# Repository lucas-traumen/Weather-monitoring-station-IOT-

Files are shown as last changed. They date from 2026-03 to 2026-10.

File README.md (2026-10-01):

# Local Weather Monitoring Station

A local weather station for sites where a regional forecast does not describe the microclimate at the sensor. An STM32 node measures the environment, encrypts the reading, and sends it over LoRa. An ESP32-S3 gateway decrypts it, forecasts the temperature two hours ahead, and stores the result in Supabase.

**Team:** Nguyễn Thái Anh (23139002), Lê Đức Trí (23139049)
**Supervisor:** Dr. Huỳnh Thế Thiện, HCMC University of Technology and Education
**Report:** [report/23139002_23139049.pdf](report/23139002_23139049.pdf)

## What it does

Regional stations miss differences caused by vegetation, concrete, elevation, and shielding. This station measures temperature, humidity, pressure, and supply status at the installation point, then keeps that record available when the gateway has Wi-Fi.

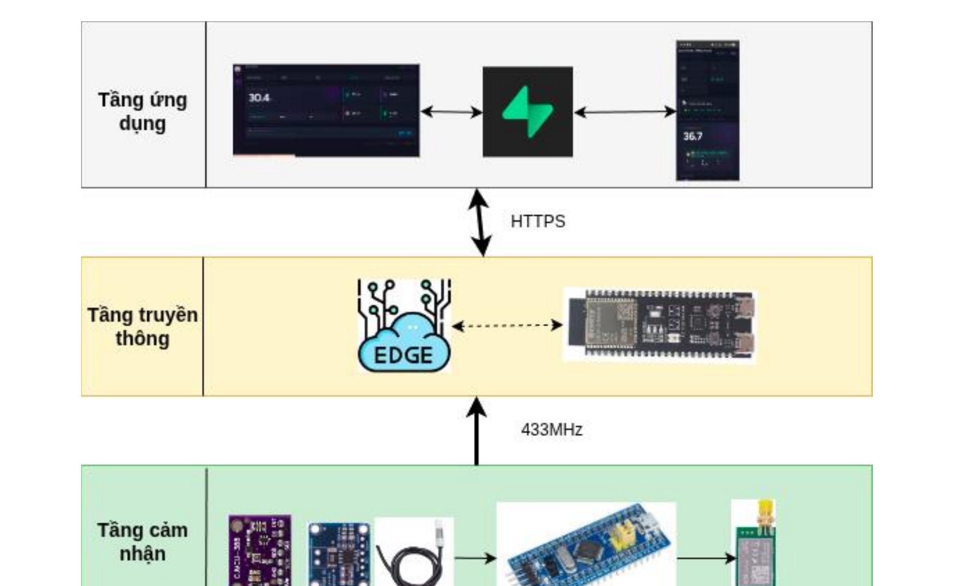
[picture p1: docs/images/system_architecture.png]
Figure 2.1. Three-tier architecture: sensing, communication, application


*Figure 2.1. System architecture. Sensing at 433 MHz, gateway at the edge, application tier over HTTPS.*

| Tier | Role |
| --- | --- |
| STM32F103C8T6 node | Read SHT30, BMP388, and INA219; pack a 10-byte payload; encrypt it; transmit one LoRa frame per cycle |
| ESP32-S3 gateway | Authenticate and decrypt the frame, run the forecast, re-encrypt, and POST to Supabase |
| Supabase | Decrypt in an Edge Function, store rows in PostgreSQL, and serve the dashboard and OTA metadata |

The outdoor link uses ASCON-128a with a 4-byte authentication tag so the frame stays small. The gateway-to-cloud link uses a second key and a 16-byte tag. A leaked LoRa key does not expose the cloud key.

## Run the dashboard

The dashboard is static HTML. It reads rows that the Edge Function has already decrypted.

```bash
cd Software/iot-dashboard
python3 -m http.server 8080
```

Open `http://localhost:8080`. In **Config**, set the Supabase URL and table (`weather_logs`). The browser does not hold the ASCON key.

## Build the firmware

**Gateway** — ESP-IDF project `esp32_gateway`, target ESP32-S3. The managed provisioning component supports ESP-IDF 5.1 through 5.5 and 6.x; use an installed 5.x toolchain unless you have confirmed 6.x.

```bash
cd firmware/esp32
idf.py set-target esp32s3
idf.py build flash monitor
```

**Sensor node** — STM32CubeIDE project generated with STM32CubeMX 6.14.1 and STM32Cube FW_F1 V1.8.7.

```bash
# Open firmware/stm32/node_stm32_ver1 in STM32CubeIDE and build the Debug configuration.
```

There is no top-level Makefile for the STM32 tree.

## How the problems were handled

**Payload size on a small MCU.** AES-GCM is a poor fit for the STM32F103 frame budget. ASCON-128a encrypts the 10-byte payload in software. The LoRa frame is 18 bytes, including a 4-byte tag. The gateway checks that tag before it accepts the sample.

**Radio-on time.** The node does not stream. In each cycle it wakes, checks the schedule, reads the sensors, packs and encrypts the payload, sends one E32 frame at 433 MHz, and returns to standby. Sensors are SHT30, BMP388, and INA219 on I2C. The firmware uses GPIO, UART, RTC, and the independent watchdog.

**Forecast without an external weather API.** The gateway runs a multiple linear regression on temperature, humidity, pressure, and cyclical time features. It writes `predicted_temp_2h` locally. Section 5 gives the error on the deployed model.

**Field updates.** The dashboard hashes the `.bin` with SHA-256, uploads it to the `firmware` bucket, and writes `ota_url`, `ota_seq`, and `ota_sha256` in `device_configs`. The gateway downloads a new sequence, checks the digest, and skips a sequence it has already applied.

**No self-hosted server.** Supabase provides PostgreSQL, Realtime, Storage, and the Edge Function. The browser only sees plaintext that the function has already written.

## Hardware

The node is an STM32F103C8T6 board in a vented enclosure, charged from two solar panels through a CN3791 and a 1S lithium protection circuit.

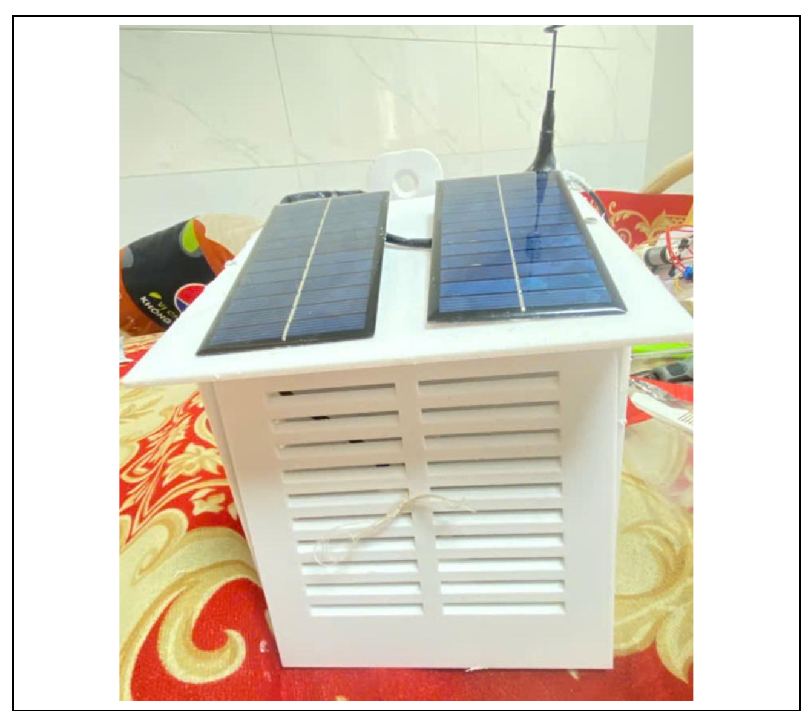
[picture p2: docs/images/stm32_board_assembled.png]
Assembled STM32 sensor node


*Assembled sensor node (Figure 4.3 in the report).*

The gateway is an ESP32-S3 N16R8 (16 MB flash, 8 MB PSRAM) with a LoRa E32 module on UART. PSRAM holds the TLS buffers and the regression coefficients.

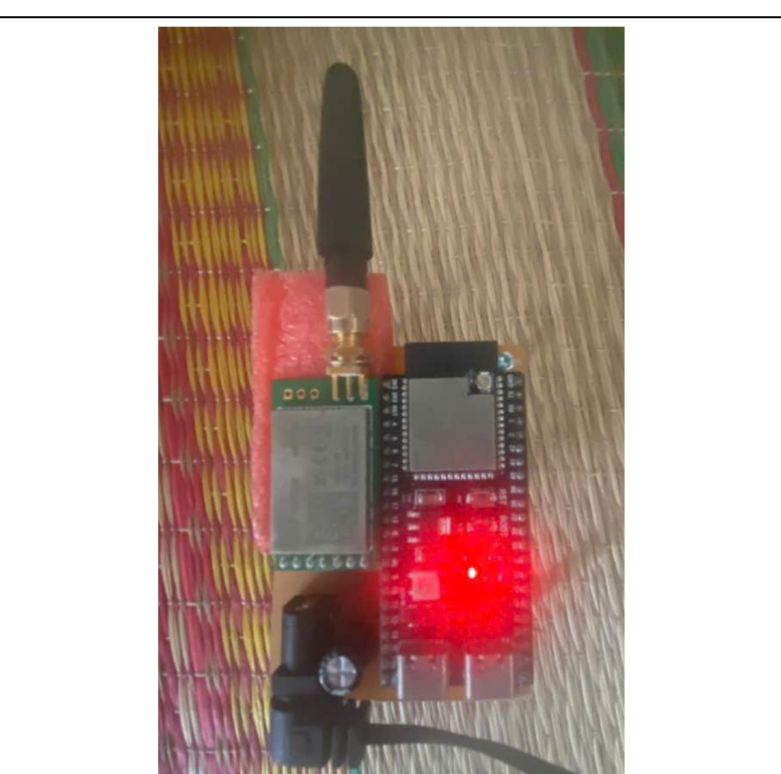
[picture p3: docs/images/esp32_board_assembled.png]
Assembled ESP32-S3 gateway


*Assembled gateway (Figure 4.6 in the report).*

## Results

Evaluation used the deployed system, not a separate simulation. Details and plots are in Chapter 5 of the report.

**HTTPS latency** (Table 5.1), three trials:

| Path | Mean |
| --- | ---: |
| ESP32-S3 to Supabase Edge Function | 4595 ms |
| Web dashboard query to Supabase | 160 ms |

The gateway figure is the time from the start of the HTTPS request until the Edge Function responds, measured on the device. It moves with Wi-Fi and Edge Function load. The dashboard figure is the browser query, not the ingest path.

**ASCON.** The gateway rejects frames whose 4-byte tag does not match. Tampered frames do not enter the database.

**Forecast** (Table 5.2), 1755 paired samples from 13 June 2026 through 28 June 2026:

| Samples | MAE | RMSE | R² | Bias (actual − predicted) |
| ---: | ---: | ---: | ---: | ---: |
| 1755 | 1.84 °C | 2.79 °C | 0.771 | +0.62 °C |

The positive bias means the model tends to forecast low. Error is smaller at night, when temperature changes slowly, and larger between about 10:00 and 15:00. The largest residual in the set is −12.77 °C (forecast 41.10 °C, actual 28.33 °C two hours later, 16 June 2026, 13:00).

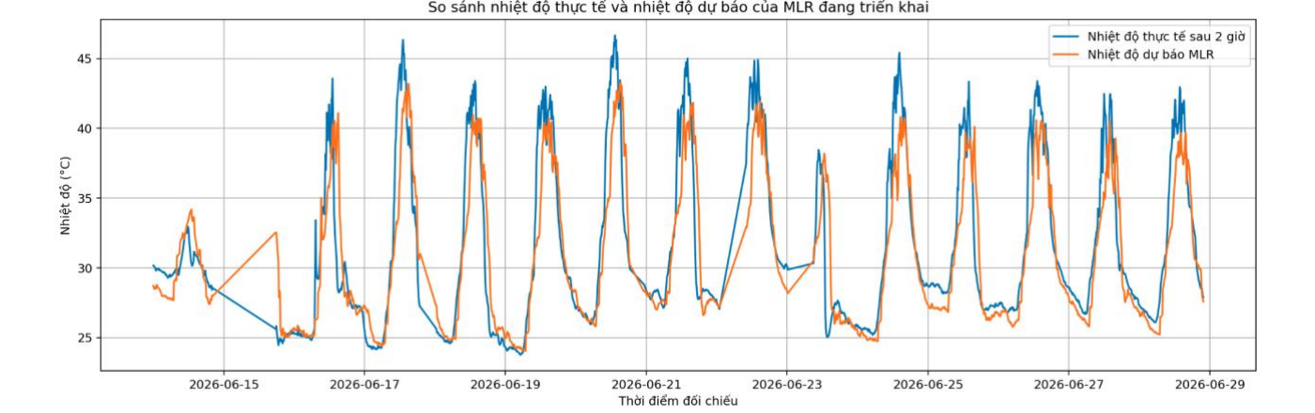
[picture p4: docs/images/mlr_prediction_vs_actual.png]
Predicted and actual temperature


*Predicted temperature and the temperature measured two hours later (Figure 5.18).*

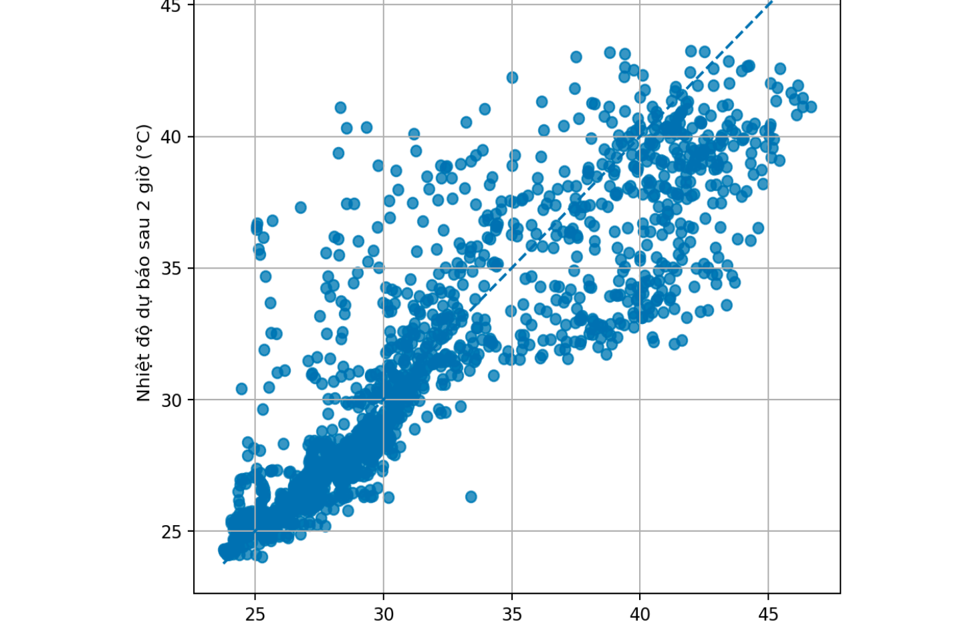
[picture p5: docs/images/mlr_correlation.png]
Correlation of predicted and actual temperature


*Predicted versus actual temperature. The dashed line is y = x (Figure 5.19).*

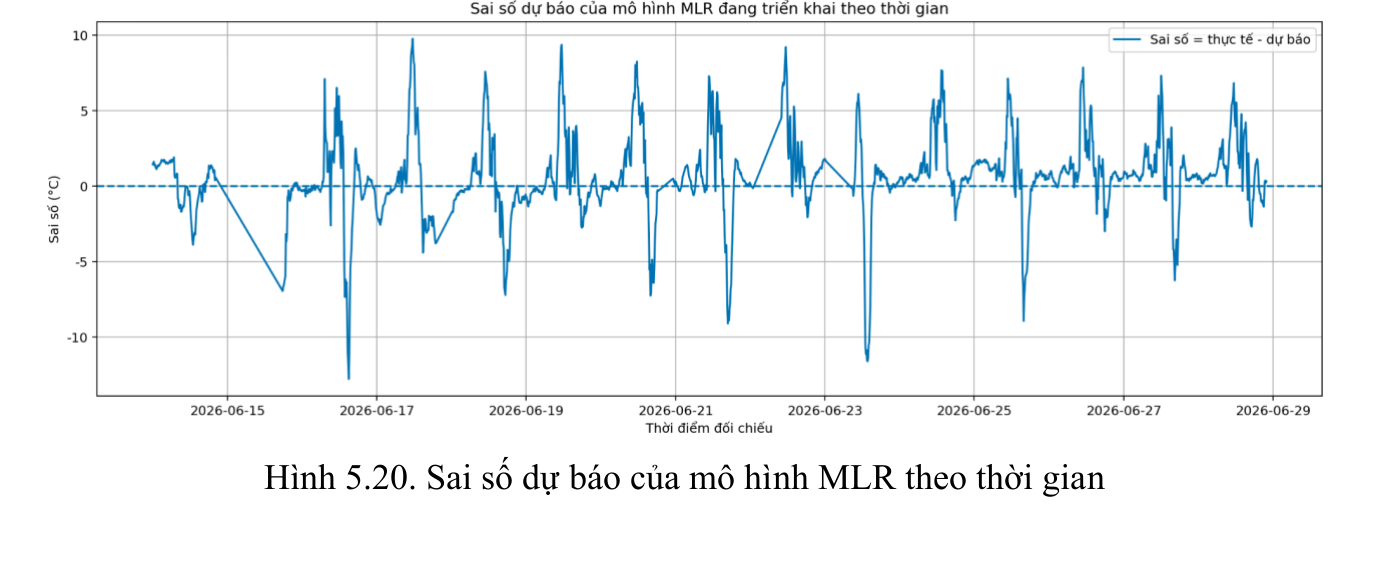
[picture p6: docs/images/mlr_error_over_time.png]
Forecast error over time


*Forecast error over the evaluation window (Figure 5.20).*

**OTA.** Upload from the dashboard, SHA-256 check on the gateway, and flash completed. A repeated sequence number was ignored.

## Repository layout

```
firmware/esp32/     ESP-IDF gateway (FreeRTOS tasks, ASCON, LoRa, MLR)
firmware/stm32/     STM32CubeIDE sensor-node project
Software/iot-dashboard/   Static dashboard (index.html, chart.html)
Hardware/           Schematics and PCB
docs/images/        Figures cropped from the report
report/             Full report (PDF)
```

## Limits

- One sensor node and one gateway were deployed. The frame format can take more nodes; that load was not measured.
- Outdoor enclosure life (UV, heat cycling, rain) was not tested. Long-term solar autonomy was not optimized.
- The regression is a short-horizon reference. It does not replace a meteorological model, and it misses fast daytime swings. A rate-of-change feature and a longer record are the next step.
- Keys are static. Enrollment, rotation, and device identity are out of scope.
- The AEAD associated data is empty. Device ID, frame type, and a counter can be bound there later.

## References

Cited where the design depends on them:

- Dobraunig, C., Eichlseder, M., Grassi, L., et al. (2021). *ASCON v1.2: Lightweight Authenticated Encryption and Hashing*. NIST Lightweight Cryptography Standardization Process. Used for the AEAD on both links (Sections 3 and 5).
- Semtech Corporation. (2023). *LoRa Modulation Basics*, AN1200.22. Used for the 433 MHz E32 link.
- STMicroelectronics. *RM0008 Reference Manual: STM32F10xxx*. Register and peripheral behavior for the F103 firmware (STM32Cube FW_F1 V1.8.7).
- Espressif Systems. *ESP32-S3 Technical Reference Manual* and ESP-IDF programming guide. Gateway tasks, HTTPS, and OTA.
- Supabase. *Realtime, Storage, and Edge Functions*. https://supabase.com/docs. Cloud ingest, dashboard reads, and firmware hosting.

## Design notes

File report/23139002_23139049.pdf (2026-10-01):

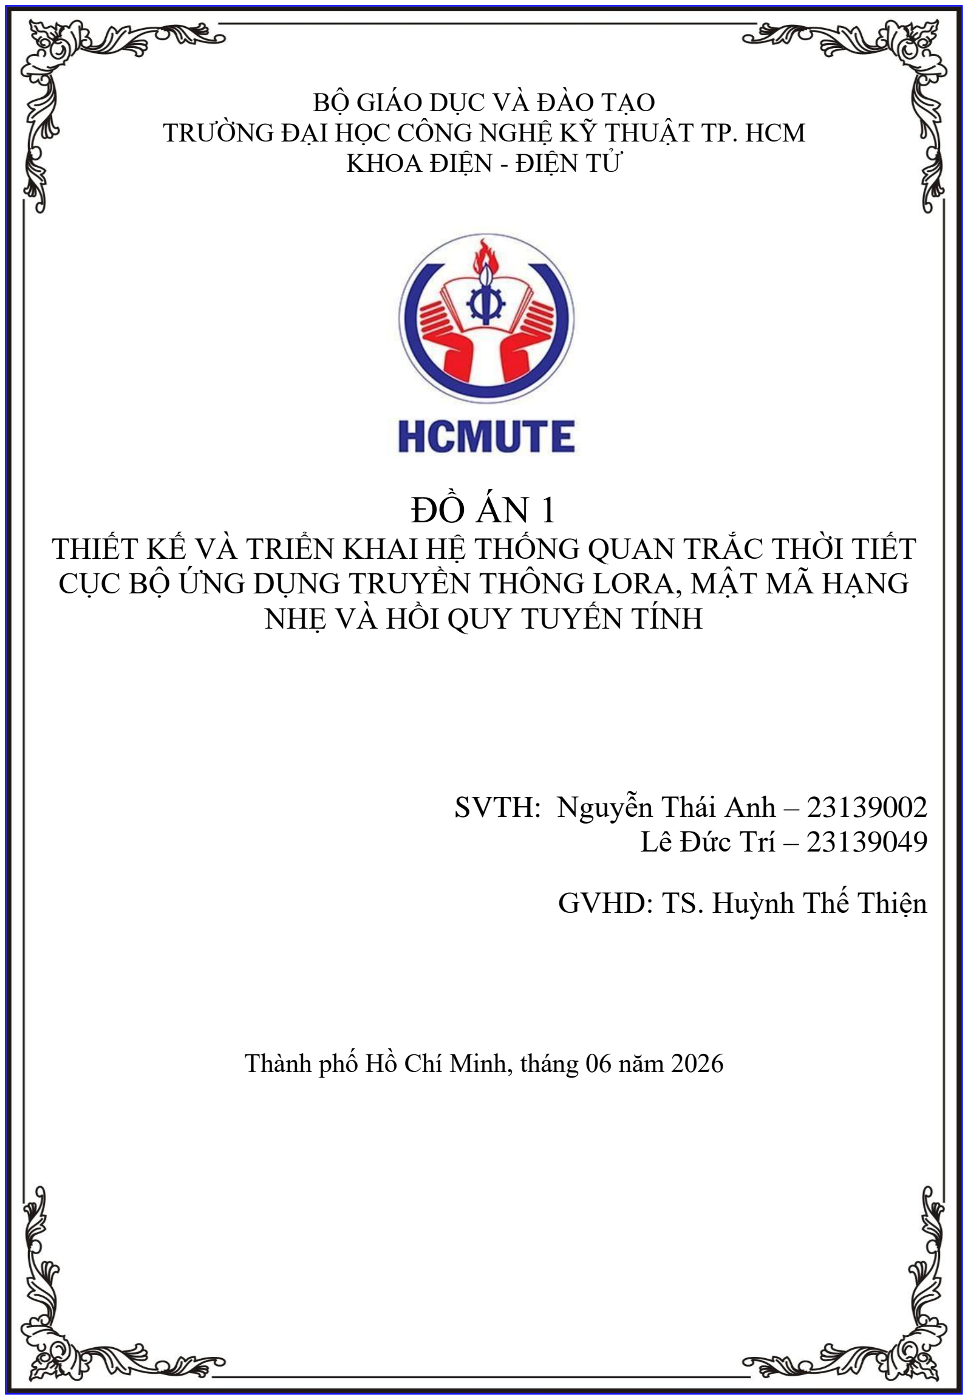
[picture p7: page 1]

BỘ GIÁO DỤC VÀ ĐÀO TẠO
TRƯỜNG ĐẠI HỌC CÔNG NGHỆ KỸ THUẬT TP. HCM KHOA ĐIỆN - ĐIỆN TỬ

## ĐỒ ÁN 1

### THIẾT KẾ VÀ TRIỂN KHAI HỆ THỐNG QUAN TRẮC THỜI TIẾT CỤC BỘ ỨNG DỤNG TRUYỀN THÔNG LORA, MẬT MÃ HẠNG NHẸ VÀ HỒI QUY TUYẾN TÍNH

### SVTH: Nguyễn Thái Anh – 23139002 Lê Đức Trí – 23139049

### GVHD: TS. Huỳnh Thế Thiện

Thành phố Hồ Chí Minh, tháng 06 năm 2026

BỘ GIÁO DỤC VÀ ĐÀO TẠO
TRƯỜNG ĐẠI HỌC CÔNG NGHỆ KỸ THUẬT TP. HCM KHOA ĐIỆN - ĐIỆN TỬ

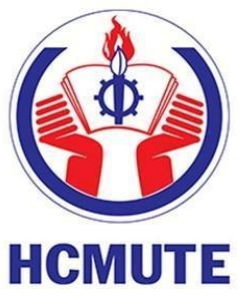
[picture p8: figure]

## ĐỒ ÁN 1

### THIẾT KẾ VÀ TRIỂN KHAI HỆ THỐNG QUAN TRẮC THỜI TIẾT CỤC BỘ ỨNG DỤNG TRUYỀN THÔNG LORA, MẬT MÃ HẠNG NHẸ VÀ HỒI QUY TUYẾN TÍNH

### SVTH: Nguyễn Thái Anh – 23139002 Lê Đức Trí – 23139049

### GVHD: TS. Huỳnh Thế Thiện

Thành phố Hồ Chí Minh, tháng 06 năm 2026

### LỜI CAM ĐOAN

Chúng tôi xin cam đoan đồ án với đề tài "Thiết kế và triển khai hệ thống quan trắc thời tiết cục bộ ứng dụng truyền thông LoRa, mật mã hạng nhẹ và hồi quy tuyến tính" là công trình nghiên cứu, tìm hiểu và thực hiện của riêng nhóm, dưới sự hướng dẫn khoa học của TS. Huỳnh Thế Thiện.
Các số liệu, kết quả trình bày trong báo cáo là hoàn toàn trung thực, được thu thập từ quá trình thực nghiệm thực tế và chưa từng được công bố trong bất kỳ công trình nào khác. Mọi thông tin tham khảo từ các tài liệu, bài báo khoa học, hoặc mã nguồn mở đều được trích dẫn nguồn gốc rõ ràng và tuân thủ đúng quy định về sở hữu trí tuệ.
Nếu có bất kỳ sự gian lận hay sao chép trái phép nào, chúng tôi xin chịu hoàn toàn trách nhiệm trước Hội đồng đánh giá và nhà trường.

Thành phố Hồ Chí Minh, ngày ... tháng 06 năm 2026 Nhóm sinh viên thực hiện
(Ký và ghi rõ họ tên)
Nguyễn Thái Anh | Lê Đức Trí

### LỜI CẢM ƠN

Lời đầu tiên, chúng tôi xin gửi lời cảm ơn chân thành đến Ban Giám hiệu, cùng toàn thể quý thầy cô Khoa Điện - Điện tử, Trường Đại học Công nghệ Kỹ thuật TP. HCM đã tạo môi trường học tập tốt nhất, truyền đạt những kiến thức quý báu và nền tảng chuyên môn vững chắc trong suốt quá trình chúng tôi rèn luyện tại trường.
Đặc biệt, chúng tôi xin bày tỏ lòng biết ơn sâu sắc đến TS. Huỳnh Thế Thiện – người đã trực tiếp hướng dẫn, tận tình chỉ bảo, định hướng nghiên cứu và giải đáp những vướng mắc của nhóm trong suốt thời gian thực hiện đồ án. Những lời khuyên và kinh nghiệm thực tiễn từ thầy là nguồn động lực to lớn giúp chúng tôi vượt qua khó khăn, hoàn thiện đề tài đúng tiến độ và đạt được kết quả như mong muốn.
Mặc dù đã cố gắng hết sức để hoàn thiện đồ án, nhưng do giới hạn về mặt thời gian và kinh nghiệm thực tiễn, thiếu sót là điều không thể tránh khỏi. Chúng tôi rất mong nhận được sự góp ý, chỉ bảo thêm từ quý thầy cô trong Hội đồng đánh giá để đề tài được hoàn thiện hơn và làm hành trang quý giá cho công việc thực tế sau này.
Chúng tôi xin chân thành cảm ơn!

### MỤC LỤC

4.3.2. Firmware Gateway | 89
4.3.3. Triển khai mô hình Multiple Linear Regression trên Gateway | 93
4.4. Triển khai Supabase, Web Dashboard và OTA | 96
4.4.1. Supabase Cloud | 96
4.4.2. Web Dashboard và OTA firmware update | 97
4.5. Tích hợp và vận hành hệ thống sau triển khai | 100
CHƯƠNG 5. THỰC NGHIỆM, KẾT QUẢ VÀ ĐÁNH GIÁ | 102
5.1. Kết quả vận hành STM32 Sensor Node | 102
5.2. Kết quả truyền dữ liệu LoRa và xác thực ASCON | 104
5.3. Kết quả xử lý dữ liệu tại ESP32-S3 Gateway | 106
5.4. Kết quả lưu trữ và hiển thị trên Supabase/Web Dashboard/App | 107
5.5. Đánh giá độ trễ truyền dữ liệu HTTPS | 112
5.6. Đánh giá mô hình dự báo Multiple Linear Regression | 114
5.7. Kết quả cập nhật firmware OTA | 118
5.8. Đánh giá chung và hạn chế | 120
CHƯƠNG 6. KẾT LUẬN VÀ HƯỚNG PHÁT TRIỂN | 122
6.1. Kết luận | 122
6.2. Hướng phát triển | 123
TÀI LIỆU THAM KHẢO | 125

### DANH MỤC TỪ VIẾT TẮT

Từ viết tắt | Tên tiếng Anh đầy đủ | Giải nghĩa tiếng Việt
ADC | Analog-to-Digital Converter | Bộ chuyển đổi tín hiệu tương tự sang số
AEAD | Authenticated Encryption with Associated Data | Mã hóa xác thực có dữ liệu liên kết
API | Application Programming Interface | Giao diện lập trình ứng dụng
BLE | Bluetooth Low Energy | Bluetooth năng lượng thấp
CRC | Cyclic Redundancy Check | Kiểm tra độ dư vòng (Kiểm tra lỗi)
GPIO | General-Purpose Input/Output | Chân tín hiệu vào/ra đa dụng
HTTP | Hypertext Transfer Protocol | Giao thức truyền tải siêu văn bản
HTTPS | Hypertext Transfer Protocol Secure | Giao thức truyền tải siêu văn bản bảo mật
I2C | Inter-Integrated Circuit | Chuẩn giao tiếp dữ liệu nối tiếp đồng bộ

IoT | Internet of Things | Internet vạn vật
LoRa | Long Range | Công nghệ truyền thông vô tuyến tầm xa
MLR | Multiple Linear Regression | Hồi quy tuyến tính đa biến
NIST | National Institute of Standards and Technology | Viện Tiêu chuẩn và Công nghệ Quốc gia Hoa Kỳ
NVS | Non-Volatile Storage | Bộ nhớ lưu trữ không bay hơi
OTA | Over-The-Air | Cập nhật phần mềm (firmware) qua mạng không dây
REST | Representational State Transfer | Kiểu kiến trúc phần mềm cho các hệ thống phân tán
RSSI | Received Signal Strength Indicator | Chỉ số cường độ tín hiệu nhận
RTC | Real-Time Clock | Đồng hồ thời gian thực
RTOS | Real-Time Operating System | Hệ điều hành thời gian thực
SHA | Secure Hash Algorithm | Thuật toán băm an toàn

TLS | Transport Layer Security | Giao thức bảo mật tầng truyền tải
UART | Universal Asynchronous Receiver-Transmitter | Khối truyền nhận dữ liệu nối tiếp bất đồng bộ

### DANH MỤC HÌNH ẢNH

Hình 4.9. Luồng tích hợp vận hành hệ thống sau triển khai | 101
Hình 5.1. Log STM32 Sensor Node trong một chu kỳ đo và truyền dữ liệu | 103
Hình 5.2. Payload 10 byte được tạo tại STM32 Sensor Node | 103
Hình 5.3. Frame LoRa sau khi mã hóa tại STM32 Sensor Node | 103
Hình 5.4. Trạng thái chuyển đổi mode PS/SYNC | 104
Hình 5.5. Log ESP32-S3 Gateway nhận đủ frame LoRa 18 byte | 105
Hình 5.6. Log xác thực và giải mã frame LoRa bằng ASCON key1 | 105
Hình 5.7. Log khôi phục dữ liệu cảm biến tại ESP32-S3 Gateway | 106
Hình 5.8. Log tạo giá trị predicted_temp_2h tại ESP32-S3 Gateway | 107
Hình 5.9. Log tạo payload_key2 trước khi gửi Supabase | 107
Hình 5.10. Bản ghi dữ liệu cảm biến trên bảng weather_logs | 108
Hình 5.11. Bản ghi trạng thái ESP32-S3 Gateway trên Supabase | 109
Hình 5.12. Web Dashboard hiển thị dữ liệu quan trắc mới nhất và biểu đồ lịch sử | 110
Hình 5.13. App giám sát hiển thị dữ liệu quan trắc từ Supabase | 111
Hình 5.14. Trạng thái Gateway và tuyến LoRa trên Web Dashboard | 111
Hình 5.15. Log đo độ trễ HTTPS từ ESP32-S3 Gateway đến Supabase | 112
Hình 5.16. Gói HTTPS đến Supabase được quan sát bằng Wireshark | 113
Hình 5.17. Thời gian phản hồi request Supabase trên Chrome DevTools | 113

Hình 5.18. So sánh nhiệt độ thực tế và nhiệt độ dự báo của mô hình MLR đang triển khai...... 116

Hình 5.19. Tương quan giữa nhiệt độ thực tế và nhiệt độ dự báo | 117
Hình 5.20. Sai số dự báo của mô hình MLR theo thời gian | 117
Hình 5.21. Web Dashboard upload firmware OTA lên Supabase Storage | 119
Hình 5.22. Log ESP32-S3 Gateway cập nhật OTA thành công | 120
Hình 5.23. Log Gateway bỏ qua OTA khi firmware đã được áp dụng trước đó | 120

### DANH MỤC BẢNG

Bảng 4.1. Công cụ và nền tảng triển khai hệ thống | 78
Bảng 5.1. Kết quả đo độ trễ truyền dữ liệu HTTPS | 114

Bảng 5.2. Kết quả đánh giá sai số của mô hình MLR đang triển khai trên ESP32-S3 Gateway 115

Bảng 5.3. Một số mẫu đại diện đối chiếu giữa nhiệt độ dự báo và nhiệt độ thực tế sau 2 giờ ... 116

### MỞ ĐẦU

### 1. Lý do chọn đề tài

Trong những năm gần đây, các hệ thống quan trắc môi trường và thời tiết ngày càng được ứng dụng rộng rãi trong nhiều lĩnh vực như nông nghiệp thông minh, nhà kính, nhà thông minh, giám sát đô thị và nghiên cứu môi trường. Các thông số như nhiệt độ, độ ẩm, áp suất khí quyển và trạng thái nguồn cấp có vai trò quan trọng trong việc theo dõi điều kiện môi trường, đánh giá xu hướng thay đổi và hỗ trợ quá trình ra quyết định trong các hệ thống tự động.

Tuy nhiên, phần lớn dữ liệu thời tiết hiện nay thường được cung cấp bởi các trạm khí tượng ở phạm vi rộng, chẳng hạn như cấp tỉnh, thành phố hoặc khu vực địa lý lớn. Dữ liệu này có giá trị tham khảo tổng quát nhưng chưa phản ánh đầy đủ sự thay đổi môi trường tại từng vị trí cụ thể. Trên thực tế, các yếu tố như mật độ cây xanh, bề mặt bê tông, độ cao, hướng gió, điều kiện che chắn và vị trí lắp đặt có thể tạo ra sự khác biệt đáng kể về nhiệt độ, độ ẩm và áp suất khí quyển giữa các khu vực gần nhau. Hiện tượng này thường được gọi là vi khí hậu.

Do đó, việc xây dựng một hệ thống quan trắc thời tiết cục bộ có khả năng thu thập dữ liệu ngay tại điểm đặt thiết bị là cần thiết. Hệ thống này có thể hỗ trợ giám sát điều kiện môi trường theo thời gian thực, phục vụ các ứng dụng như nhà kính, vườn thông minh, nông nghiệp chính xác hoặc các hệ thống giám sát môi trường quy mô nhỏ.

Bên cạnh yêu cầu thu thập dữ liệu, một hệ thống IoT hiện đại cần đảm bảo khả năng truyền dữ liệu ổn định, có cơ chế bảo vệ dữ liệu và có khả năng mở rộng lên nền tảng lưu trữ hoặc giám sát từ xa. Trong đề tài này, hệ thống được thiết kế theo kiến trúc gồm node cảm biến sử dụng vi điều khiển STM32 và gateway sử dụng ESP32. STM32 đảm nhiệm chức năng thu thập dữ liệu từ cảm biến, xử lý dữ liệu, đóng gói và truyền dữ liệu qua module LoRa E32. ESP32 đóng vai trò gateway, nhận dữ liệu từ LoRa, kiểm tra tính hợp lệ của frame, giải mã dữ liệu, thực hiện dự báo xu hướng nhiệt độ cục bộ và gửi dữ liệu lên nền tảng Cloud thông qua giao thức HTTPS.

Ngoài ra, đề tài còn hướng đến việc tích hợp cơ chế bảo mật dữ liệu bằng thuật toán ASCON-128a theo cơ chế AEAD, viết đầy đủ là Authenticated Encryption with Associated Data. Hệ thống sử dụng hai lớp bảo vệ dữ liệu: tuyến thiết bị đo ngoài trời đến bộ trung tâm Gateway sử dụng ASCON-128a với authentication tag 4 byte để tối ưu kích thước frame LoRa, trong khi tuyến bộ trung tâm Gateway đến Supabase Edge Function sử dụng khóa thứ hai với authentication tag 16 byte để tăng mức xác thực khi truyền dữ liệu lên

Cloud. Bên cạnh đó, dữ liệu thu thập được còn được khai thác bằng mô hình Multiple Linear Regression nhằm khảo sát khả năng dự báo xu hướng nhiệt độ cục bộ trong ngắn hạn.

Việc kết hợp giữa hệ thống nhúng, truyền thông không dây, bảo mật dữ liệu, nền tảng Cloud và học máy giúp đề tài có tính ứng dụng thực tế, đồng thời tạo nền tảng cho các hướng phát triển mở rộng trong tương lai.

### 2. Mục tiêu đề tài

Mục tiêu của đề tài là thiết kế và triển khai một hệ thống quan trắc thời tiết cục bộ sử dụng kiến trúc IoT gồm thiết bị đo ngoài trời và bộ trung tâm Gateway. Hệ thống có khả năng thu thập dữ liệu môi trường, truyền dữ liệu không dây qua LoRa, bảo vệ dữ liệu bằng cơ chế mã hóa xác thực, gửi dữ liệu lên Cloud và khai thác dữ liệu bằng mô hình học máy cơ bản.

Các mục tiêu cụ thể của đề tài bao gồm:

- Thiết kế STM32 Sensor Node để thu thập dữ liệu môi trường và giám sát trạng thái nguồn tại vị trí quan trắc.
- Thiết kế định dạng payload nhỏ gọn và truyền dữ liệu từ Sensor Node đến ESP32-S3 Gateway thông qua LoRa E32.
- Ứng dụng ASCON-128a để mã hóa và xác thực dữ liệu trên các tuyến truyền quan trọng của hệ thống.
- Thiết kế ESP32-S3 Gateway để tiếp nhận, kiểm tra, giải mã, xử lý dữ liệu và gửi dữ liệu lên Supabase Cloud.
- Xây dựng hệ thống lưu trữ, giám sát và hiển thị dữ liệu trên Supabase và Web Dashboard.
- Khảo sát khả năng dự báo xu hướng nhiệt độ cục bộ bằng mô hình Multiple Linear Regression.
- Tích hợp BLE provisioning và OTA firmware update nhằm hỗ trợ cấu hình và vận hành Gateway trong thực tế.

### 3. Đối tượng và phạm vi nghiên cứu

Đối tượng nghiên cứu của đề tài là hệ thống quan trắc thời tiết cục bộ với các thành phần phần cứng và phần mềm cốt lõi bao gồm: vi điều khiển STM32F103C8T6, bộ trung tâm Gateway, hệ thống cảm biến môi trường SHT30, BMP388 và INA219, module truyền thông vô tuyến LoRa E32, thuật toán mật mã hạng nhẹ ASCON-128a, nền tảng Supabase và mô hình học máy Multiple Linear Regression.

Về phạm vi thực hiện, đề tài tập trung giải quyết luồng dữ liệu từ thiết bị đầu cuối đến nền tảng Cloud. Cụ thể, đề tài tiến hành thiết kế kiến trúc tổng thể và phát triển firmware cho cả thiết bị đo ngoài trời lẫn bộ trung tâm Gateway. STM32 thực hiện chu trình thu thập dữ liệu vi khí hậu, kiểm tra lỗi cảm biến, chuyển đổi dữ liệu sang định dạng biểu diễn số nguyên theo hệ số tỉ lệ, mã hóa payload bằng ASCON-128a và truyền frame qua LoRa E32. bộ trung tâm Gateway nhận frame LoRa, kiểm tra authentication tag, giải mã dữ liệu, chuyển đổi dữ liệu về giá trị vật lý, thực hiện dự báo xu hướng nhiệt độ bằng mô hình Multiple Linear Regression và gửi dữ liệu lên Supabase thông qua HTTPS.

Ở tầng Cloud, hệ thống sử dụng Supabase Edge Function để tiếp nhận dữ liệu từ bộ trung tâm Gateway. Payload được mã hóa lại bằng khóa thứ hai trước khi gửi lên Cloud, sau đó Edge Function thực hiện kiểm tra, giải mã và ghi dữ liệu vào PostgreSQL Database. Dữ liệu lưu trữ có thể được sử dụng cho mục đích hiển thị, theo dõi lịch sử, phân tích xu hướng và đánh giá kết quả dự báo.

Trong phạm vi đề tài, hệ thống được triển khai với một node cảm biến STM32 và một gateway ESP32. Mô hình này có thể mở rộng trong tương lai để hỗ trợ nhiều node cảm biến cùng gửi dữ liệu về một gateway hoặc một nền tảng Cloud chung.

### 4. Phương pháp thực hiện

Đề tài được thực hiện theo phương pháp kết hợp giữa nghiên cứu lý thuyết, thiết kế hệ thống, triển khai thực nghiệm và kiểm thử đánh giá. Trước tiên, nhóm tiến hành khảo sát các tài liệu kỹ thuật liên quan đến vi điều khiển STM32, ESP32, cảm biến môi trường, module truyền thông LoRa, thuật toán ASCON-128a, giao thức HTTPS, nền tảng Cloud và mô hình hồi quy tuyến tính đa biến. Từ đó, kiến trúc tổng thể của hệ thống được xây dựng theo mô hình Sensor Node – Gateway – Cloud.

Sau khi xác định kiến trúc hệ thống, các module phần cứng và phần mềm được triển khai theo từng khối chức năng. STM32 được sử dụng để đọc dữ liệu cảm biến, xử lý lỗi, đóng gói payload, mã hóa dữ liệu và truyền frame qua LoRa. ESP32 được sử dụng để nhận dữ liệu từ LoRa, kiểm tra tính hợp lệ của frame, giải mã payload, chuyển đổi dữ liệu về giá trị vật lý, thực hiện mô hình dự báo và gửi dữ liệu lên Supabase Edge Function thông qua HTTPS.

Đối với phần bảo mật, dữ liệu cảm biến sau khi đóng gói được xử lý bằng thuật toán ASCON-128a theo cơ chế AEAD. Ở tuyến STM32 đến ESP32, hệ thống sử dụng authentication tag 4 byte nhằm giảm kích thước frame truyền qua LoRa. Ở tuyến ESP32 đến Cloud, payload được mã hóa lại bằng khóa thứ hai và sử dụng authentication tag 16 byte nhằm tăng mức xác thực khi dữ liệu được gửi lên Supabase Edge Function.

Đối với phần học máy, mô hình Multiple Linear Regression được sử dụng như một mô hình cơ bản để khảo sát khả năng dự báo xu hướng nhiệt độ cục bộ trong ngắn hạn. Mô hình sử dụng các thông số môi trường và thông tin thời gian làm đầu vào để tạo ra giá trị dự báo nhiệt độ trong khoảng thời gian tiếp theo.

Ngoài luồng dữ liệu chính, hệ thống còn triển khai các chức năng hỗ trợ vận hành như BLE provisioning và OTA firmware update. BLE provisioning giúp bộ trung tâm Gateway có thể được cấu hình WiFi trong quá trình triển khai thực tế. OTA cho phép cập nhật firmware từ xa thông qua thông tin ota_url, ota_seq và ota_sha256 được lưu trên Cloud.

Quá trình kiểm thử được định hướng theo mô hình chữ V, trong đó mỗi giai đoạn thiết kế có một giai đoạn kiểm thử tương ứng. Các kiểm thử bao gồm kiểm thử đơn vị, kiểm thử tích hợp, kiểm thử hệ thống, kiểm thử bảo mật, kiểm thử truyền thông, kiểm thử OTA và kiểm thử mô hình học máy.

### 5. Giới hạn nghiên cứu

Trong phạm vi hiện tại, đề tài tập trung vào việc hiện thực hóa luồng thu thập, truyền tải, bảo mật, lưu trữ và khai thác dữ liệu vi khí hậu từ thiết bị đo ngoài trời đến bộ trung tâm Gateway và Supabase Cloud. Hệ thống tận dụng nền tảng Backend-as-a-Service Supabase với PostgreSQL Database, Realtime và Edge Functions để giảm yêu cầu triển khai một máy chủ backend riêng, đồng thời vẫn đảm bảo khả năng lưu trữ và xử lý dữ liệu từ gateway.

Bên cạnh những kết quả đạt được, đề tài vẫn còn một số giới hạn nhất định. Hệ thống chưa đi sâu vào thiết kế cơ khí chống chịu thời tiết ngoài trời, chưa đánh giá độ bền trong môi trường khắc nghiệt và chưa tối ưu hóa hệ thống năng lượng mặt trời cho vận hành độc lập dài hạn. Mô hình dự báo được sử dụng trong đề tài là Multiple Linear Regression, có mục tiêu khảo sát xu hướng nhiệt độ cục bộ ngắn hạn chứ chưa thay thế các mô hình dự báo khí tượng chuyên nghiệp.

Về bảo mật, đề tài tập trung vào mã hóa và xác thực payload cảm biến bằng ASCON-128a. Các vấn đề nâng cao như quản lý khóa động, trao đổi khóa an toàn, chứng thực thiết bị ở quy mô lớn hoặc cơ chế phân quyền phức tạp chưa phải trọng tâm chính của đề tài. Trong cơ chế AEAD, phần Associated Data hiện chưa được sử dụng và được để rỗng; các thông tin như device ID, loại gói tin hoặc phiên truyền có thể được bổ sung vào Associated Data trong các phiên bản phát triển tiếp theo.

Về khả năng mở rộng, phiên bản hiện tại triển khai theo mô hình một thiết bị đo ngoài trời và một bộ trung tâm Gateway. Việc mở rộng thành mạng nhiều node, quản lý nhiều thiết bị, đồng bộ khóa cho nhiều node và tối ưu giao diện dashboard hoàn chỉnh cho người dùng cuối được xem là những hướng phát triển tiếp theo.

### 6. Bố cục báo cáo

Báo cáo được trình bày theo các nội dung chính sau:

Chương 1: Tổng quan đề tài

Chương 2: Cơ sở lý thuyết

Chương 3: Phân tích yêu cầu và thiết kế hệ thống

Chương 4: Triển khai hệ thống

Chương 5: Thực nghiệm, kết quả và đánh giá

Chương 6: Kết luận và hướng phát triển

### CHƯƠNG 1. TỔNG QUAN ĐỀ TÀI

### 1.1. Tổng quan về quan trắc thời tiết cục bộ

Quan trắc thời tiết là quá trình thu thập, theo dõi và phân tích các thông số môi trường như nhiệt độ, độ ẩm, áp suất khí quyển, tốc độ gió, lượng mưa và cường độ ánh sáng. Các dữ liệu này có vai trò quan trọng trong nhiều lĩnh vực như nông nghiệp, giao thông, đô thị thông minh, nhà thông minh và nghiên cứu môi trường.

Các trạm khí tượng truyền thống thường được đặt tại những vị trí cố định và cung cấp dữ liệu cho một khu vực rộng. Tuy nhiên, điều kiện thời tiết tại từng vị trí nhỏ có thể thay đổi đáng kể so với dữ liệu trung bình của toàn khu vực. Ví dụ, nhiệt độ trong khu vực có nhiều bề mặt bê tông có thể cao hơn khu vực có nhiều cây xanh; độ ẩm trong nhà kính có thể khác với môi trường bên ngoài; hoặc điều kiện tại những khu vực có độ che chắn khác nhau có thể tạo ra sự sai lệch đáng kể về thông số môi trường.

Quan trắc thời tiết cục bộ tập trung vào việc đo đạc dữ liệu môi trường tại một vị trí cụ thể. Dữ liệu này phản ánh sát hơn điều kiện thực tế tại nơi lắp đặt thiết bị. Nhờ đó, hệ thống có thể hỗ trợ các ứng dụng yêu cầu dữ liệu theo vị trí, chẳng hạn như điều khiển tưới tiêu trong nông nghiệp, giám sát môi trường nhà kính, cảnh báo điều kiện bất lợi hoặc xây dựng bộ dữ liệu vi khí hậu phục vụ phân tích dài hạn.

Trong đề tài này, hệ thống quan trắc thời tiết cục bộ được xây dựng nhằm thu thập các thông số cơ bản gồm nhiệt độ, độ ẩm, áp suất khí quyển và trạng thái nguồn cấp. Các dữ liệu này được xử lý tại thiết bị đo ngoài trời, truyền về bộ trung tâm Gateway thông qua LoRa, sau đó được gửi lên Cloud để lưu trữ, phân tích và phục vụ khảo sát dự báo xu hướng nhiệt độ cục bộ.

### 1.2. Vai trò của IoT trong quan trắc môi trường

Internet of Things là mô hình kết nối các thiết bị vật lý với mạng Internet nhằm thu thập, trao đổi và xử lý dữ liệu. Trong lĩnh vực quan trắc môi trường, IoT cho phép các cảm biến được triển khai tại nhiều vị trí khác nhau, thu thập dữ liệu theo thời gian thực và gửi về hệ thống trung tâm để lưu trữ, giám sát hoặc phân tích.

So với phương pháp đo thủ công, hệ thống IoT có nhiều ưu điểm. Dữ liệu có thể được thu thập liên tục, giảm phụ thuộc vào con người và cho phép người dùng theo dõi từ xa. Ngoài ra, khi dữ liệu được lưu trữ trong thời gian dài, hệ thống có thể xây dựng các biểu đồ xu hướng, phát hiện bất thường hoặc làm đầu vào cho các mô hình học máy.

Trong hệ thống của đề tài, IoT được áp dụng theo mô hình gồm ba lớp: Sensor Node, Gateway và Cloud. Sensor Node sử dụng STM32 để thu thập dữ liệu từ các cảm biến môi trường. Dữ liệu sau đó được mã hóa, đóng gói và truyền qua LoRa E32 đến bộ trung tâm Gateway. bộ trung tâm Gateway nhận dữ liệu, giải mã, xử lý, thực hiện dự báo xu hướng nhiệt độ và gửi dữ liệu lên Supabase thông qua HTTPS. Tại tầng Cloud, Supabase Edge Function tiếp nhận dữ liệu, giải mã payload được bảo vệ bằng khóa thứ hai và ghi dữ liệu vào PostgreSQL Database.

Việc sử dụng IoT giúp hệ thống có khả năng mở rộng. Trong tương lai, nhiều node cảm biến có thể được triển khai tại nhiều vị trí khác nhau và gửi dữ liệu về cùng một gateway hoặc cùng một nền tảng Cloud. Đây là cơ sở để xây dựng mạng quan trắc vi khí hậu phân tán.

### 1.3. Bài toán thu thập dữ liệu vi khí hậu

Vi khí hậu là tập hợp các điều kiện khí hậu trong một phạm vi nhỏ, có thể khác biệt so với khu vực xung quanh. Các yếu tố tạo nên vi khí hậu bao gồm địa hình, vật liệu bề mặt, cây xanh, nguồn nhiệt, độ thông gió, độ cao và điều kiện che chắn. Vì vậy, dữ liệu khí tượng tổng quát từ các trạm lớn có thể chưa phản ánh đúng điều kiện thực tế tại từng điểm cụ thể.

Bài toán đặt ra là cần xây dựng một hệ thống có khả năng thu thập dữ liệu môi trường ngay tại vị trí cần giám sát. Hệ thống cần đo được các thông số cơ bản như nhiệt độ, độ ẩm và áp suất khí quyển. Ngoài ra, đối với hệ thống hoạt động độc lập hoặc triển khai ngoài trời, việc theo dõi trạng thái nguồn cũng cần thiết để đánh giá tình trạng hoạt động của thiết bị.

Dữ liệu vi khí hậu có giá trị không chỉ ở thời điểm đo hiện tại mà còn ở chuỗi dữ liệu theo thời gian. Khi được lưu trữ liên tục, dữ liệu có thể phản ánh xu hướng biến thiên của môi trường. Ví dụ, sự thay đổi nhiệt độ theo thời điểm trong ngày, độ ẩm môi trường và áp suất khí quyển có thể cung cấp thông tin để khảo sát xu hướng ngắn hạn. Dù hệ thống trong phạm vi đề tài chưa thay thế các mô hình dự báo khí tượng chuyên nghiệp, dữ liệu thu thập được vẫn có thể dùng để khảo sát xu hướng và xây dựng mô hình dự báo đơn giản.

Trong đề tài này, dữ liệu vi khí hậu được thu thập thông qua các cảm biến SHT30, BMP388 và INA219. Dữ liệu ban đầu được đọc dưới dạng số thực, sau đó được chuyển sang định dạng biểu diễn số nguyên theo hệ số tỉ lệ để giảm kích thước payload truyền. Cách tiếp cận này phù hợp với hệ thống nhúng có tài nguyên hạn chế và truyền thông không dây có băng thông thấp.

### 1.4. Vấn đề truyền dữ liệu không dây trong hệ thống IoT

Trong các hệ thống IoT quan trắc môi trường, dữ liệu thường cần được truyền từ node cảm biến đến gateway hoặc server trung tâm. Tùy vào phạm vi triển khai, môi trường lắp đặt và yêu cầu năng lượng, hệ thống có thể sử dụng nhiều công nghệ truyền thông khác nhau như WiFi, Bluetooth, Zigbee, LoRa hoặc mạng di động.

Đối với các node cảm biến đặt ngoài trời hoặc ở vị trí xa gateway, LoRa là một lựa chọn phù hợp do có khả năng truyền xa, tiêu thụ năng lượng thấp và phù hợp với các gói dữ liệu nhỏ. Trong đề tài này, module LoRa E32 được sử dụng để truyền dữ liệu giữa thiết bị đo ngoài trời và bộ trung tâm Gateway. Module này giao tiếp với vi điều khiển thông qua UART, giúp việc tích hợp vào hệ thống nhúng trở nên đơn giản hơn.

Tuy nhiên, truyền dữ liệu không dây cũng đặt ra nhiều vấn đề kỹ thuật. Dữ liệu có thể bị mất gói, nhiễu, sai lệch hoặc nhận không đúng kích thước frame. Do đó, dữ liệu truyền cần có cấu trúc rõ ràng để gateway có thể phân tích và xử lý. Ngoài ra, việc sử dụng frame counter giúp hệ thống theo dõi thứ tự gói tin, hỗ trợ phát hiện mất gói và đóng vai trò đầu vào cho quá trình sinh nonce trong cơ chế mã hóa.

Trong hệ thống của đề tài, payload cảm biến sau khi được đóng gói sẽ được mã hóa bằng ASCON-128a. Frame truyền qua LoRa gồm frame counter, ciphertext và authentication tag 4 byte. Thiết kế này giúp giảm kích thước gói tin, phù hợp với đặc điểm truyền thông LoRa, đồng thời vẫn hỗ trợ kiểm tra tính hợp lệ của dữ liệu khi bộ trung tâm Gateway nhận frame.

Trong quá trình thử nghiệm, frame counter được vận hành theo từng phiên hệ thống. Khi cần đưa hệ thống về trạng thái ban đầu, toàn bộ phiên thử nghiệm sẽ được reset đồng bộ, bao gồmthiết bị đo ngoài trời, bộ trung tâm Gateway và dữ liệu thử nghiệm trên Cloud. Cách làm này giúp đảm bảo frame counter bắt đầu lại từ giá trị ban đầu một cách nhất quán trong môi trường demo và kiểm thử.

### 1.5. Vấn đề bảo mật dữ liệu cảm biến

Dữ liệu trong hệ thống IoT thường được truyền qua môi trường không dây nên có nguy cơ bị nghe lén, sửa đổi hoặc giả mạo. Đối với các hệ thống quan trắc môi trường, nhiều người có thể cho rằng dữ liệu cảm biến không quá nhạy cảm. Tuy nhiên, khi hệ thống được mở rộng cho các ứng dụng nông nghiệp, cảnh báo môi trường hoặc điều khiển tự động, dữ liệu sai lệch có thể dẫn đến các quyết định điều khiển không chính xác.

Bảo mật dữ liệu cảm biến trong hệ thống IoT không chỉ bao gồm mã hóa nội dung dữ liệu mà còn cần đảm bảo tính toàn vẹn và xác thực. Nếu một frame bị thay đổi trong quá trình truyền, gateway cần phát hiện và loại bỏ frame đó thay vì sử dụng dữ liệu sai. Vì vậy, cơ chế mã hóa xác thực là phù hợp cho hệ thống truyền dữ liệu cảm biến qua môi trường không dây.

Trong đề tài này, thuật toán ASCON-128a được sử dụng theo cơ chế AEAD, viết đầy đủ là Authenticated Encryption with Associated Data. Cơ chế này cho phép hệ thống vừa mã hóa payload cảm biến, vừa tạo authentication tag để kiểm tra tính toàn vẹn và tính hợp lệ của dữ liệu. Khi bộ trung tâm Gateway nhận frame, hệ thống kiểm tra authentication tag trước khi chấp nhận và giải mã dữ liệu. Nếu tag không hợp lệ, frame sẽ bị loại bỏ.

Hệ thống sử dụng hai tuyến bảo vệ dữ liệu. Ở tuyến thiết bị đo ngoài trời đến bộ trung tâm Gateway, payload cảm biến được mã hóa bằng khóa thứ nhất và sử dụng authentication tag 4 byte nhằm tối ưu kích thước frame LoRa. Ở tuyến bộ trung tâm Gateway đến Supabase Edge Function, payload được mã hóa lại bằng khóa thứ hai và sử dụng authentication tag 16 byte nhằm tăng mức xác thực khi truyền dữ liệu lên Cloud.

Trong phạm vi đề tài, phần Associated Data của cơ chế AEAD chưa được sử dụng và được để rỗng. Điều này có nghĩa là hệ thống tập trung mã hóa và xác thực trực tiếp phần payload cảm biến. Các hướng mở rộng như bổ sung device ID, loại gói tin, phiên truyền hoặc thông tin định tuyến vào Associated Data có thể được nghiên cứu trong các phiên bản phát triển tiếp theo.

Các vấn đề nâng cao như quản lý khóa động, trao đổi khóa an toàn, chứng thực thiết bị ở quy mô lớn hoặc đánh giá an toàn ở mức sản phẩm thương mại chưa phải trọng tâm chính của đề tài.

### 1.6. Vai trò của học máy trong dự báo xu hướng nhiệt độ cục bộ

Học máy là một hướng tiếp cận cho phép hệ thống khai thác dữ liệu lịch sử để tìm ra mối quan hệ giữa các biến đầu vào và giá trị cần dự báo. Trong bài toán quan trắc thời tiết cục bộ, dữ liệu như nhiệt độ, độ ẩm và áp suất khí quyển có thể được lưu trữ theo thời gian để phục vụ phân tích xu hướng.

Các mô hình dự báo thời tiết chuyên nghiệp thường rất phức tạp và sử dụng nhiều nguồn dữ liệu khác nhau. Tuy nhiên, trong phạm vi một hệ thống IoT cục bộ, mục tiêu không phải là thay thế mô hình khí tượng lớn mà là khai thác dữ liệu đo tại điểm đặt để khảo sát xu hướng ngắn hạn hoặc hỗ trợ cảnh báo đơn giản. Đây là hướng tiếp cận phù hợp với các ứng dụng như nhà kính, vườn thông minh hoặc hệ thống giám sát môi trường tại chỗ.

Trong đề tài này, mô hình Multiple Linear Regression được sử dụng như một mô hình học máy cơ bản nhằm khảo sát khả năng dự báo xu hướng nhiệt độ cục bộ trong ngắn hạn. Mô hình có ưu điểm là đơn giản, dễ triển khai, dễ giải thích và phù hợp để đánh giá bước đầu mối quan hệ giữa các biến môi trường.

Dữ liệu đầu vào của mô hình gồm nhiệt độ, độ ẩm, áp suất khí quyển và các đặc trưng thời gian như giờ trong ngày hoặc ngày trong năm. Giá trị đầu ra là nhiệt độ dự báo trong khoảng thời gian tiếp theo, cụ thể là dự báo nhiệt độ sau 2 giờ. Kết quả của mô hình Multiple Linear Regression giúp đánh giá tiềm năng khai thác bộ dữ liệu vi khí hậu thu thập được từ hệ thống IoT.

### 1.7. Giải pháp đề xuất của đề tài

Từ các vấn đề đã phân tích, đề tài đề xuất xây dựng một hệ thống quan trắc thời tiết cục bộ theo kiến trúc gồm ba lớp chính: lớp node cảm biến, lớp gateway và lớp xử lý/lưu trữ dữ liệu trên Cloud.

Ở lớp node cảm biến, STM32F103C8T6 được sử dụng để giao tiếp với các cảm biến môi trường. Cảm biến SHT30 đo nhiệt độ và độ ẩm, cảm biến BMP388 đo áp suất khí quyển, cảm biến INA219 theo dõi trạng thái nguồn. Dữ liệu sau khi đọc từ cảm biến được xử lý, kiểm tra lỗi và đóng gói thành payload nhỏ gọn theo định dạng biểu diễn số nguyên theo hệ số tỉ lệ.

Ở lớp truyền thông, module LoRa E32 được sử dụng để truyền dữ liệu không dây từ thiết bị đo ngoài trời đến bộ trung tâm Gateway. Frame truyền được thiết kế gồm frame counter, ciphertext và authentication tag 4 byte. Việc sử dụng frame counter giúp theo dõi thứ tự gói tin và hỗ trợ quá trình sinh nonce, trong khi ciphertext và tag giúp bảo vệ dữ liệu bằng ASCON-128a.

Ở lớp gateway, ESP32 nhận dữ liệu từ module LoRa E32, kiểm tra tính hợp lệ của frame, giải mã payload và chuyển đổi các giá trị f về giá trị vật lý ban đầu. Sau đó, ESP32 thực hiện mô hình Multiple Linear Regression để dự báo xu hướng nhiệt độ cục bộ trong ngắn hạn. Trước khi gửi dữ liệu lên Cloud, ESP32 mã hóa lại payload bằng khóa thứ hai và sử dụng authentication tag 16 byte. Dữ liệu sau đó được gửi đến Supabase Edge Function thông qua HTTPS.

Ở lớp Cloud, Supabase Edge Function tiếp nhận dữ liệu từ bộ trung tâm Gateway, kiểm tra token thiết bị, giải mã payload và ghi dữ liệu vào PostgreSQL Database. Supabase Realtime có thể được sử dụng để hỗ trợ cập nhật dữ liệu cho giao diện giám sát. Ngoài dữ liệu cảm biến, hệ thống còn lưu trạng thái gateway như thời điểm nhận gói LoRa gần nhất, phiên bản firmware, trạng thái kết nối và thông tin phục vụ OTA.

Ngoài luồng dữ liệu chính, bộ trung tâm Gateway còn được thiết kế thêm các cơ chế hỗ trợ vận hành. BLE provisioning được sử dụng để cấu hình WiFi theo hướng production: khi chưa có WiFi trong NVS hoặc credential cũ không còn hợp lệ, thiết bị sẽ mở BLE provisioning và chờ người dùng nhập WiFi mới; hệ thống không sử dụng fallback hardcoded WiFi trong vận hành chính thức. Cơ chế OTA firmware update cho phép cập nhật firmware từ xa thông qua thông tin ota_url, ota_seq và ota_sha256. Trong đó, ota_seq giúp kiểm tra thứ tự bản cập nhật, còn SHA-256 giúp tránh cập nhật lặp lại cùng một firmware.

Giải pháp đề xuất có ưu điểm là phân tách rõ ràng giữa nhiệm vụ thu thập dữ liệu và nhiệm vụ giao tiếp mạng. STM32 tập trung vào xử lý cảm biến, đóng gói và truyền dữ liệu nhúng, trong khi ESP32 đảm nhiệm vai trò gateway, bảo mật tuyến Cloud, dự báo xu hướng nhiệt độ, cấu hình WiFi, OTA và kết nối với hệ thống bên ngoài. Kiến trúc này giúp hệ thống dễ mở rộng, dễ kiểm thử và phù hợp với định hướng phát triển các hệ thống IoT quan trắc môi trường.

### CHƯƠNG 2. CƠ SỞ LÝ THUYẾT

### 2.1. Tổng quan về kiến trúc IoT

Internet of Things, viết tắt là IoT, là mô hình trong đó các thiết bị vật lý được gắn cảm biến, bộ xử lý, phần mềm và khả năng kết nối mạng để có thể thu thập, trao đổi và xử lý dữ liệu. Trong các hệ thống IoT, thiết bị không chỉ hoạt động độc lập mà còn có khả năng kết nối với các thiết bị khác hoặc với hệ thống trung tâm thông qua mạng truyền thông. Nhờ đó, dữ liệu từ môi trường thực có thể được số hóa, truyền đi, lưu trữ và khai thác cho các mục đích giám sát, phân tích hoặc điều khiển.

Một hệ thống IoT thường được xây dựng theo kiến trúc nhiều tầng. Cách tổ chức theo tầng giúp chia nhỏ hệ thống thành các khối chức năng rõ ràng, giảm độ phức tạp và thuận tiện cho việc mở rộng. Mặc dù các tài liệu có thể mô tả kiến trúc IoT theo nhiều mô hình khác nhau, một cách phân chia phổ biến là gồm tầng thiết bị cảm nhận, tầng truyền thông hoặc gateway, và tầng ứng dụng hoặc cloud. Tầng thiết bị cảm nhận có nhiệm vụ thu thập dữ liệu từ môi trường thông qua cảm biến. Tầng truyền thông đảm nhiệm việc chuyển dữ liệu từ thiết bị lên hệ thống trung tâm. Tầng ứng dụng hoặc cloud đảm nhiệm lưu trữ, xử lý, hiển thị và khai thác dữ liệu [1].

Ở tầng thiết bị, hệ thống thường bao gồm các sensor node. Sensor node là thiết bị nhúng có nhiệm vụ đọc dữ liệu từ cảm biến, xử lý sơ bộ dữ liệu và truyền dữ liệu ra ngoài. Tùy theo yêu cầu ứng dụng, sensor node có thể sử dụng vi điều khiển công suất thấp, cảm biến số, cảm biến tương tự, module truyền thông và nguồn pin. Trong các hệ thống quan trắc môi trường, sensor node thường đo các đại lượng như nhiệt độ, độ ẩm, áp suất khí quyển, ánh sáng, nồng độ khí hoặc trạng thái nguồn cấp.

Tầng truyền thông đóng vai trò đưa dữ liệu từ sensor node đến nơi xử lý trung tâm. Tùy vào phạm vi truyền, băng thông, năng lượng và môi trường triển khai, tầng truyền thông có thể sử dụng nhiều công nghệ khác nhau như WiFi, Bluetooth Low Energy, Zigbee, LoRa, Ethernet hoặc mạng di động. Trong nhiều hệ thống IoT, gateway được dùng như một thiết bị trung gian giữa sensor node và Internet. Gateway có thể nhận dữ liệu từ các node thông qua giao tiếp cục bộ hoặc truyền thông vô tuyến tầm xa, sau đó chuyển tiếp dữ liệu lên server hoặc cloud bằng WiFi, Ethernet hoặc mạng di động.

Tầng cloud hoặc server chịu trách nhiệm tiếp nhận, lưu trữ và xử lý dữ liệu. Dữ liệu IoT thường có tính thời gian, vì mỗi bản ghi gắn với thời điểm đo hoặc thời điểm nhận. Do đó, tầng cloud cần hỗ trợ lưu trữ dữ liệu lịch sử, truy vấn theo thời gian, giám sát trạng thái thiết bị và cung cấp dữ liệu cho giao diện người dùng. Ngoài ra, tầng cloud còn có thể thực hiện các chức năng nâng cao như phân tích xu hướng, phát hiện bất thường, cảnh báo hoặc cập nhật cấu hình thiết bị từ xa.

Ưu điểm của kiến trúc nhiều tầng là mỗi tầng có thể tập trung vào một nhóm nhiệm vụ riêng. Tầng cảm biến tập trung vào việc đo đạc và tiết kiệm năng lượng. Tầng gateway tập trung vào truyền thông, xử lý trung gian và chuyển đổi giao thức. Tầng cloud tập trung vào lưu trữ, phân tích và giao diện người dùng. Nhờ sự phân tách này, hệ thống có thể dễ dàng mở rộng từ một node lên nhiều node, thay đổi công nghệ truyền thông hoặc thay đổi nền tảng lưu trữ mà không nhất thiết phải thiết kế lại toàn bộ hệ thống.

Trong đề tài này, kiến trúc IoT nhiều tầng được dùng làm nền tảng để xây dựng hệ thống quan trắc thời tiết cục bộ. Phần phân tích chi tiết cách chia nhiệm vụ giữa các thành phần cụ thể sẽ được trình bày ở Chương 3.

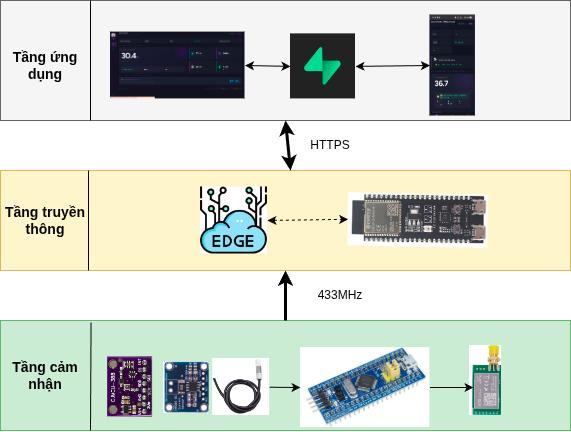
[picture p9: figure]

Hình 2.1. Kiến trúc tổng thể hệ thống quan trắc thời tiết cục bộ IoT

### 2.2. Vi điều khiển STM32F103C8T6

Vi điều khiển là một mạch tích hợp bao gồm lõi xử lý, bộ nhớ và các ngoại vi vào/ra trên cùng một chip. Khác với vi xử lý đa dụng cần nhiều thành phần bên ngoài để tạo thành một hệ thống hoàn chỉnh, vi điều khiển được thiết kế để điều khiển trực tiếp các thiết bị ngoại vi trong hệ thống nhúng. Vì vậy, vi điều khiển thường được sử dụng trong các ứng dụng cần kích thước nhỏ, chi phí thấp, tiêu thụ điện năng thấp và khả năng phản hồi thời gian thực.

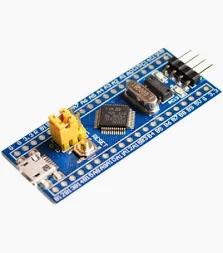
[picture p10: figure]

Hình 2.2. Vi điều khiển STM32F103C8T6

STM32F103C8T6 là vi điều khiển thuộc dòng STM32F1 của STMicroelectronics. Dòng STM32F103 thuộc nhóm mainstream performance line, sử dụng lõi Arm Cortex-M3 32 bit. Theo tài liệu của STMicroelectronics, dòng STM32F103 medium-density performance line sử dụng lõi Arm Cortex-M3 hoạt động ở tần số tối đa 72 MHz, tích hợp bộ nhớ Flash, SRAM và nhiều ngoại vi như ADC, timer, I2C, SPI, USART, USB và CAN [2]. Với mã STM32F103C8, chip thường được biết đến với 64 KB Flash và 20 KB SRAM, phù hợp cho nhiều ứng dụng điều khiển nhúng vừa và nhỏ.

Lõi Arm Cortex-M3 được thiết kế cho các hệ thống nhúng cần hiệu năng tốt nhưng vẫn giữ mức tiêu thụ năng lượng hợp lý. Đây là lõi xử lý 32 bit theo kiến trúc RISC, hỗ trợ tập lệnh Thumb-2, cơ chế ngắt lồng nhau NVIC và các tính năng phục vụ xử lý thời gian thực. So với các vi điều khiển 8 bit truyền thống, vi điều khiển 32 bit như STM32F103 cho phép xử lý dữ liệu nhanh hơn, quản lý ngoại vi phức tạp hơn và hỗ trợ tốt hơn cho các giao thức truyền thông hiện đại.

Một đặc điểm quan trọng của STM32F103C8T6 là hệ thống ngoại vi đa dạng. Các ngoại vi như I2C, SPI và USART cho phép vi điều khiển giao tiếp với nhiều cảm biến hoặc module truyền thông. ADC tích hợp cho phép đọc tín hiệu tương tự. Timer hỗ trợ tạo xung, đo thời gian, điều khiển PWM hoặc xử lý các tác vụ định kỳ. DMA giúp truyền dữ liệu giữa bộ nhớ và ngoại vi mà không cần CPU can thiệp liên tục, từ đó giảm tải cho lõi xử lý trong một số ứng dụng.

Trong hệ thống cảm biến, STM32F103C8T6 phù hợp với vai trò bộ điều khiển trung tâm của sensor node. Vi điều khiển có thể đọc dữ liệu từ cảm biến, kiểm tra lỗi truyền thông, thực hiện xử lý sơ bộ và gửi dữ liệu đến module truyền thông. Nhờ có nhiều ngoại vi giao tiếp, STM32 có thể kết nối đồng thời với các cảm biến sử dụng I2C và module truyền thông sử dụng UART. Đây là lý do STM32F103C8T6 thường được sử dụng trong các hệ thống đo lường, giám sát và điều khiển nhúng.

### 2.3. ESP32-S3 và FreeRTOS

ESP32-S3 là vi điều khiển tích hợp kết nối không dây của Espressif Systems, thuộc họ ESP32-S. Khác với các vi điều khiển chỉ tập trung vào đọc cảm biến hoặc điều khiển ngoại vi, ESP32-S3 được thiết kế cho các ứng dụng IoT cần kết nối mạng, xử lý dữ liệu và giao tiếp với các dịch vụ cloud. Theo Espressif, ESP32-S3 sử dụng vi xử lý dual-core Xtensa LX7, có thể hoạt động ở tần số 240 MHz, tích hợp 512 KB SRAM, WiFi 2.4 GHz chuẩn 802.11 b/g/n và Bluetooth 5 Low Energy [3].

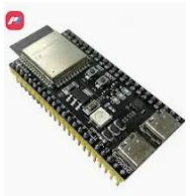
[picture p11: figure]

Hình 2.3. Vi điều khiển ESP32-S3 N16R8

Việc tích hợp WiFi và Bluetooth Low Energy giúp ESP32-S3 phù hợp với vai trò thiết bị kết nối mạng hoặc gateway IoT. WiFi cho phép thiết bị truyền dữ liệu lên Internet thông qua router hoặc access point. Bluetooth Low Energy phù hợp cho các chức năng cấu hình cục bộ, trao đổi dữ liệu khoảng cách ngắn hoặc provisioning. Ngoài ra, ESP32-S3 còn có nhiều ngoại vi như SPI, I2C, UART, I2S, PWM, ADC, RMT và các GPIO lập trình được, giúp chip có thể giao tiếp với nhiều loại cảm biến và module ngoại vi [3].

ESP32-S3 được phát triển trong hệ sinh thái ESP-IDF. ESP-IDF là framework chính thức của Espressif dùng để phát triển firmware cho các chip ESP32. Framework này cung cấp driver ngoại vi, TCP/IP stack, WiFi stack, Bluetooth stack, HTTP client, TLS, OTA, NVS và nhiều thành phần phần mềm khác. Nhờ đó, lập trình viên có thể xây dựng ứng dụng IoT phức tạp mà không phải tự triển khai toàn bộ các tầng phần mềm thấp.

Một thành phần quan trọng trong ESP-IDF là FreeRTOS. FreeRTOS là hệ điều hành thời gian thực mã nguồn mở, được tích hợp vào ESP-IDF như một thành phần lõi. Theo tài liệu Espressif, các ứng dụng ESP-IDF và nhiều thành phần trong ESP-IDF được xây dựng dựa trên FreeRTOS; ESP-IDF cũng cung cấp các triển khai FreeRTOS để hỗ trợ SMP trên các chip ESP đa lõi [4]. FreeRTOS cho phép chương trình được chia thành nhiều task, mỗi task đảm nhiệm một chức năng riêng và được hệ điều hành lập lịch thực thi.

Trong một hệ thống gateway IoT, FreeRTOS giúp tổ chức phần mềm rõ ràng hơn. Các tác vụ như nhận dữ liệu, xử lý dữ liệu, gửi dữ liệu lên mạng, cập nhật trạng thái, kiểm tra cấu hình hoặc thực hiện OTA có thể được tách thành các task riêng. Ngoài task, FreeRTOS còn cung cấp queue, semaphore, mutex, timer và event group. Các cơ chế này giúp các task trao đổi dữ liệu, đồng bộ tài nguyên và tránh xung đột khi nhiều tác vụ cùng truy cập một thành phần phần cứng hoặc phần mềm.

So với mô hình lập trình vòng lặp đơn giản, mô hình dùng FreeRTOS phù hợp hơn với các gateway có nhiều chức năng chạy đồng thời. Tuy nhiên, việc sử dụng RTOS cũng yêu cầu thiết kế cẩn thận về bộ nhớ stack, độ ưu tiên task, hàng đợi dữ liệu và tài nguyên dùng chung. Nếu phân chia task không hợp lý, hệ thống có thể gặp lỗi tràn stack, nghẽn hàng đợi, deadlock hoặc mất dữ liệu khi một task xử lý quá lâu. Vì vậy, trong Chương 3 và Chương 4, việc tổ chức phần mềm trên ESP32-S3 cần được trình bày như một phần của thiết kế và triển khai hệ thống.

### 2.4. Chuẩn giao tiếp I2C

I2C, viết đầy đủ là Inter-Integrated Circuit, là chuẩn giao tiếp nối tiếp đồng bộ được phát triển ban đầu bởi Philips Semiconductors, nay thuộc NXP Semiconductors. I2C được thiết kế để các vi mạch trong cùng một hệ thống có thể trao đổi dữ liệu với nhau thông qua một bus đơn giản. Theo đặc tả UM10204 của NXP, I2C sử dụng hai đường tín hiệu chính là SDA và SCL. SDA là đường dữ liệu nối tiếp, còn SCL là đường xung clock dùng để đồng bộ quá trình truyền nhận dữ liệu [5].

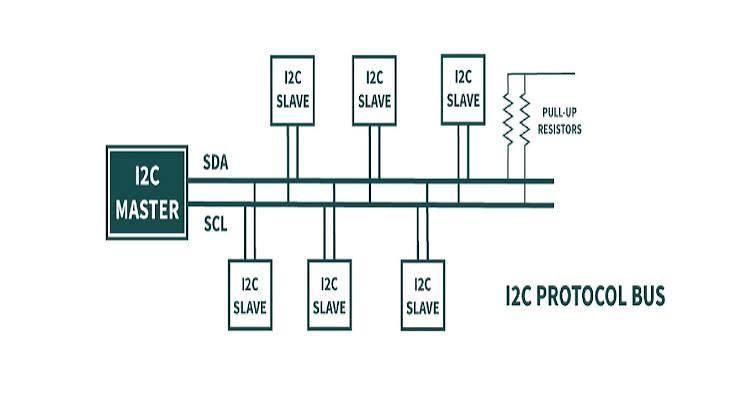
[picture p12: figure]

Hình 2.4. Cấu trúc bus I2C giữa Master và các Slave

Một đặc điểm quan trọng của I2C là nhiều thiết bị có thể cùng kết nối trên một bus. Thiết bị điều khiển quá trình truyền được gọi là controller, còn thiết bị được truy cập gọi là target. Trong các tài liệu cũ, hai vai trò này thường được gọi là master và slave. Controller tạo xung clock, phát điều kiện START, gửi địa chỉ target, xác định hướng đọc hoặc ghi, và phát điều kiện STOP để kết thúc giao dịch. Mỗi target trên bus có một địa chỉ riêng, thường là địa chỉ 7 bit, giúp controller chọn đúng thiết bị cần giao tiếp.

Về mặt điện, hai đường SDA và SCL của I2C thường sử dụng cấu trúc open-drain hoặc open-collector. Điều này có nghĩa là thiết bị chỉ chủ động kéo đường tín hiệu xuống mức thấp, còn mức cao được tạo bởi điện trở kéo lên. Theo tài liệu NXP, cả SDA và SCL là các đường hai chiều, được nối với nguồn dương thông qua điện trở kéo lên [5]. Nhờ đặc tính này, nhiều thiết bị có thể dùng chung bus mà không gây xung đột mức cao trực tiếp, đồng thời hỗ trợ các cơ chế như arbitration và clock stretching.

Một giao dịch I2C bắt đầu bằng điều kiện START. Điều kiện START được định nghĩa là sự chuyển mức từ cao xuống thấp trên SDA trong khi SCL đang ở mức cao. Sau START, controller gửi byte địa chỉ gồm 7 bit địa chỉ và 1 bit R/W để xác định thao tác đọc hoặc ghi. Nếu target nhận đúng địa chỉ, nó phản hồi bằng ACK. Sau đó, dữ liệu được truyền theo từng byte 8 bit. Theo đặc tả I2C, mỗi byte truyền trên SDA có độ dài 8 bit và phải được theo sau bởi một bit ACK hoặc NACK. Giao dịch kết thúc bằng điều kiện STOP, là sự chuyển mức từ thấp lên cao trên SDA trong khi SCL đang ở mức cao [5].

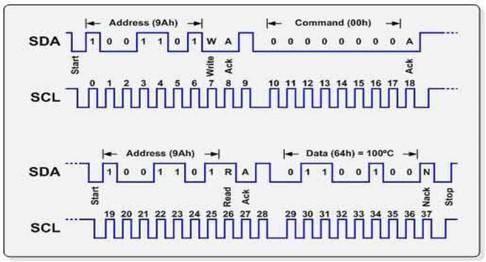
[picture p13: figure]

Hình 2.5. Trình tự truyền nhận dữ liệu trên bus I2C

I2C hỗ trợ nhiều tốc độ truyền khác nhau như Standard-mode, Fast-mode, Fast-mode Plus và High-speed mode. Tốc độ thực tế phụ thuộc vào thiết bị, điện dung bus, giá trị điện trở kéo lên, chiều dài dây và môi trường nhiễu. Vì I2C là bus dùng đường tín hiệu kéo lên thụ động, cạnh lên của tín hiệu phụ thuộc nhiều vào hằng số thời gian RC của bus. Nếu dây quá dài, điện dung lớn hoặc điện trở kéo lên không phù hợp, tín hiệu có thể bị méo, làm giảm độ tin cậy truyền thông.

Trong các hệ thống cảm biến, I2C được sử dụng phổ biến vì chỉ cần hai dây tín hiệu để kết nối nhiều cảm biến số. Các cảm biến như cảm biến nhiệt độ, độ ẩm, áp suất, ánh sáng hoặc giám sát nguồn thường hỗ trợ I2C. Tuy nhiên, I2C chủ yếu phù hợp cho kết nối trong phạm vi ngắn trên cùng bo mạch hoặc giữa các module gần nhau. Khi triển khai ngoài thực tế, cần chú ý địa chỉ thiết bị, điện áp logic, điện trở kéo lên, tốc độ bus và khả năng chống nhiễu của đường truyền.

### 2.5. Chuẩn giao tiếp UART

UART, viết đầy đủ là Universal Asynchronous Receiver-Transmitter, là khối giao tiếp nối tiếp bất đồng bộ được sử dụng rộng rãi trong máy tính, hệ thống nhúng và thiết bị ngoại vi. Khác với I2C hoặc SPI, UART không sử dụng đường clock riêng để đồng bộ giữa bên truyền và bên nhận. Thay vào đó, hai thiết bị phải được cấu hình cùng các tham số truyền thông như baud rate, số bit dữ liệu, parity và số bit stop. Việc đồng bộ từng ký tự được thực hiện thông qua start bit và stop bit.

Một kết nối UART cơ bản thường gồm hai đường tín hiệu là TX và RX. Chân TX của thiết bị này được nối với chân RX của thiết bị kia, và ngược lại. Khi dùng hai đường riêng biệt cho truyền và nhận, UART có thể hỗ trợ truyền song công, tức là hai thiết bị có thể truyền và nhận đồng thời. Trong hệ thống nhúng, UART thường sử dụng mức logic TTL hoặc CMOS, chẳng hạn 3,3 V hoặc 5 V, tùy theo vi điều khiển và module ngoại vi. Vì vậy, khi kết nối UART giữa hai thiết bị, cần đảm bảo mức điện áp logic tương thích.

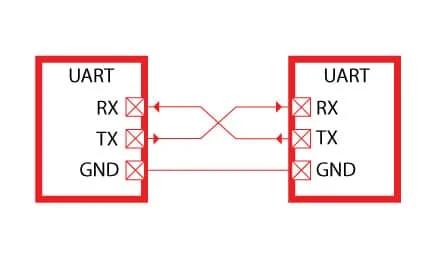
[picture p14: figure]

Hình 2.6. Sơ đồ kết nối giao tiếp UART

Dữ liệu UART được truyền theo từng frame. Khi đường truyền ở trạng thái rỗi, tín hiệu thường ở mức logic cao. Mỗi frame bắt đầu bằng start bit ở mức logic thấp để báo cho bộ nhận biết rằng một ký tự mới sắp được truyền. Sau start bit là các bit dữ liệu, thường là 8 bit. Các bit dữ liệu thường được truyền theo thứ tự từ bit ít quan trọng nhất đến bit quan trọng nhất. Sau phần dữ liệu có thể có parity bit để kiểm tra lỗi đơn giản. Cuối frame là một hoặc nhiều stop bit ở mức logic cao để báo kết thúc ký tự truyền [6].

Cấu hình UART phổ biến trong hệ thống nhúng là 8N1, nghĩa là 8 bit dữ liệu, không parity và 1 stop bit. Với cấu hình này, để truyền một byte dữ liệu 8 bit, đường truyền thực tế cần 10 bit gồm 1 start bit, 8 data bit và 1 stop bit. Do đó, tốc độ dữ liệu hữu ích luôn nhỏ hơn baud rate danh nghĩa. Ví dụ, ở baud rate 9600 bps với cấu hình 8N1, tốc độ truyền dữ liệu hữu ích xấp xỉ 960 byte mỗi giây trong điều kiện lý tưởng.

Do UART là giao tiếp bất đồng bộ, sai lệch baud rate giữa hai thiết bị có thể gây lỗi nhận dữ liệu. Nếu bộ nhận lấy mẫu sai thời điểm, dữ liệu có thể bị sai bit hoặc xuất hiện lỗi framing. Vì vậy, hai thiết bị cần được cấu hình thống nhất về baud rate, số bit dữ liệu, parity và stop bit. Ngoài ra, khi dữ liệu truyền liên tục, firmware cần xử lý bộ đệm nhận kịp thời để tránh tràn buffer.

UART thường được dùng để kết nối vi điều khiển với module truyền thông, module GPS, module Bluetooth, module LoRa, mạch chuyển USB-UART hoặc thiết bị debug. Ưu điểm của UART là đơn giản, dễ triển khai và có sẵn trên hầu hết vi điều khiển. Nhược điểm là mỗi kết nối UART cơ bản chỉ phục vụ giao tiếp điểm-điểm giữa hai thiết bị và không có cơ chế định địa chỉ nhiều thiết bị trên cùng bus như I2C.

### 2.6. Cảm biến nhiệt độ và độ ẩm SHT30

SHT30 là cảm biến nhiệt độ và độ ẩm số thuộc họ SHT3x-DIS của Sensirion. Đây là dòng cảm biến tích hợp phần tử đo độ ẩm, cảm biến nhiệt độ, mạch xử lý tín hiệu và giao tiếp số trong cùng một chip. Theo datasheet của Sensirion, SHT3x-DIS cung cấp đầu ra số đã được hiệu chuẩn, tuyến tính hóa và bù nhiệt độ; cảm biến hỗ trợ giao tiếp I2C với tốc độ lên đến 1 MHz và có hai địa chỉ I2C có thể lựa chọn [7].

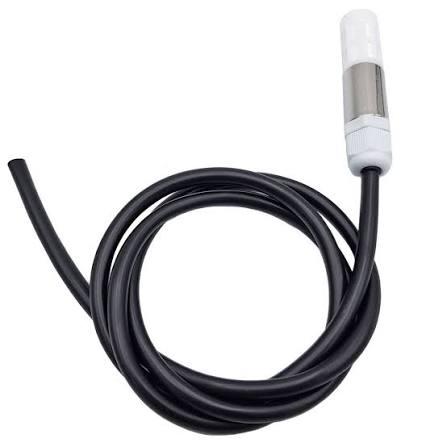
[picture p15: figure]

Hình 2.7. Cảm biến nhiệt độ - độ ẩm SHT30

Cảm biến độ ẩm trong SHT30 hoạt động dựa trên sự thay đổi đặc tính điện của phần tử cảm biến khi độ ẩm môi trường thay đổi. Cảm biến nhiệt độ được tích hợp để đo nhiệt độ môi trường, đồng thời hỗ trợ quá trình bù nhiệt độ cho phép đo độ ẩm. Dữ liệu sau khi được cảm biến xử lý nội bộ sẽ được trả về dưới dạng số, giúp vi điều khiển không cần tự thiết kế mạch đo tương tự phức tạp.

SHT30 giao tiếp với vi điều khiển thông qua I2C. Trong quá trình đo, vi điều khiển gửi lệnh đo đến cảm biến. Sau khi nhận lệnh, cảm biến thực hiện quá trình lấy mẫu và xử lý, sau đó trả về dữ liệu nhiệt độ và độ ẩm. Datasheet cho biết ở chế độ single shot, mỗi lệnh đo tạo ra một cặp dữ liệu gồm một giá trị nhiệt độ 16 bit và một giá trị độ ẩm 16 bit [7]. Mỗi nhóm dữ liệu đo được đi kèm CRC 8 bit, giúp tăng độ tin cậy trong truyền thông I2C [7].

CRC là điểm quan trọng của SHT30 trong các hệ thống cần độ tin cậy dữ liệu. Khi vi điều khiển đọc dữ liệu từ cảm biến, firmware có thể tính lại CRC và so sánh với CRC do cảm biến gửi kèm. Nếu CRC không khớp, dữ liệu có thể bị lỗi trong quá trình truyền hoặc đọc và cần được loại bỏ. Điều này hữu ích trong hệ thống quan trắc môi trường, vì dữ liệu sai có thể làm ảnh hưởng đến quá trình hiển thị, lưu trữ hoặc dự báo.

SHT30 hỗ trợ nhiều chế độ đo với các mức repeatability khác nhau. Repeatability cao thường cho độ nhiễu thấp hơn nhưng thời gian đo và năng lượng tiêu thụ có thể tăng. Repeatability thấp có thể phù hợp với các ứng dụng cần tiết kiệm năng lượng hoặc tốc độ đo cao hơn. Việc lựa chọn chế độ đo phụ thuộc vào yêu cầu của hệ thống, chẳng hạn độ chính xác mong muốn, chu kỳ lấy mẫu và khả năng cấp nguồn.

Trong hệ thống quan trắc thời tiết cục bộ, cảm biến nhiệt độ và độ ẩm là thành phần quan trọng vì hai đại lượng này phản ánh trực tiếp trạng thái môi trường. Dữ liệu nhiệt độ và độ ẩm cũng có thể được sử dụng làm đầu vào cho các mô hình phân tích hoặc dự báo xu hướng. Phần ứng dụng cụ thể của SHT30 trong thiết kế Sensor Node sẽ được trình bày ở Chương 3.

### 2.7. Cảm biến áp suất khí quyển BMP388

BMP388 là cảm biến áp suất khí quyển số của Bosch Sensortec. Cảm biến này có khả năng đo áp suất và nhiệt độ, hỗ trợ giao tiếp I2C hoặc SPI. Theo datasheet của Bosch Sensortec, BMP388 là cảm biến áp suất số dựa trên nguyên lý cảm biến đã được kiểm chứng, có kích thước rất nhỏ, tiêu thụ dòng thấp và phù hợp với các thiết bị dùng pin. Datasheet cũng nêu các ứng dụng điển hình của BMP388 gồm IoT, định vị trong nhà, thiết bị đeo, trạm thời tiết gia đình và dự báo thời tiết [8].

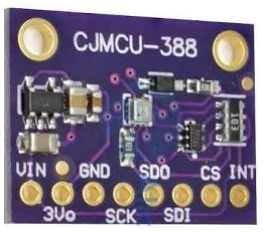
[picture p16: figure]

Hình 2.8. Cảm biến áp suất - nhiệt độ BMP388

Cảm biến áp suất khí quyển dùng để đo áp suất của không khí tại vị trí đặt thiết bị. Áp suất khí quyển thay đổi theo độ cao, điều kiện thời tiết và các biến động khí quyển. Vì vậy, dữ liệu áp suất thường được dùng trong các ứng dụng như đo độ cao, hỗ trợ định vị, theo dõi thời tiết và quan trắc môi trường. Trong một hệ thống thời tiết cục bộ, áp suất là một biến bổ sung quan trọng bên cạnh nhiệt độ và độ ẩm.

BMP388 có dải đo áp suất từ 300 hPa đến 1250 hPa và dải nhiệt độ hoạt động từ -40 °C đến +85 °C theo tài liệu của Bosch Sensortec [8]. Cảm biến hỗ trợ các chế độ nguồn như sleep mode, forced mode và normal mode. Ở forced mode, vi điều khiển có thể kích hoạt từng lần đo khi cần, phù hợp với hệ thống cần kiểm soát chu kỳ lấy mẫu và tiết kiệm năng lượng. Ở normal mode, cảm biến có thể đo liên tục theo cấu hình oversampling và output data rate.

Một điểm quan trọng của BMP388 là quá trình bù dữ liệu đo. Cảm biến áp suất thường không chỉ trả về giá trị áp suất đã sẵn sàng dùng ngay ở dạng vật lý, mà cần sử dụng dữ liệu thô kết hợp với các hệ số hiệu chỉnh nội bộ được lưu trong cảm biến. Các hệ số này được nhà sản xuất xác định trong quá trình hiệu chuẩn. Firmware hoặc thư viện điều khiển cần đọc các hệ số này và áp dụng công thức bù để tính ra áp suất và nhiệt độ có ý nghĩa vật lý.

BMP388 cũng hỗ trợ các chức năng giúp cải thiện chất lượng đo như oversampling, bộ lọc IIR và FIFO. Oversampling giúp giảm nhiễu bằng cách lấy nhiều mẫu và xử lý trung bình. Bộ lọc IIR giúp làm mượt dữ liệu, đặc biệt hữu ích khi áp suất thay đổi chậm nhưng dữ liệu đo có nhiễu. FIFO cho phép lưu tạm dữ liệu trong cảm biến, giảm nguy cơ mất mẫu khi vi điều khiển không đọc kịp trong một số tình huống.

Trong hệ thống quan trắc thời tiết cục bộ, BMP388 phù hợp để bổ sung thông tin áp suất khí quyển. Dữ liệu áp suất không chỉ phục vụ hiển thị mà còn có thể dùng làm biến đầu vào cho mô hình phân tích xu hướng. Phần sử dụng BMP388 cụ thể trong Sensor Node sẽ được trình bày trong chương thiết kế hệ thống.

### 2.8. Cảm biến giám sát nguồn INA219

INA219 là cảm biến giám sát dòng điện, điện áp và công suất của Texas Instruments. Theo datasheet, INA219 là current shunt and power monitor có giao tiếp I2C hoặc SMBus, có khả năng đo điện áp rơi trên điện trở shunt và điện áp bus [9]. Cảm biến này thường được sử dụng trong các hệ thống cần theo dõi dòng tiêu thụ, điện áp nguồn hoặc công suất của tải.

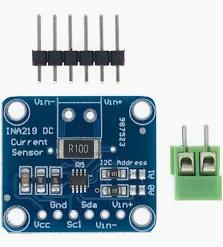
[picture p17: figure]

Hình 2.9. Cảm biến đo dòng - áp INA219

Nguyên lý cơ bản của INA219 dựa trên phép đo điện áp rơi trên điện trở shunt. Khi dòng điện đi qua điện trở shunt, trên điện trở xuất hiện một điện áp nhỏ tỉ lệ với dòng điện theo định luật Ohm. INA219 đo điện áp vi sai giữa hai chân IN+ và IN– để xác định shunt voltage. Đồng thời, cảm biến cũng đo bus voltage, tức là điện áp nguồn hoặc điện áp cấp cho tải so với mass. Từ shunt voltage, bus voltage và giá trị điện trở shunt, hệ thống có thể tính toán dòng điện và công suất tiêu thụ.

INA219 tích hợp ADC để chuyển đổi các tín hiệu đo thành giá trị số. Datasheet cho biết INA219 có độ phân giải ADC 12 bit, shunt voltage LSB 10 µV và bus voltage LSB 4 mV [9]. Thiết bị hỗ trợ các thanh ghi cấu hình, thanh ghi shunt voltage, bus voltage, current và power. Để đọc được trực tiếp dòng điện và công suất, hệ thống cần cấu hình calibration register. Nếu chưa cấu hình calibration register, người dùng vẫn có thể đọc trực tiếp shunt voltage và bus voltage để tự xử lý bên ngoài.

Giao tiếp I2C giúp INA219 dễ tích hợp vào các hệ thống nhúng. Cảm biến có nhiều địa chỉ lập trình được, cho phép đặt nhiều INA219 trên cùng một bus trong các ứng dụng cần giám sát nhiều nhánh nguồn. Thiết bị cũng hỗ trợ các chế độ hoạt động khác nhau như đo liên tục hoặc đo theo yêu cầu. Việc lựa chọn chế độ phụ thuộc vào yêu cầu cập nhật dữ liệu và mức tiêu thụ năng lượng của hệ thống.

Trong hệ thống IoT dùng pin hoặc nguồn cấp ngoài, giám sát nguồn là chức năng quan trọng. Dữ liệu điện áp và dòng điện giúp đánh giá trạng thái pin, phát hiện sụt áp, kiểm tra tải tiêu thụ và hỗ trợ bảo trì thiết bị. Đối với sensor node đặt xa hoặc hoạt động độc lập, việc biết trạng thái nguồn giúp hệ thống đánh giá độ ổn định vận hành và phát hiện sớm các trường hợp nguồn yếu hoặc lỗi cấp nguồn.

### 2.9. Module truyền thông LoRa E32

LoRa là công nghệ truyền thông vô tuyến tầm xa, công suất thấp, phù hợp với các hệ thống IoT cần truyền lượng dữ liệu nhỏ qua khoảng cách xa. LoRa sử dụng kỹ thuật trải phổ dạng chirp, còn gọi là Chirp Spread Spectrum. Trong kỹ thuật này, tín hiệu được biểu diễn bằng các chirp có tần số thay đổi theo thời gian. Cách điều chế này giúp tín hiệu có khả năng chống nhiễu tốt, hỗ trợ truyền xa và phù hợp với các ứng dụng tốc độ dữ liệu thấp.

Cần phân biệt giữa LoRa và LoRaWAN. LoRa là công nghệ ở tầng vật lý, liên quan đến kỹ thuật điều chế tín hiệu vô tuyến. LoRaWAN là giao thức mạng lớp trên, định nghĩa cách các thiết bị đầu cuối, gateway, network server và application server tương tác với nhau. Một hệ thống có thể sử dụng chip hoặc module LoRa để truyền điểm-điểm mà không dùng LoRaWAN. Cách này thường phù hợp với các hệ thống đơn giản, số lượng node ít hoặc phạm vi nghiên cứu hẹp.

E32-433T30D là module truyền thông không dây của EBYTE. Theo user manual của EBYTE, E32-433T30D là module wireless serial port dựa trên chip RF SX1278 của Semtech, hoạt động trong dải 410 MHz đến 441 MHz, mặc định 433 MHz, sử dụng công nghệ LoRa spread spectrum [10]. . Tài liệu cũng nêu module hỗ trợ công suất phát tối đa khoảng 1 W, tốc độ truyền không khí từ 0,3 kbps đến 19,2 kbps, giao tiếp TTL UART 3,3 V và có thể đạt khoảng cách tham khảo 8 km trong điều kiện thử nghiệm thông thoáng

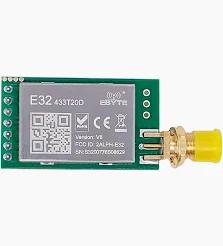
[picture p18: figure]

Hình 2.10. Module Lora E32-433Mhz 1W

Về phần cứng, module E32 có các chân chính gồm VCC, GND, RXD, TXD, M0, M1 và AUX. Chân RXD và TXD dùng để giao tiếp UART với vi điều khiển. Chân M0 và M1 dùng để chọn chế độ hoạt động. Chân AUX dùng để báo trạng thái làm việc của module, ví dụ module đang bận truyền, còn dữ liệu trong buffer hoặc đang tự kiểm tra sau khi khởi động. Do đó, khi thiết kế firmware, vi điều khiển thường cần kiểm tra AUX trước khi gửi dữ liệu để tránh gửi khi module chưa sẵn sàng.

Module E32 hỗ trợ nhiều chế độ hoạt động. Ở chế độ Normal, UART và kênh vô tuyến đều mở, module truyền nhận dữ liệu theo cơ chế transparent transmission. Ở chế độ Wake-up, module thêm mã đánh thức trước dữ liệu để hỗ trợ đánh thức thiết bị đầu xa. Ở chế độ Power-saving, module tiết kiệm năng lượng và lắng nghe theo chu kỳ. Ở chế độ Sleep, module chủ yếu dùng để cấu hình tham số qua UART. Các chế độ này được chọn thông qua tổ hợp chân M0 và M1 [11].

Trong chế độ transparent transmission, vi điều khiển gửi byte dữ liệu đến module E32 qua UART. Module E32 sau đó xử lý việc truyền dữ liệu qua sóng LoRa. Ở phía nhận, module E32 nhận dữ liệu vô tuyến và xuất lại dữ liệu qua UART cho vi điều khiển. Cách tổ chức này giúp việc tích hợp đơn giản hơn so với việc điều khiển trực tiếp chip RF qua SPI, vì firmware chỉ cần xử lý truyền nhận UART ở tầng vi điều khiển.

Trong hệ thống quan trắc, LoRa E32 phù hợp với đường truyền giữa sensor node và gateway khi lượng dữ liệu nhỏ và không yêu cầu băng thông cao. Tuy nhiên, khi dùng LoRa cần chú ý đến tốc độ truyền không khí, công suất phát, antenna, môi trường truyền, khoảng cách, nhiễu và quy định tần số tại khu vực sử dụng. Phần lựa chọn cấu hình truyền thông cụ thể sẽ được trình bày trong chương thiết kế và triển khai.

### 2.10. Công nghệ quản lý nguồn và lưu trữ năng lượng

Trong hệ thống quan trắc thời tiết cục bộ, khối nguồn có vai trò quan trọng vì thiết bị đo ngoài trời được định hướng hoạt động độc lập tại vị trí đo. Thiết bị không chỉ cần nguồn cấp ổn định cho vi điều khiển, cảm biến và module truyền thông LoRa, mà còn cần khả năng duy trì hoạt động trong thời gian dài khi đặt ngoài môi trường. Vì vậy, hệ thống sử dụng giải pháp kết hợp giữa năng lượng mặt trời, pin lưu trữ Lithium, mạch sạc, mạch bảo vệ pin và bộ chuyển đổi nguồn.

Khối quản lý nguồn trong hệ thống gồm tấm pin năng lượng mặt trời, module sạc CN3791, pin Lithium EVE 1S, mạch bảo vệ pin 1S và bộ chuyển đổi nguồn TPS63020. Trong đó, CN3791 đảm nhiệm vai trò sạc pin từ nguồn năng lượng mặt trời, pin Lithium EVE đóng vai trò lưu trữ năng lượng, mạch bảo vệ 1S giúp hạn chế các trạng thái bất lợi trong quá trình sạc và xả, còn TPS63020 tạo ra đường nguồn ổn định cấp cho các khối điện tử của node.

### 2.10.1. Module sạc pin năng lượng mặt trời CN3791

CN3791 là module sạc pin Lithium thường được sử dụng trong các hệ thống dùng nguồn đầu vào từ tấm pin năng lượng mặt trời. Trong hệ thống này, CN3791 có nhiệm vụ nhận năng lượng từ tấm pin mặt trời và điều khiển quá trình sạc cho pin Lithium EVE 1S. Việc sử dụng module sạc riêng giúp quá trình nạp pin được kiểm soát tốt hơn so với việc cấp trực tiếp điện áp từ tấm pin vào pin lưu trữ.

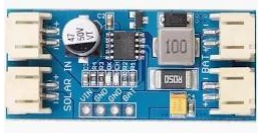
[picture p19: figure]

Hình 2.11. Module CN3791 6V

Về nguyên lý, pin Lithium cần được sạc theo quy trình phù hợp để hạn chế tình trạng sạc quá mức, suy giảm tuổi thọ hoặc mất an toàn trong quá trình sử dụng. Module CN3791 hỗ trợ điều tiết dòng sạc và điện áp sạc, nhờ đó pin có thể được nạp từ nguồn năng lượng mặt trời trong điều kiện điện áp đầu vào thay đổi theo cường độ ánh sáng. Đây là đặc điểm phù hợp với thiết bị quan trắc ngoài môi trường, vì nguồn năng lượng mặt trời không ổn định tuyệt đối trong suốt thời gian vận hành [11]

Trong hệ thống quan trắc thời tiết cục bộ, CN3791 đóng vai trò trung gian giữa tấm pin năng lượng mặt trời và pin lưu trữ. Khi có ánh sáng, tấm pin tạo ra điện năng và đưa đến module sạc. Module sạc sau đó điều khiển quá trình nạp cho pin Lithium. Khi nguồn năng lượng mặt trời không đủ hoặc không có, hệ thống sử dụng năng lượng đã được lưu trữ trong pin để tiếp tục duy trì hoạt động của thiết bị đo ngoài trời.

Việc sử dụng CN3791 trong hệ thống giúp node có khả năng hoạt động độc lập hơn so với thiết kế chỉ dùng nguồn cấp ngoài. Tuy nhiên, hiệu quả của khối sạc phụ thuộc vào công suất tấm pin, điều kiện chiếu sáng, dung lượng pin, dòng tiêu thụ của thiết bị và chu kỳ hoạt động của node. Do đó, trong quá trình thiết kế hệ thống, khối nguồn cần được xem xét cùng với chiến lược tiết kiệm năng lượng của firmware.

### 2.10.2. Pin Lithium EVE và mạch bảo vệ 1S

Pin Lithium EVE được sử dụng làm nguồn lưu trữ năng lượng cho thiết bị đo ngoài trời. Pin có nhiệm vụ cung cấp điện cho hệ thống trong các khoảng thời gian tấm pin năng lượng mặt trời không tạo đủ năng lượng, chẳng hạn khi trời tối, ánh sáng yếu hoặc thiết bị đặt ở vị trí bị che khuất. Nhờ có pin lưu trữ, node có thể duy trì hoạt động theo chu kỳ mà không phụ thuộc hoàn toàn vào nguồn sáng tức thời.

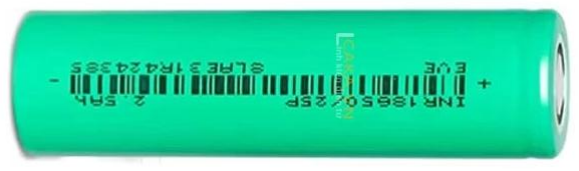
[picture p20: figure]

Hình 2.12. Pin EVE 18650 25P 2500mAh 3.7V 12C Lithium-ion

Trong hệ thống này, pin được sử dụng theo cấu hình một cell Lithium, thường gọi là 1S. Cấu hình 1S có điện áp thay đổi theo trạng thái sạc của pin, vì vậy không thể cấp trực tiếp cho toàn bộ hệ thống nếu các khối điện tử yêu cầu điện áp ổn định. Đối với nhiều cell Lithium-ion thông dụng, điện áp danh định thường nằm quanh mức 3,6 V đến 3,7 V và điện áp sạc đầy thường quanh mức 4,2 V, tùy theo hóa học và datasheet cụ thể của cell. Do đó, điện áp từ pin được đưa qua bộ chuyển đổi nguồn để tạo đường cấp phù hợp cho vi điều khiển, cảm biến và module LoRa.

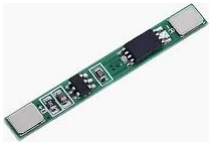
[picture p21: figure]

Hình 2.13. Mạch Sạc Và Bảo Vệ Pin 1S 3.7V 4A

Bên cạnh pin lưu trữ, mạch bảo vệ 1S được sử dụng để tăng độ an toàn trong quá trình vận hành. Mạch bảo vệ có nhiệm vụ hạn chế các trạng thái bất lợi như sạc quá mức, xả quá sâu hoặc dòng bất thường. Các trạng thái này nếu xảy ra trong thời gian dài có thể ảnh hưởng đến tuổi thọ pin, độ ổn định của hệ thống và độ an toàn của thiết bị. Đối với pin Lithium-ion, các điều kiện điện áp vượt ngoài vùng làm việc an toàn hoặc trạng thái quá nhiệt có thể gây suy giảm tuổi thọ và rủi ro an toàn, vì vậy việc sử dụng mạch bảo vệ là cần thiết trong các hệ thống dùng pin độc lập.

Pin Lithium và mạch bảo vệ 1S tạo thành khối lưu trữ năng lượng chính của node. Khối này kết hợp với module sạc CN3791 và bộ chuyển đổi nguồn TPS63020 để hình thành chuỗi cấp nguồn hoàn chỉnh: tấm pin năng lượng mặt trời tạo năng lượng, CN3791 sạc pin, pin lưu trữ năng lượng, mạch bảo vệ giám sát trạng thái pin và TPS63020 ổn định điện áp đầu ra cho hệ thống. Cách tổ chức này phù hợp với thiết bị cảm biến cần hoạt động theo chu kỳ và ưu tiên tiết kiệm năng lượng.

### 2.11. Kết cấu cơ khí và bảo vệ thiết bị ngoài trời

Đối với hệ thống quan trắc thời tiết cục bộ, phần cơ khí bảo vệ có ảnh hưởng trực tiếp đến khả năng vận hành và độ tin cậy của thiết bị. thiết bị đo ngoài trời được đặt tại vị trí quan trắc nên phải chịu tác động của môi trường như ánh nắng, nước mưa, bụi, hơi ẩm và thay đổi nhiệt độ. Nếu chỉ đặt bo mạch và cảm biến trực tiếp ngoài môi trường, thiết bị có thể bị sai lệch dữ liệu đo hoặc hư hỏng phần cứng.

Vì vậy, hệ thống sử dụng kết cấu bảo vệ gồm vỏ hộp chống nước, van thở cân bằng áp suất và lồng Stevenson cho khu vực cảm biến. Vỏ hộp có nhiệm vụ bảo vệ bo mạch điện tử và các khối nguồn. Van thở hỗ trợ giảm hiện tượng tích tụ hơi ẩm và cân bằng áp suất giữa bên trong và bên ngoài hộp. Lồng Stevenson hỗ trợ tạo điều kiện đo phù hợp hơn cho cảm biến nhiệt độ và độ ẩm bằng cách hạn chế tác động trực tiếp của bức xạ mặt trời và nước mưa, đồng thời vẫn cho phép không khí lưu thông quanh cảm biến

### 2.11.1. Vỏ hộp chống nước IP67 và van thở cân bằng áp suất

Vỏ hộp chống nước IP67 được sử dụng để bảo vệ bo mạch và các linh kiện điện tử của thiết bị đo ngoài trời khi thiết bị đặt trong điều kiện môi trường. Theo hệ thống phân cấp bảo vệ IP trong tiêu chuẩn IEC 60529, chữ số đầu tiên thể hiện mức bảo vệ chống bụi và vật rắn, còn chữ số thứ hai thể hiện mức bảo vệ chống nước. Với IP67, thiết bị đạt mức bảo vệ chống bụi ở cấp 6 và bảo vệ chống ngâm nước tạm thời ở cấp 7 trong điều kiện thử nghiệm tiêu chuẩn (International Electrotechnical Commission, 2013).

Trong hệ thống này, vỏ hộp chứa các thành phần như bo mạch xử lý, khối nguồn, pin lưu trữ, mạch sạc, mạch bảo vệ và các đầu nối cần thiết. Việc sử dụng vỏ hộp chống nước giúp tăng khả năng bảo vệ phần cứng, tuy nhiên hộp kín cũng có thể tạo ra một số vấn đề trong quá trình vận hành. Khi nhiệt độ môi trường thay đổi, không khí bên trong hộp có thể giãn nở hoặc co lại, tạo chênh lệch áp suất giữa bên trong và bên ngoài. Ngoài ra, hơi ẩm có thể tích tụ bên trong hộp nếu quá trình thoát ẩm không được hỗ trợ.

Để hạn chế vấn đề trên, van thở cân bằng áp suất được bố trí trên vỏ bảo vệ. Theo thông số của nhà sản xuất, van thở dạng nylon sử dụng màng ePTFE cho phép không khí đi qua nhưng hạn chế hơi ẩm và bụi xâm nhập, giúp cân bằng áp suất trong vỏ thiết bị và giảm hiện tượng ngưng tụ. Một số thông số kỹ thuật của loại van này gồm cấp bảo vệ IP67–IP68 khi sử dụng với vòng đệm O-ring, dải nhiệt độ làm việc khoảng -40°C đến 100°C và lưu lượng khí điển hình được công bố theo điều kiện chênh áp nhất định [12].

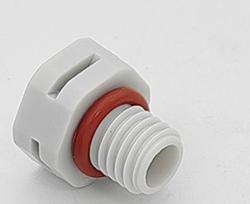
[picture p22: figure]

Hình 2.14. Van thở Nylon M12x1.5, IP68

Trong hệ thống quan trắc thời tiết cục bộ, vỏ hộp chống nước và van thở không trực tiếp tham gia vào quá trình đo dữ liệu, nhưng có vai trò quan trọng đối với độ ổn định của phần cứng. Các thành phần này giúp bảo vệ bo mạch và khối nguồn, đồng thời hỗ trợ thiết bị hoạt động bền hơn trong điều kiện thực nghiệm ngoài môi trường.

### 2.11.2. Lồng Stevenson trong quan trắc khí tượng

Lồng Stevenson là kết cấu được sử dụng trong quan trắc khí tượng nhằm tạo môi trường đo phù hợp hơn cho các cảm biến nhiệt độ và độ ẩm. Mục đích chính của lồng Stevenson là hạn chế ảnh hưởng trực tiếp của bức xạ mặt trời và nước mưa lên cảm biến, đồng thời vẫn cho phép không khí lưu thông qua khu vực đo. Nhờ đó, cảm biến có thể phản ánh trạng thái không khí xung quanh tốt hơn so với trường hợp đặt trực tiếp dưới ánh nắng hoặc trong hộp kín.

Trong hệ thống này, lồng Stevenson được sử dụng cho khu vực cảm biến của thiết bị đo ngoài trời. Cảm biến SHT30 đo nhiệt độ và độ ẩm tương đối, nên vị trí lắp đặt có ảnh hưởng lớn đến kết quả đo. Nếu cảm biến bị chiếu nắng trực tiếp, nhiệt độ đo được có thể cao hơn nhiệt độ không khí thực tế. Nếu cảm biến bị đặt trong không gian quá kín, độ ẩm và nhiệt độ bên trong có thể thay đổi chậm hơn so với môi trường bên ngoài. Vì vậy, lồng Stevenson được dùng để vừa che chắn cảm biến, vừa duy trì khả năng trao đổi không khí.

Lồng Stevenson thường có cấu trúc gồm nhiều lớp che hoặc khe thông gió, giúp giảm tác động trực tiếp của nắng và mưa nhưng không ngăn hoàn toàn sự lưu thông không khí. Trong quan trắc khí tượng, cảm biến nhiệt độ không khí thường cần được đặt trong môi trường thông gió và được che chắn khỏi bức xạ trực tiếp để giảm sai lệch đo [13]. Đối với hệ thống quan trắc cục bộ, việc sử dụng lồng Stevenson giúp tăng tính hợp lý của dữ liệu đo trong điều kiện ngoài trời.

Tuy nhiên, kết quả đo vẫn có thể chịu ảnh hưởng bởi vị trí lắp đặt, độ cao đặt cảm biến, hướng nắng, bề mặt xung quanh và mức độ thông gió thực tế. Vì vậy, lồng Stevenson không làm thay đổi nguyên lý đo của cảm biến, mà đóng vai trò cải thiện điều kiện lắp đặt để dữ liệu đo ít bị ảnh hưởng bởi các yếu tố môi trường trực tiếp.

Trong phạm vi đề tài, lồng Stevenson được xem là một thành phần hỗ trợ quan trọng cho khối cảm biến môi trường. Khi kết hợp với vỏ hộp chống nước và van thở, lồng Stevenson góp phần hoàn thiện kết cấu bảo vệ ngoài trời cho thiết bị đo ngoài trời, giúp thiết bị phù hợp hơn với mục tiêu quan trắc thời tiết cục bộ.

### 2.12. Thuật toán ASCON-128a AEAD

Trong các hệ thống IoT, dữ liệu thường được truyền qua các môi trường không dây hoặc mạng Internet. Các môi trường truyền này có thể bị nghe lén, sửa đổi hoặc giả mạo dữ liệu. Vì vậy, bảo mật dữ liệu không chỉ là việc che giấu nội dung bản tin mà còn phải đảm bảo rằng bản tin không bị thay đổi và thật sự được tạo bởi bên có khóa hợp lệ. Đây là lý do các cơ chế mã hóa xác thực ngày càng được dùng trong hệ thống nhúng và IoT.

ASCON là họ thuật toán mật mã hạng nhẹ được thiết kế cho các thiết bị giới hạn tài nguyên. Theo NIST, chuẩn Ascon-based Lightweight Cryptography được xây dựng cho các thiết bị constrained devices và bao gồm các chức năng mã hóa xác thực, hàm băm và hàm mở rộng đầu ra [14]. Ascon ban đầu được đề xuất trong các cuộc thi và chương trình chuẩn hóa mật mã hạng nhẹ, sau đó được NIST lựa chọn làm nền tảng cho chuẩn mật mã hạng nhẹ. Mục tiêu của Ascon là cung cấp mức an toàn phù hợp trong khi vẫn triển khai hiệu quả trên phần cứng và phần mềm nhúng.

ASCON-128a thuộc nhóm thuật toán AEAD. AEAD là viết tắt của Authenticated Encryption with Associated Data, nghĩa là mã hóa xác thực có dữ liệu liên kết. Cơ chế

AEAD kết hợp hai mục tiêu: bảo mật nội dung bản tin và xác thực tính toàn vẹn của bản tin. Kết quả của quá trình mã hóa không chỉ có ciphertext mà còn có authentication tag. Nếu dữ liệu bị sửa đổi, tag sẽ không hợp lệ và quá trình giải mã bị từ chối.

Một phép mã hóa AEAD thường có bốn đầu vào: khóa bí mật, nonce, plaintext và associated data. Khóa bí mật được chia sẻ giữa bên gửi và bên nhận. Nonce là giá trị dùng một lần cho mỗi phép mã hóa với cùng một khóa. Plaintext là dữ liệu cần được bảo vệ. Associated data là dữ liệu không bị mã hóa nhưng vẫn được đưa vào quá trình xác thực, chẳng hạn header, định danh thiết bị hoặc loại gói tin. Kết quả đầu ra gồm ciphertext và authentication tag.

Ascon sử dụng trạng thái nội bộ 320 bit, được chia thành 5 word 64 bit. Theo tài liệu đặc tả Ascon, tất cả thành viên trong họ Ascon dùng cùng một phép hoán vị nhẹ; mỗi vòng biến đổi gồm ba bước chính: cộng hằng số vòng, lớp thay thế phi tuyến dùng S-box 5 bit và lớp khuếch tán tuyến tính sử dụng các phép xoay bit và XOR [14]. Cấu trúc này giúp Ascon đạt được sự khuếch tán dữ liệu trong trạng thái nội bộ, đồng thời giữ chi phí triển khai tương đối thấp.

Quá trình mã hóa xác thực của Ascon có thể mô tả theo bốn pha. Pha thứ nhất là initialization, trong đó trạng thái được khởi tạo từ khóa và nonce. Pha thứ hai là associated data processing, trong đó associated data được đưa vào trạng thái nếu có sử dụng. Pha thứ ba là plaintext processing, trong đó plaintext được hấp thụ vào trạng thái và ciphertext được sinh ra. Pha cuối cùng là finalization, trong đó khóa được đưa vào trạng thái một lần nữa và authentication tag được sinh ra [14].

Trong quá trình giải mã, bên nhận sử dụng cùng khóa, nonce và associated data để xử lý ciphertext. Nếu tag tính lại khớp với tag nhận được, bản tin được xem là hợp lệ và plaintext được sử dụng. Nếu tag sai, bản tin phải bị loại bỏ. Đây là điểm quan trọng trong truyền thông cảm biến, vì hệ thống có thể phát hiện frame sai hoặc bị sửa đổi trước khi dùng dữ liệu cho lưu trữ, hiển thị hoặc điều khiển.

Trong phạm vi cơ sở lý thuyết, ASCON-128a được xem như một thuật toán phù hợp cho IoT nhờ định hướng lightweight cryptography. Phần thiết kế cụ thể như chọn khóa, cách tạo nonce, kích thước tag và cách đưa ASCON vào frame dữ liệu sẽ được trình bày ở Chương 3.

### 2.13. Giao thức HTTPS trong truyền dữ liệu IoT

HTTP là giao thức tầng ứng dụng được dùng phổ biến để truyền dữ liệu giữa client và server. Tuy nhiên, HTTP thông thường truyền dữ liệu ở dạng không được bảo vệ, nên không phù hợp khi dữ liệu đi qua Internet và cần bảo mật. HTTPS giải quyết vấn đề này bằng cách đặt HTTP bên trong kênh TLS. Nói cách khác, HTTPS là HTTP chạy trên TLS, trong đó TLS cung cấp mã hóa, xác thực và kiểm tra toàn vẹn dữ liệu.

TLS, viết đầy đủ là Transport Layer Security, là giao thức bảo mật dùng để bảo vệ truyền thông client/server. RFC 8446 mô tả TLS 1.3 là giao thức được thiết kế để ngăn nghe lén, sửa đổi và giả mạo thông điệp trong quá trình truyền thông [15]. Khi thiết lập kết nối HTTPS, client và server thực hiện TLS handshake. Trong quá trình này, hai bên thống nhất phiên bản giao thức, bộ thuật toán mật mã, trao đổi khóa và xác thực server thông qua chứng chỉ số. Sau khi handshake hoàn tất, dữ liệu HTTP được truyền bên trong kênh đã mã hóa.

TLS cung cấp ba nhóm chức năng chính. Thứ nhất là tính bí mật, vì dữ liệu được mã hóa trong quá trình truyền. Thứ hai là tính toàn vẹn, vì dữ liệu bị sửa đổi trên đường truyền có thể bị phát hiện. Thứ ba là xác thực server, vì client có thể kiểm tra chứng chỉ số để xác định đang kết nối đến đúng server. Trong một số hệ thống, TLS cũng có thể hỗ trợ xác thực client, nhưng trong nhiều ứng dụng IoT, xác thực thiết bị thường được thực hiện thêm ở tầng ứng dụng bằng token, khóa API hoặc cơ chế chữ ký.

Đối với thiết bị IoT, HTTPS có ưu điểm là tương thích với hầu hết nền tảng cloud, REST API và serverless function. Thiết bị có thể gửi dữ liệu bằng phương thức POST, nhận cấu hình bằng GET hoặc tương tác với API theo các chuẩn web phổ biến. Tuy nhiên, HTTPS cũng yêu cầu tài nguyên phần cứng và phần mềm lớn hơn so với các giao thức nhẹ hơn. Thiết bị cần đủ RAM cho TLS handshake, chứng chỉ, bộ đệm truyền nhận và các phép toán mật mã.

Trong kiến trúc IoT, HTTPS thường phù hợp hơn với gateway hoặc thiết bị có kết nối WiFi/Ethernet, trong khi các sensor node nhỏ có thể dùng giao thức cục bộ nhẹ hơn để gửi dữ liệu về gateway. Gateway sau đó chuyển dữ liệu lên cloud qua HTTPS. Cách tổ chức này giúp sensor node giảm tải xử lý mạng, trong khi gateway đảm nhiệm phần truyền thông Internet và bảo mật kênh truyền.

Trong đề tài, HTTPS được dùng làm nền tảng truyền dữ liệu từ gateway lên cloud. Phần cấu trúc request, dữ liệu gửi kèm, token xác thực và cách xử lý phía cloud sẽ được trình bày trong chương thiết kế hệ thống.

### 2.14. Supabase trong lưu trữ và xử lý dữ liệu IoT

Sau khi dữ liệu IoT được gửi lên Internet, hệ thống cần một tầng backend để tiếp nhận, xử lý, lưu trữ và cung cấp dữ liệu cho giao diện người dùng. Nếu tự xây dựng backend hoàn toàn, nhóm phát triển phải quản lý server, cơ sở dữ liệu, API, xác thực, phân quyền, lưu file và triển khai hạ tầng. Với các hệ thống thử nghiệm, đồ án hoặc prototype, mô hình Backend-as-a-Service giúp giảm đáng kể khối lượng triển khai backend.

Supabase là một nền tảng Backend-as-a-Service mã nguồn mở, cung cấp nhiều thành phần backend như PostgreSQL Database, Edge Functions, Realtime, Authentication và Storage. Theo tài liệu Supabase, mỗi project Supabase có một cơ sở dữ liệu Postgres đầy đủ; database là nền tảng cho Auth, Storage, Realtime và Edge Functions [16]. Điều này giúp Supabase phù hợp với các ứng dụng cần lưu dữ liệu có cấu trúc và phát triển nhanh tầng backend.

PostgreSQL là hệ quản trị cơ sở dữ liệu quan hệ mạnh, hỗ trợ SQL, bảng, ràng buộc, chỉ mục, view, function và nhiều kiểu dữ liệu mở rộng. Trong hệ thống IoT, dữ liệu cảm biến thường là dữ liệu chuỗi thời gian, mỗi bản ghi gắn với thời điểm đo và định danh thiết bị. Lưu dữ liệu trong PostgreSQL giúp hệ thống dễ truy vấn lịch sử, lọc theo thời gian, tính thống kê, tạo dashboard và xuất dữ liệu phục vụ phân tích.

Supabase Edge Functions là các hàm TypeScript phía server, chạy tại edge và có thể được dùng làm HTTP endpoint [16]. Edge Function phù hợp cho các tác vụ như kiểm tra request, xác thực token, xử lý dữ liệu đầu vào, gọi API ngoài hoặc ghi dữ liệu vào database. Trong hệ thống IoT, Edge Function có thể đóng vai trò lớp trung gian giữa thiết bị và database, giúp tránh cho thiết bị ghi trực tiếp vào cơ sở dữ liệu mà không qua kiểm tra.

Supabase Realtime cung cấp khả năng nhận cập nhật khi dữ liệu trong database thay đổi. Chức năng này hữu ích cho dashboard giám sát, vì giao diện người dùng có thể nhận dữ liệu mới mà không cần liên tục truy vấn lại toàn bộ bảng. Với hệ thống quan trắc môi trường, realtime giúp hiển thị dữ liệu gần thời gian thực và cập nhật trạng thái thiết bị khi có bản ghi mới.

Supabase Storage là thành phần dùng để lưu trữ file. Trong các ứng dụng web, Storage thường dùng cho hình ảnh, tài liệu hoặc file nhị phân. Trong các hệ thống IoT, Storage có thể được dùng để lưu firmware, file cấu hình hoặc tài nguyên phục vụ cập nhật thiết bị. Khi kết hợp với database và Edge Function, Storage có thể trở thành một phần của cơ chế quản lý firmware từ xa.

Một khía cạnh quan trọng của Supabase là phân quyền dữ liệu. Row Level Security cho phép kiểm soát quyền truy cập ở mức từng dòng trong bảng. Trong hệ thống IoT, không phải client nào cũng nên có quyền ghi trực tiếp vào bảng dữ liệu cảm biến. Việc kết hợp RLS, token, Edge Function và policy giúp hệ thống kiểm soát tốt hơn dữ liệu đầu vào, quyền đọc của dashboard và quyền ghi của thiết bị.

### 2.15. BLE provisioning và OTA firmware update

Trong các thiết bị IoT dùng WiFi, việc cấu hình SSID và mật khẩu là bước quan trọng trước khi thiết bị có thể kết nối Internet. Nếu thông tin WiFi được nạp cứng trong firmware, thiết bị sẽ khó triển khai trong môi trường thực tế vì mỗi địa điểm có thể dùng mạng khác nhau. Khi đổi router hoặc đổi mật khẩu, người dùng phải nạp lại firmware. Vì vậy, nhiều thiết bị IoT sử dụng cơ chế provisioning để cấu hình WiFi sau khi thiết bị đã được sản xuất hoặc lắp đặt.

WiFi provisioning là quá trình đưa thông tin mạng WiFi vào thiết bị. ESP-IDF hỗ trợ WiFi provisioning thông qua nhiều phương thức, trong đó có Bluetooth Low Energy. Theo tài liệu Espressif, WiFi provisioning cho phép thiết bị nhận WiFi credentials thông qua SoftAP hoặc BLE, sau đó lưu lại để sử dụng cho các lần khởi động sau [17]. BLE provisioning phù hợp với thiết bị không có màn hình hoặc bàn phím, vì người dùng có thể cấu hình thông qua điện thoại.

Bluetooth Low Energy là công nghệ truyền thông không dây tầm ngắn, tiêu thụ năng lượng thấp. Trong provisioning, thiết bị ESP32 có thể phát dịch vụ BLE. Ứng dụng trên điện thoại kết nối đến thiết bị, gửi SSID và mật khẩu WiFi qua kênh provisioning. Sau khi nhận credential, thiết bị thử kết nối đến mạng WiFi. Nếu kết nối thành công, thông tin này được lưu vào vùng nhớ không mất dữ liệu, thường là NVS.

Trong các thiết bị IoT, ngoài chương trình firmware chính, thiết bị còn cần lưu trữ một số thông tin cấu hình nhỏ để phục vụ quá trình vận hành. Các thông tin này thường không nên mất đi khi thiết bị reset hoặc mất nguồn. Trên nền tảng ESP32-S3, một cơ chế thường được sử dụng cho mục đích này là NVS.

NVS, viết tắt của Non-Volatile Storage, là cơ chế lưu trữ dữ liệu không mất khi mất nguồn. NVS thường được dùng để lưu các cặp khóa – giá trị có kích thước nhỏ, chẳng hạn như tên mạng WiFi, mật khẩu WiFi, trạng thái cấu hình thiết bị, phiên bản firmware, trạng thái OTA đã áp dụng hoặc một số tham số vận hành. Khi thiết bị khởi động lại, firmware có thể đọc dữ liệu từ NVS để quyết định bước xử lý tiếp theo. Ví dụ, nếu trong NVS đã có WiFi credential hợp lệ, thiết bị có thể tự kết nối WiFi mà không cần người dùng cấu hình lại.

Ngược lại, nếu chưa có thông tin WiFi hoặc thông tin cũ không còn hợp lệ, thiết bị có thể chuyển sang chế độ cấu hình lại mạng.

BLE provisioning là cơ chế cấu hình WiFi cho thiết bị thông qua Bluetooth Low Energy. Thay vì nạp cứng SSID và mật khẩu WiFi vào firmware, thiết bị có thể mở một dịch vụ provisioning để người dùng nhập thông tin mạng trong quá trình triển khai thực tế. Cách làm này phù hợp với thiết bị IoT vì môi trường lắp đặt có thể thay đổi, tên mạng WiFi hoặc mật khẩu WiFi có thể khác nhau giữa các vị trí. Khi quá trình provisioning thành công, thông tin WiFi được lưu vào NVS để thiết bị sử dụng lại ở các lần khởi động sau.

Nhờ có BLE provisioning, thiết bị gateway có thể được triển khai linh hoạt hơn. Người dùng không cần nạp lại firmware chỉ để thay đổi WiFi. Thiết bị có thể tự kiểm tra trạng thái cấu hình khi khởi động: nếu đã có thông tin WiFi trong NVS thì tiến hành kết nối; nếu chưa có hoặc kết nối thất bại nhiều lần thì mở lại provisioning để người dùng nhập thông tin mới. Cơ chế này giúp hệ thống phù hợp hơn với điều kiện vận hành thực tế so với cách cấu hình WiFi cố định trong mã nguồn.

Bên cạnh cấu hình WiFi, thiết bị IoT cũng cần có khả năng cập nhật firmware sau khi đã triển khai. OTA firmware update, viết tắt của Over-The-Air firmware update, là cơ chế cho phép thiết bị tải và cài đặt firmware mới thông qua mạng mà không cần kết nối cáp nạp trực tiếp. Đây là chức năng quan trọng đối với các thiết bị IoT vì sau khi lắp đặt, thiết bị có thể cần sửa lỗi, bổ sung chức năng, thay đổi cấu hình bảo mật hoặc cải thiện độ ổn định của hệ thống.

Trên ESP32-S3, cơ chế OTA thường được xây dựng dựa trên bảng phân vùng flash có nhiều phân vùng ứng dụng. Theo tài liệu ESP-IDF, firmware mới không được ghi đè trực tiếp lên phân vùng ứng dụng đang chạy. Thay vào đó, firmware mới được tải xuống và ghi vào một phân vùng OTA khác. Sau khi quá trình ghi hoàn tất và image được kiểm tra hợp lệ, thông tin boot được cập nhật để thiết bị khởi động vào firmware mới ở lần reset tiếp theo [18]. Cách tổ chức này giúp giảm rủi ro trong quá trình cập nhật, vì firmware đang chạy không bị ghi đè trực tiếp trong lúc tải bản mới.

Một quy trình OTA cơ bản thường gồm ba giai đoạn. Giai đoạn thứ nhất là kiểm tra phiên bản hoặc cấu hình cập nhật để xác định có firmware mới hay không. Giai đoạn thứ hai là tải firmware mới qua mạng và ghi vào phân vùng OTA phù hợp. Giai đoạn thứ ba là xác minh firmware, cập nhật trạng thái boot và khởi động lại thiết bị để chạy firmware mới. Trong các hệ thống yêu cầu độ tin cậy cao, OTA thường kết hợp thêm version number, sequence number, checksum hoặc hash như SHA-256 để kiểm tra tính toàn vẹn của file và tránh cập nhật nhầm hoặc cập nhật lặp lại cùng một firmware.

NVS có vai trò quan trọng trong cả BLE provisioning và OTA. Đối với BLE provisioning, NVS lưu thông tin WiFi để thiết bị có thể tự kết nối lại sau khi reset. Đối với OTA, NVS có thể lưu trạng thái firmware đã áp dụng, mã định danh phiên bản, sequence number hoặc giá trị hash của firmware gần nhất. Nhờ đó, thiết bị có thể biết bản cập nhật nào đã được cài đặt và tránh tải lại cùng một firmware nhiều lần.

Trong phạm vi đề tài, BLE provisioning và OTA firmware update được xem là các cơ chế hỗ trợ vận hành cho ESP32-S3 Gateway. BLE provisioning giúp gateway cấu hình WiFi linh hoạt trong thực tế mà không cần nạp lại firmware. OTA giúp gateway có khả năng cập nhật phần mềm từ xa khi cần sửa lỗi hoặc bổ sung chức năng. Phần thiết kế chi tiết về điều kiện kích hoạt provisioning, cách lưu thông tin trong NVS, quy trình kiểm tra bản OTA mới và cách tránh cập nhật lặp sẽ được trình bày ở chương thiết kế hệ thống và chương triển khai firmware.

Trên ESP32-S3, OTA thường dựa trên bảng phân vùng có nhiều phân vùng ứng dụng. Theo tài liệu ESP-IDF, cơ chế OTA cho phép ghi firmware mới vào phân vùng không phải phân vùng đang chạy, sau đó cập nhật thông tin boot để thiết bị khởi động vào image mới [18]. Cách tổ chức này giúp giảm rủi ro so với việc ghi đè trực tiếp lên firmware đang chạy.

### 2.16. Multiple Linear Regression trong dự báo nhiệt độ cục bộ ngắn hạn

Trong hệ thống quan trắc thời tiết cục bộ, dữ liệu cảm biến không chỉ có ý nghĩa tại thời điểm đo hiện tại mà còn có thể được sử dụng để khảo sát xu hướng biến đổi trong tương lai gần. Các đại lượng như nhiệt độ, độ ẩm và áp suất khí quyển thay đổi theo thời gian và chịu ảnh hưởng bởi nhiều yếu tố như chu kỳ ngày đêm, điều kiện che chắn, thông gió, vị trí đặt cảm biến và trạng thái môi trường xung quanh. Khi các dữ liệu này được thu thập liên tục, chúng tạo thành một chuỗi quan sát theo thời gian và có thể được khai thác để xây dựng mô hình dự báo.

Trong phạm vi đề tài, bài toán dự báo được giới hạn ở nhiệt độ cục bộ sau 2 giờ tại vị trí đặt trạm đo. Hệ thống không hướng đến dự báo toàn bộ trạng thái thời tiết cho một khu vực rộng và cũng không thay thế các mô hình khí tượng chuyên nghiệp. Các hệ thống dự báo thời tiết chuyên nghiệp thường cần nhiều nguồn dữ liệu như radar, vệ tinh, trạm khí tượng diện rộng và mô hình khí tượng số. Ngược lại, hệ thống trong đề tài chỉ sử dụng dữ liệu đo tại một điểm cục bộ để tạo ra giá trị dự báo tham khảo trong ngắn hạn. Vì vậy, mô hình được lựa chọn cần có cấu trúc đơn giản, dễ giải thích và phù hợp với khả năng tính toán của gateway nhúng.

Multiple Linear Regression, hay hồi quy tuyến tính đa biến, được sử dụng trong đề tài như một mô hình học máy cơ bản để khai thác mối quan hệ giữa các thông số môi trường và nhiệt độ cần dự báo. Mô hình này phù hợp với giai đoạn khảo sát ban đầu vì công thức rõ ràng, quá trình suy luận nhẹ và có thể triển khai trực tiếp trên ESP32-S3 Gateway sau khi các hệ số đã được huấn luyện trước.

### 2.16.1. Cơ sở của mô hình Multiple Linear Regression trong dự báo nhiệt độ

Multiple Linear Regression là mô hình hồi quy dùng để biểu diễn mối quan hệ tuyến tính giữa nhiều biến đầu vào và một biến đầu ra liên tục. Trong bài toán dự báo nhiệt độ, biến đầu ra là nhiệt độ cần dự báo tại một thời điểm trong tương lai, còn các biến đầu vào là những thông số có liên quan đến trạng thái môi trường. Nếu hồi quy tuyến tính đơn chỉ xét một biến đầu vào, hồi quy tuyến tính đa biến cho phép mô hình kết hợp nhiều thông tin môi trường trong cùng một công thức.

Dạng tổng quát của mô hình Multiple Linear Regression được viết như sau:

ŷ = b₀ + b₁x₁ + b₂x₂ + ... + bₙxₙ | (1)

Trong đó, ŷ là giá trị dự báo của mô hình; x1, x2, ..., xn là các biến đầu vào; b0 là hệ số chặn và b1, b2, ..., bn là các hệ số hồi quy. Các hệ số này được xác định trong quá trình huấn luyện dựa trên dữ liệu lịch sử. Sau khi quá trình huấn luyện hoàn tất, mô hình có thể tạo ra giá trị dự báo mới bằng cách thay các giá trị đầu vào vào công thức đã có hệ số. Trong nghiên cứu này, các tác giả sử dụng dữ liệu khí tượng trong quá khứ và mô hình Multiple Linear Regression để dự báo nhiệt độ trung bình của một ngày. Quy trình của bài báo gồm dữ liệu khí tượng ban đầu, bước lựa chọn đặc trưng, tạo tập dữ liệu tinh lọc, huấn luyện mô hình hồi quy tuyến tính đa biến và đánh giá kết quả dự báo. Bài báo cho thấy mô hình Multiple Linear Regression có thể dự báo nhiệt độ trung bình ngày với sai số trung bình khoảng 2,8 °C [19]. Kết quả của nghiên cứu trên có ý nghĩa đối với đề tài vì nó chứng minh rằng Multiple Linear Regression có thể được dùng như một mô hình cơ bản trong bài toán dự báo nhiệt độ.

2.16.2. Mô hình MLR cơ bản với các biến môi trường.

Khi áp dụng Multiple Linear Regression cho hệ thống quan trắc thời tiết cục bộ, dạng đơn giản nhất của mô hình có thể bắt đầu từ các biến môi trường hiện tại. Các biến này là những thông số được trạm đo đạc đo trực tiếp tại thời điểm lấy mẫu, chẳng hạn như nhiệt độ, độ ẩm và áp suất khí quyển. Nếu chỉ xét mô hình môi trường cơ bản, nhiệt độ sau 2 giờ có thể được biểu diễn theo dạng:

T̂(t+2h) = b₀ + b₁Tₜ + b₂Hₜ + b₃Pₜ | (2)

Trong đó, T̂(t+2h) là nhiệt độ dự báo sau 2 giờ, Tt là nhiệt độ hiện tại, Ht là độ ẩm hiện tại và Pt là áp suất khí quyển hiện tại.

Dạng mô hình này có ý nghĩa vì nhiệt độ hiện tại thường có quan hệ trực tiếp với nhiệt độ trong tương lai gần. Nếu môi trường đang ở mức nhiệt cao, nhiệt độ sau 2 giờ có thể vẫn chịu ảnh hưởng bởi mức nền đó. Độ ẩm cung cấp thêm thông tin về trạng thái không khí, trong khi áp suất khí quyển phản ánh một phần điều kiện khí quyển tại thời điểm đo. Vì vậy, các biến môi trường hiện tại có thể tạo thành nền tảng ban đầu cho mô hình dự báo.

Tuy nhiên, mô hình chỉ dùng nhiệt độ, độ ẩm và áp suất vẫn có một giới hạn về mặt biểu diễn dữ liệu. Các biến này mô tả trạng thái môi trường tại thời điểm đo, nhưng chưa cho mô hình biết mẫu đo đó xảy ra vào thời điểm nào trong ngày. Trong bài toán dự báo nhiệt độ cục bộ sau 2 giờ, thông tin thời điểm đo có thể ảnh hưởng đến xu hướng nhiệt độ tiếp theo. Vì vậy, mô hình MLR cơ bản với các biến môi trường hiện tại là điểm xuất phát, nhưng chưa phải dạng biểu diễn đầy đủ cho bài toán của đề tài.

### 2.16.3. Vai trò của yếu tố thời gian trong dự báo nhiệt độ cục bộ

Nhiệt độ tại một vị trí cục bộ thường có chu kỳ ngày đêm rõ rệt. Trong ngày, nhiệt độ có xu hướng tăng khi bức xạ mặt trời tác động mạnh hơn và có xu hướng giảm vào buổi tối hoặc ban đêm khi môi trường mất nhiệt. Vì vậy, cùng một giá trị nhiệt độ hiện tại nhưng xuất hiện ở hai thời điểm khác nhau trong ngày có thể dẫn đến xu hướng nhiệt độ sau 2 giờ khác nhau.

Ví dụ, nếu hệ thống đo được một trạng thái môi trường có nhiệt độ, độ ẩm và áp suất gần giống nhau ở hai thời điểm khác nhau, mô hình chỉ dùng các biến môi trường có thể tạo ra cùng một giá trị dự báo. Tuy nhiên, nếu một mẫu xuất hiện vào buổi sáng, nhiệt độ sau 2 giờ có thể đang trong xu hướng tăng. Nếu mẫu tương tự xuất hiện vào buổi tối, nhiệt độ sau 2 giờ có thể đang trong xu hướng giảm. Điểm khác biệt nằm ở bối cảnh thời gian của mẫu đo.

Do đó, việc bổ sung yếu tố thời gian vào mô hình không phải vì MLR bắt buộc phải có biến giờ, mà vì bài toán dự báo nhiệt độ cục bộ sau 2 giờ cần biết mẫu đo đang nằm ở giai đoạn nào trong chu kỳ ngày. Nếu mô hình chỉ được thiết kế để khai thác nhiệt độ, độ ẩm và áp suất, nó vẫn có thể hoạt động như một mô hình cơ bản. Tuy nhiên, khi muốn mô hình phản ánh tốt hơn xu hướng ngày đêm của nhiệt độ, thông tin thời gian cần được đưa vào như một đặc trưng bổ sung.

Khoảng thời gian dự báo sau 2 giờ cũng có liên hệ với nhóm dự báo rất ngắn hạn trong khí tượng học. Một số tài liệu về nowcasting mô tả nowcasting là dạng dự báo thời tiết trong thời gian rất ngắn, thường dưới khoảng 2 giờ [20]. Tuy nhiên, đề tài này không triển khai nowcasting theo nghĩa đầy đủ của khí tượng học vì không sử dụng radar, vệ tinh hoặc mô hình dự báo thời tiết diện rộng. Vì vậy, trong báo cáo, cách gọi phù hợp hơn là dự báo nhiệt độ cục bộ ngắn hạn.

### 2.16.4. Mã hóa đặc trưng thời gian chu kỳ

Sau khi xác định yếu tố thời gian có ý nghĩa đối với dự báo nhiệt độ cục bộ, vấn đề tiếp theo là cách biểu diễn thời gian trong mô hình. Cách đơn giản nhất là đưa giờ trong ngày vào mô hình dưới dạng số nguyên từ 0 đến 23. Tuy nhiên, cách biểu diễn này không phù hợp với bản chất chu kỳ của thời gian khi sử dụng trong mô hình tuyến tính.

Về mặt thời gian thực, 23 giờ và 0 giờ là hai thời điểm liền kề nhau vì chúng chỉ cách nhau một giờ tại ranh giới giữa hai ngày. Tuy nhiên, nếu biểu diễn giờ bằng số nguyên, hai giá trị 23 và 0 lại cách nhau 23 đơn vị. Đối với mô hình tuyến tính, khoảng cách số học này có thể tạo ra một bước nhảy nhân tạo tại thời điểm chuyển ngày. Khi đó, mô hình có thể hiểu sai rằng cuối ngày và đầu ngày là hai vùng thời gian rất xa nhau, trong khi thực tế chúng nằm cạnh nhau trong chu kỳ 24 giờ.

Tài liệu scikit-learn về time-related feature engineering cũng chỉ ra vấn đề tương tự đối với đặc trưng thời gian dạng số thứ tự. Khi dùng trực tiếp các đặc trưng thời gian nguyên thủy cho mô hình tuyến tính, mô hình có thể không nắm bắt được tính tuần hoàn tự nhiên của thời gian. Tài liệu này nêu rằng đặc trưng thời gian dạng ordinal có thể gây ra bước nhảy trong dự báo khi giờ chuyển từ 23 về 0, đồng thời đề xuất mã hóa các đặc trưng tuần hoàn bằng biến đổi sine và cosine với chu kỳ tương ứng [21].

Vì vậy, thay vì đưa trực tiếp giờ (h) vào mô hình, giờ trong ngày được mã hóa thành hai đặc trưng:

hour_sin = sin((2πh) / 24) | (3)
hour_cos = cos((2πh) / 24) | (4)

Cách biểu diễn này có thể được hiểu như việc đặt thời điểm trong ngày lên một vòng tròn có chu kỳ 24 giờ. Mỗi giờ trong ngày tương ứng với một vị trí trên vòng tròn. Khi thời gian đi từ 23 giờ sang 0 giờ, vị trí trên vòng tròn thay đổi liên tục, không còn bước nhảy lớn như khi biểu diễn bằng số nguyên. Nhờ đó, mô hình có thể biểu diễn tính liên tục giữa cuối ngày và đầu ngày.

Với chu kỳ dài hơn, chẳng hạn ngày trong năm, cách mã hóa tương tự cũng có thể được sử dụng. Nếu (d) là ngày trong năm, đặc trưng thời gian theo năm có thể được biểu diễn như sau:

day_sin = sin((2πd) / 366) | (5)
day_cos = cos((2πd) / 366) | (6)

Việc dùng chu kỳ 366 ngày giúp bao quát cả trường hợp năm nhuận. Trong phạm vi đề tài, đặc trưng ngày trong năm được xem như thông tin bổ sung về bối cảnh thời gian dài hơn chu kỳ ngày đêm. Ý nghĩa chính của cách mã hóa sin/cos là làm cho biến thời gian phù hợp hơn với bản chất tuần hoàn của dữ liệu thời tiết.

Điều quan trọng là việc sử dụng sin và cos không làm mô hình trở thành một mô hình phi tuyến phức tạp. Các hàm sin/cos chỉ được dùng ở bước tạo đặc trưng đầu vào. Sau khi tính toán, (hour_sin), (hour_cos), (day_sin) và (day_cos) được xem như các biến đầu vào mới. Mô hình vẫn nhân từng biến đầu vào với hệ số hồi quy tương ứng rồi cộng lại. Vì vậy, bản chất của mô hình vẫn là Multiple Linear Regression theo các đặc trưng đã được biến đổi.

Cách dùng sin và cos để biểu diễn đặc trưng thời gian cũng tương đồng với các thành phần Fourier trong dự báo chuỗi thời gian. Giáo trình Forecasting: Principles and Practice trình bày rằng các Fourier terms, gồm các cặp sin và cos, có thể được đưa vào mô hình hồi quy để biểu diễn các chu kỳ hoặc tính mùa vụ của dữ liệu [22]. Điều này cho thấy việc bổ sung sin/cos vào mô hình hồi quy là một cách tạo đặc trưng có cơ sở lý thuyết, không phải một phép thêm tùy ý.

### 2.16.5. Dạng mô hình MLR mở rộng áp dụng trong đề tài

Từ các lập luận trên, mô hình trong đề tài có thể được hiểu là mô hình Multiple Linear Regression cơ bản được mở rộng bằng đặc trưng thời gian chu kỳ. Phần nền tảng của mô hình vẫn là hồi quy tuyến tính đa biến. Phần mở rộng nằm ở việc biến thời gian không được đưa trực tiếp vào công thức dưới dạng số nguyên, mà được mã hóa thành các thành phần sin/cos để phản ánh chu kỳ ngày đêm và chu kỳ theo ngày trong năm.

Dạng tổng quát của mô hình áp dụng trong đề tài có thể viết như sau:

T̂(t+2h) = b₀ + b₁Tₜ + b₂Hₜ + b₃(Pₜ - 1000) + b₄sin(2πh / 24) + b₅cos(2πh / 24) + b₆sin(2πd /
366) + b₇cos(2πd / 366) + β_h | (7)

Trong công thức trên, T̂(t+2h) là nhiệt độ dự báo sau 2 giờ. Ký hiệu (Tₜ) là nhiệt độ hiện tại, (Hₜ ) là độ ẩm tương đối hiện tại, (Pₜ) là áp suất khí quyển hiện tại, (h) là giờ trong ngày và (d) là ngày trong năm. Thành phần ((Pₜ - 1000)) đưa áp suất về dạng lệch quanh mốc tham chiếu 1000 hPa, giúp giá trị áp suất trong công thức gọn hơn. Các hệ số (b₀, b₁, ..., b₇) là các hệ số hồi quy được xác định trong quá trình huấn luyện.

Thành phần (β_h) biểu diễn hệ số hiệu chỉnh theo giờ. Trong phạm vi lý thuyết, thành phần này có thể được hiểu là một hiệu chỉnh bổ sung nhằm hỗ trợ mô hình giảm sai lệch có tính lặp lại theo từng thời điểm trong ngày. Tuy nhiên, giá trị cụ thể của (β_h) và các hệ số hồi quy không trình bày trong mục cơ sở lý thuyết, vì chúng phụ thuộc vào quá trình huấn luyện và triển khai thực tế.

Công thức trên chỉ mô tả dạng mô hình ở mức lý thuyết. Trong hệ thống thực tế, các hệ số của mô hình được huấn luyện trước từ dữ liệu lịch sử, sau đó được nhúng vào firmware của ESP32-S3 Gateway. Khi gateway nhận dữ liệu mới từ trạm đo, gateway chỉ thực hiện quá trình suy luận bằng cách tính các đặc trưng đầu vào, thay vào công thức hồi quy và tạo ra giá trị nhiệt độ dự báo sau 2 giờ.

Như vậy, mô hình trong đề tài không phải là mô hình học sâu, không phải mô hình khí tượng số và cũng không phải một hệ thống nowcasting đầy đủ. Đây là mô hình Multiple Linear Regression được mở rộng bằng đặc trưng thời gian chu kỳ. Cách tiếp cận này kế thừa nền tảng MLR đã được sử dụng trong nghiên cứu dự báo nhiệt độ, đồng thời bổ sung biểu diễn thời gian bằng sin/cos để phù hợp hơn với dữ liệu nhiệt độ cục bộ có tính tuần hoàn theo ngày đêm.

### CHƯƠNG 3. PHÂN TÍCH YÊU CẦU VÀ THIẾT KẾ HỆ THỐNG

### 3.1. Định hướng thiết kế hệ thống

Hệ thống quan trắc thời tiết cục bộ được thiết kế nhằm thu thập dữ liệu môi trường tại vị trí quan trắc, truyền dữ liệu không dây về bộ trung tâm, xử lý dữ liệu, lưu trữ trên nền tảng trực tuyến và hiển thị thông tin cho người dùng thông qua giao diện giám sát. Do hệ thống cần hoạt động trong điều kiện ngoài trời và không phụ thuộc hoàn toàn vào nguồn điện cố định, kiến trúc thiết kế phải bảo đảm ba yêu cầu quan trọng: thiết bị đo có khả năng vận hành độc lập, dữ liệu truyền giữa các khối phải có cấu trúc rõ ràng và tầng giám sát phải có khả năng theo dõi trạng thái vận hành của hệ thống.

Theo định hướng trên, hệ thống được chia thành ba thành phần chính: STM32 Sensor Node, ESP32-S3 Gateway và Supabase Cloud/Web Dashboard. STM32 Sensor Node là thiết bị đặt tại vị trí quan trắc, đảm nhiệm nhiệm vụ gần phần cứng như đọc cảm biến, giám sát trạng thái nguồn, đóng gói dữ liệu, mã hóa payload và truyền dữ liệu qua LoRa. ESP32-S3 Gateway là bộ trung tâm tiếp nhận dữ liệu từ tuyến LoRa, kiểm tra tính hợp lệ của frame, giải mã dữ liệu, khôi phục giá trị cảm biến, thực hiện xử lý trung gian và gửi dữ liệu lên nền tảng Cloud. Supabase Cloud và Web Dashboard là tầng lưu trữ, quản lý và hiển thị dữ liệu cho người dùng.

Việc tách STM32 Sensor Node và ESP32-S3 Gateway thành hai khối xử lý riêng giúp hệ thống phù hợp hơn với đặc điểm của từng vi điều khiển. STM32F103C8T6 phù hợp với các tác vụ nhúng cơ bản như giao tiếp cảm biến, xử lý dữ liệu theo chu kỳ, điều khiển module LoRa và vận hành ở chế độ tiết kiệm năng lượng. Tuy nhiên, STM32 không phù hợp để trực tiếp đảm nhiệm các tác vụ như WiFi, HTTPS/TLS, BLE provisioning, OTA firmware update hoặc gửi dữ liệu trực tiếp lên Cloud. Ngược lại, ESP32-S3 có WiFi, BLE, bộ nhớ lớn hơn và được hỗ trợ bởi ESP-IDF/FreeRTOS, do đó phù hợp hơn với vai trò gateway xử lý, kết nối mạng và hỗ trợ các chức năng vận hành nâng cao.

Trong kiến trúc này, STM32 Sensor Node không cần xử lý các chức năng liên quan đến Internet, Supabase, dashboard hoặc OTA. Node chỉ tập trung vào việc tạo dữ liệu cảm biến đáng tin cậy và truyền dữ liệu về gateway theo chu kỳ. Cách tổ chức này giúp firmware STM32 đơn giản hơn, giảm số trạng thái cần quản lý và thuận lợi cho việc tối ưu năng lượng. Đồng thời, ESP32-S3 Gateway có thể tập trung vào các tác vụ yêu cầu tài nguyên cao hơn như quản lý WiFi, nhận frame LoRa, xác thực và giải mã dữ liệu, dự báo nhiệt độ, gửi dữ liệu lên Cloud, kiểm tra OTA và gửi heartbeat trạng thái thiết bị.

Về mặt luồng dữ liệu, hệ thống được thiết kế theo hướng dữ liệu đi từ lớp thiết bị đo đến lớp ứng dụng. Dữ liệu ban đầu được tạo tại STM32 Sensor Node từ các cảm biến môi trường và cảm biến giám sát nguồn. Sau đó, dữ liệu được đóng gói thành payload nhị phân, mã hóa và truyền qua LoRa đến ESP32-S3 Gateway. Gateway xử lý frame nhận được, khôi phục dữ liệu về giá trị vật lý, bổ sung thông tin xử lý cục bộ và gửi dữ liệu lên Supabase thông qua HTTPS. Sau khi dữ liệu được lưu trong cơ sở dữ liệu, Web Dashboard truy vấn và hiển thị thông tin cho người dùng.

Bên cạnh luồng dữ liệu cảm biến, hệ thống còn có các luồng vận hành phụ để hỗ trợ triển khai thực tế. Gateway gửi heartbeat định kỳ để cập nhật trạng thái hoạt động lên Cloud. Web Dashboard hỗ trợ theo dõi dữ liệu mới nhất, biểu đồ lịch sử, trạng thái gateway, trạng thái tuyến LoRa và thông tin firmware. BLE provisioning được sử dụng để cấu hình WiFi cho gateway khi triển khai ở môi trường mới. OTA firmware update được thiết kế để cập nhật firmware ESP32-S3 Gateway từ xa thông qua Supabase Storage và bảng cấu hình thiết bị.
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

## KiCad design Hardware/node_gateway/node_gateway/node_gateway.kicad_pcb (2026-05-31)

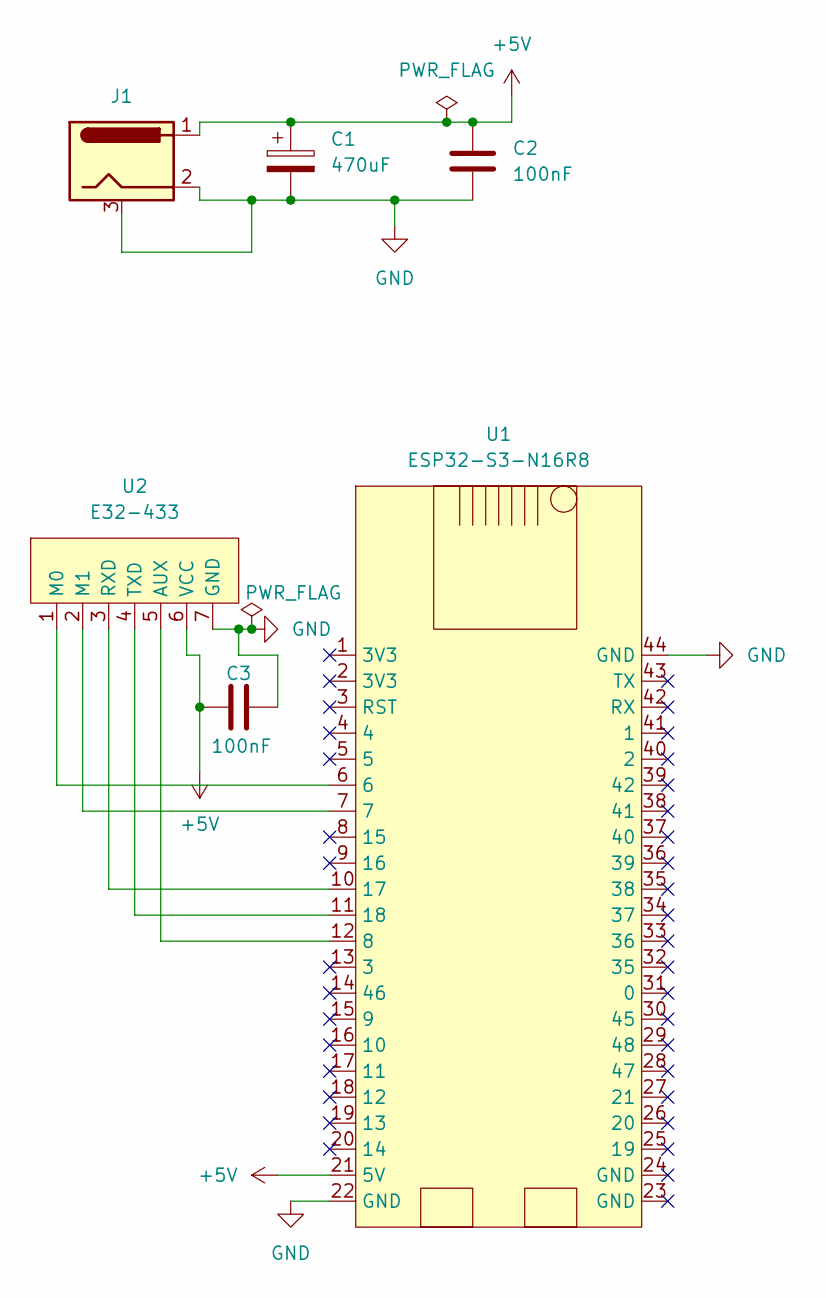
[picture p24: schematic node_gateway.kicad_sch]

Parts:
C1: 470uF; CP_Radial_D8.0mm_P3.0mm
C2, C3: 100nF; C_Disc_D5.0mm_W2.5mm_P5.00mm
J1: Conn_Jack-DC; BarrelJack_GCT_DCJ200-10-A_Horizontal
U1: ESP32-S3-N16R8
U2: E32-433; PinSocket_1x07_P2.54mm_Vertical

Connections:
+5V: C1.1, C2.1, C3.2, J1.1, U1.21 (5V), U2.6 (VCC)
GND: C1.2, C2.2, C3.1, J1.2, J1.3, U1.22 (GND), U1.44 (GND), U2.7 (GND)
unnamed: U1.12 (8), U2.5 (AUX)
unnamed: U1.10 (17), U2.3 (RXD)
unnamed: U1.11 (18), U2.4 (TXD)
unnamed: U1.6, U2.1 (M0)
unnamed: U1.7, U2.2 (M1)

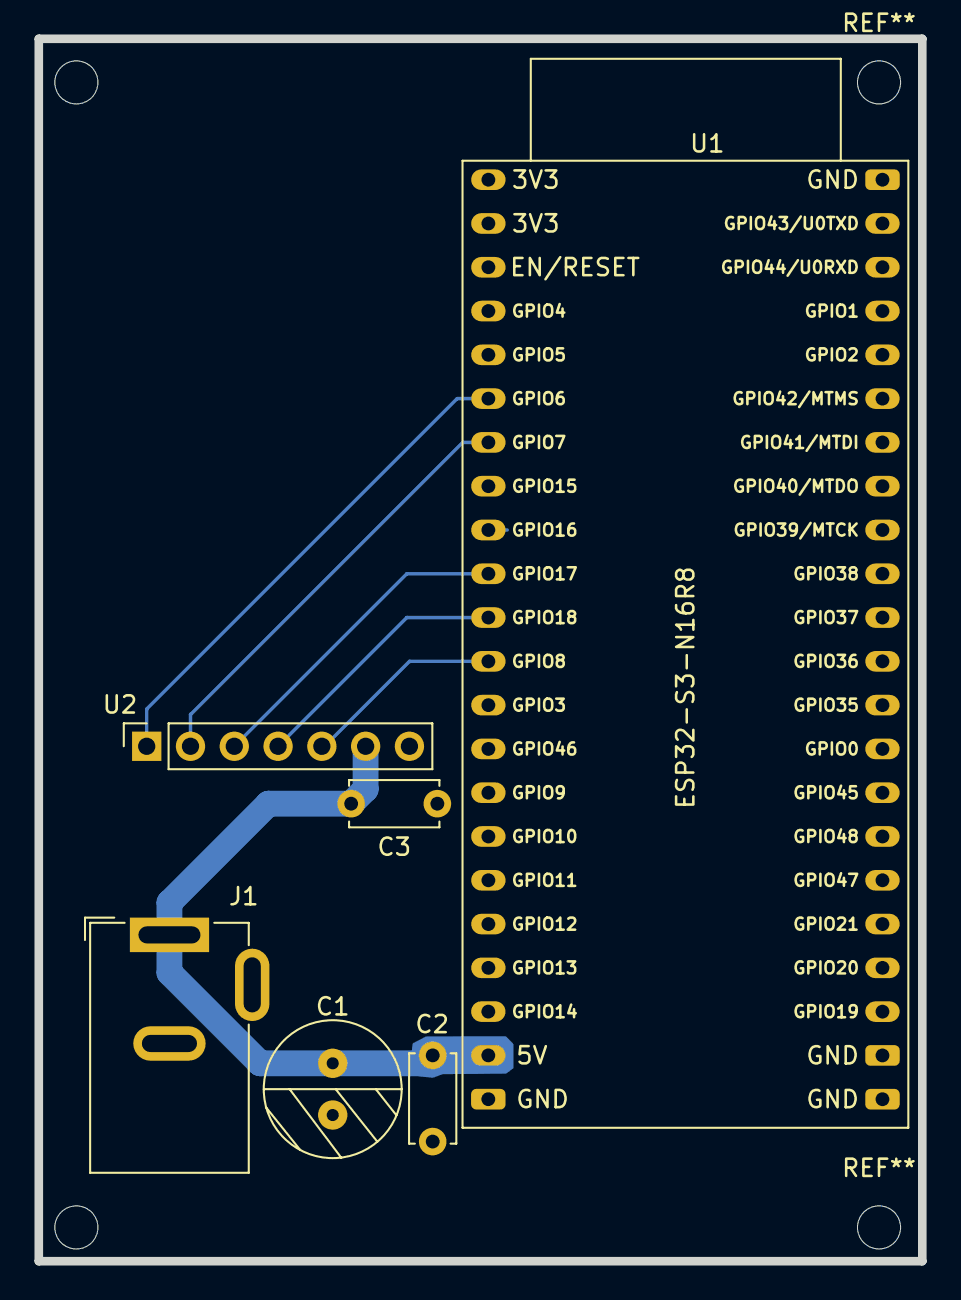
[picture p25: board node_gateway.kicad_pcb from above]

Board: 2 copper layers, 51.3 x 70.9 mm, 6 parts (0 on the bottom side), 7 nets.

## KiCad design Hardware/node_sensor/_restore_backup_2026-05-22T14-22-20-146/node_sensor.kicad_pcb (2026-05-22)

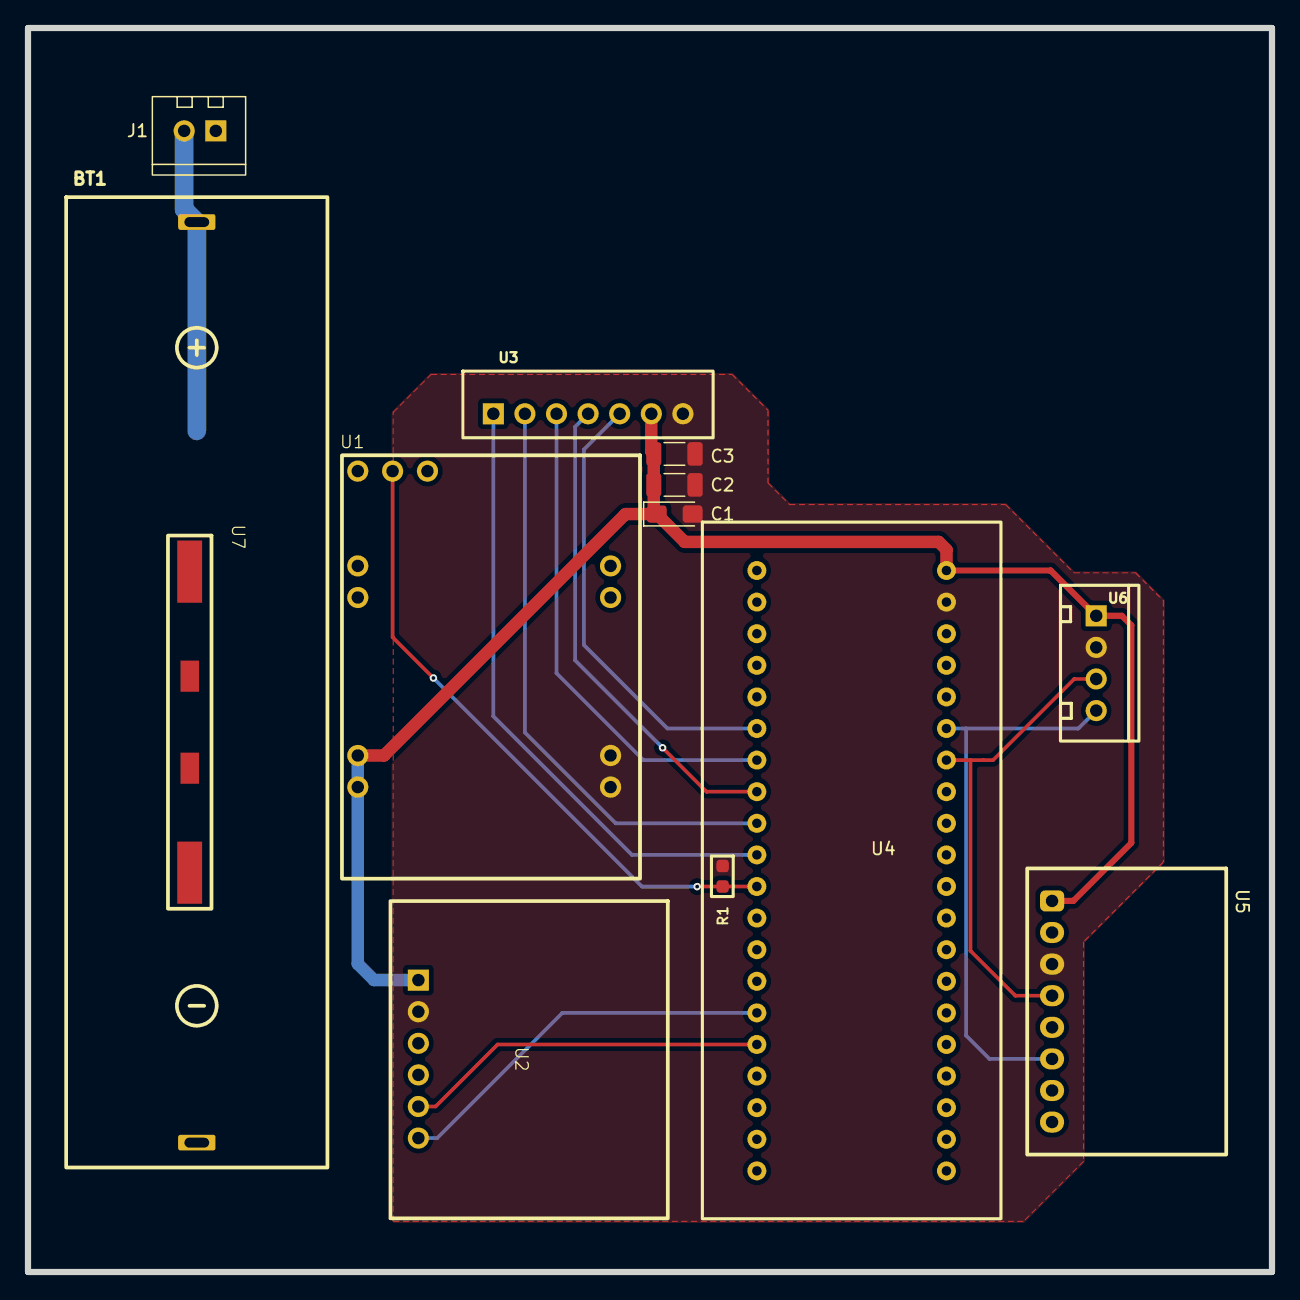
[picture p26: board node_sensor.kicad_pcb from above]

Board: 2 copper layers, 100.0 x 100.0 mm, 13 parts (0 on the bottom side), 14 nets.

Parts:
BT1: Battery_Cell; Battery-18560-1s
C1: 100uF; CP_EIA-3216-18_Kemet-A_HandSolder
C2: 0.1uF; L_1206_3216Metric_Pad1.22x1.90mm_HandSolder
C3: 0.1nF; L_1206_3216Metric_Pad1.22x1.90mm_HandSolder
J1: Solar_Pannel; XH 2.54 2Pin Female
R1: 10k; R0603
U1: TPS63020; TPS63020-module
U2: INA219
U3: E32-433; Conn_XH-P2.54mm-7P
U4: DevKitSTM32
U5: BMP-388; BMP388-module
U6: SHT30; Conn_XH-P2.54mm-4P
U7: BMS-1s; BMS-1s-18560

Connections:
+3.3V: C1.1, C2.1, C3.1, U1.7 (VOUT), U2.1 (VCC), U3.6 (VCC), U4.21 (3v3), U5.1 (VIN), U6.1 (VCC)
/PA1: U3.5 (AUX), U4.6 (PA1)
/PA2: U3.3 (RXD), U4.7 (PA2)
/PA3: U3.4 (TXD), U4.8 (PA3)
/PA4: U3.2 (M1), U4.9 (PA4)
/PA5: U3.1 (M0), U4.10 (PA5)
/PA6: R1.2, U1.4 (PS/SYNC), U4.11 (PA6)
/PB6: U4.27 (PB6), U5.4 (SCK), U6.3 (SCL)
/PB7: U4.26 (PB7), U5.6 (SDI), U6.4 (SDA)
/PB10: U2.6 (SCL), U4.15 (PB10)
/PB11: U2.5 (SDA), U4.16 (PB11)
/Pin+: BT1.1 (+), J1.2, U1.1 (VIN), U1.3 (EN), U2.3 (VIN-), U7.1 (B+)
/Pin-: BT1.2 (-), J1.1, U1.2 (GND), U2.4 (VIN+), U7.2 (B-)
GND: C1.2, C2.2, C3.2, R1.1, U1.6 (GND), U2.2 (GND), U3.7 (GND), U4.22 (GND), U5.3 (GND), U6.2 (GND)

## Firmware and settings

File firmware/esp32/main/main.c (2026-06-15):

/**
 * @file      main.c
 * @brief     Firmware cho Trạm Gateway (ESP32) - Hệ thống Quan trắc Khí tượng IoT
 * @details   Chịu trách nhiệm nhận dữ liệu LoRa, giải mã ASCON-128a, chạy mô hình AI 
 * (Hồi quy tuyến tính đa biến - MLR) dự báo nhiệt độ, và đẩy dữ liệu lên 
 * Supabase qua giao thức HTTPS. Có tích hợp OTA Update.
 * @version   3.8.3.17-production-wifi-ble
 * @date      2026
 */

#include <stdbool.h>
#include <stdint.h>
#include <stdio.h>
#include <stdlib.h>
#include <string.h>
#include <strings.h>
#include <inttypes.h>
#include <time.h>
#include <sys/time.h>
#include <math.h>

/* FreeRTOS Includes */
#include "freertos/FreeRTOS.h"
#include "freertos/task.h"
#include "freertos/event_groups.h"
#include "freertos/timers.h"
#include "freertos/queue.h"

/* ESP-IDF Core Includes */
#include "driver/gpio.h"
#include "driver/uart.h"
#include "esp_err.h"
#include "esp_log.h"
#include "esp_check.h"
#include "sdkconfig.h"
#include "esp_timer.h"
#include "esp_event.h"
#include "nvs_flash.h"
#include "nvs.h"

/* Networking & Cloud Includes */
#include "esp_netif.h"
#include "esp_wifi.h"
#include "esp_http_client.h"
#include "esp_https_ota.h"
#include "esp_ota_ops.h"
#include "esp_partition.h"
#include "esp_crt_bundle.h"
#include "esp_sntp.h"
#include "esp_task_wdt.h"
#include "esp_mac.h"
#include "esp_system.h"
#include "esp_idf_version.h"
#include "network_provisioning/manager.h"
#include "network_provisioning/scheme_ble.h"

/* External Libraries */
#include "cJSON.h"
#include <bootloader_common.h>
#include "crypto_aead.h"
#include "mlr_engine.h"

static const char *TAG = "WEATHER_GATEWAY";

/* ==============================================================================
 * 1. CẤU HÌNH PHẦN CỨNG (HARDWARE CONFIGURATION)
 * ============================================================================== */

/** @defgroup Pinout Cấu hình chân UART và GPIO điều khiển LoRa E32 */
#define E32_UART_NUM          UART_NUM_2
#define E32_UART_TX_PIN       GPIO_NUM_17
#define E32_UART_RX_PIN       GPIO_NUM_18
#define E32_M0_PIN            GPIO_NUM_6
#define E32_M1_PIN            GPIO_NUM_7
#define E32_AUX_PIN           GPIO_NUM_8

/** @defgroup LoRa_Frame Cấu hình khung truyền dữ liệu LoRa */
#define E32_FRAME_LEN         18    /**< Tổng chiều dài khung truyền LoRa (bytes) */
#define E32_FRAME_IDLE_MS     150   /**< Thời gian timeout để nhận biết kết thúc khung */
#define SENSOR_PLAINTEXT_LEN  10    /**< Kích thước dữ liệu gốc chưa mã hóa */
#define ASCON_TAG4_LEN        4     /**< Tag LoRa legacy STM32 -> ESP32: giữ 4 byte để không phá node STM32 hiện tại */
#define ASCON_INPUT_LEN       (SENSOR_PLAINTEXT_LEN + ASCON_TAG4_LEN)

/*
 * ASCON Cloud tag ESP32 -> Edge Function:
 * - Tăng lên full 16 byte để chống giả mạo/sửa gói mạnh hơn.
 * - LoRa vẫn giữ tag4 ở bản này để không đổi frame STM32.
 * - payload_key2 = ciphertext 10 byte + tag16 16 byte = 26 byte = 52 hex.
 */
#define ASCON_CLOUD_TAG_LEN        16
#define ASCON_CLOUD_INPUT_LEN      (SENSOR_PLAINTEXT_LEN + ASCON_CLOUD_TAG_LEN)
#define ASCON_CLOUD_HEX_LEN        (ASCON_CLOUD_INPUT_LEN * 2)

/** @defgroup LoRa_Reg Các thanh ghi cấu hình LoRa E32-433T30D */
#define E32_CFG_ADDH          0x00
#define E32_CFG_ADDL          0x17
#define E32_CFG_SPEED         0x3A
#define E32_CFG_CHAN          0x17
#define E32_CFG_OPTION        0x44
#define E32_CMD_WRITE_FLASH   0xC0
#define E32_CMD_READ_CONFIG    0xC1

/*
 * E32 UART baudrate:
 * - CONFIG_BAUD: baud dùng để nói chuyện với module khi vào Sleep/Config mode.
 *   E32 mới hoặc reset factory thường là 9600.
 * - RUN_BAUD: baud sau khi ghi E32_CFG_SPEED = 0x3A.
 */
#define E32_CONFIG_BAUD       9600
#define E32_RUN_BAUD          115200
#define E32_CFG_PACKET_LEN    6
#define E32_AUX_TIMEOUT_MS    1500

/* Bật log raw UART để debug lúc chưa nhận được gói LoRa. Khi chạy thật để 0 để giảm tải log. */
#define LORA_DEBUG_RAW_RX     0

/*
 * RAM-only replay check:
 * - Phù hợp với quy trình demo/lab: reset cả STM32 + ESP32 + DB thì counter bắt đầu lại từ 0.
 * - Không lưu NVS để tránh kẹt khi bạn chủ động reset toàn bộ hệ thống.
 * - Nếu chỉ reset STM32 mà không reset ESP32, counter STM32 về 0 sẽ bị bỏ; khi đó tạm đổi về 0 để debug.
 */
#define LORA_ENABLE_RAM_REPLAY_CHECK 1

/* ==============================================================================
 * 2. CẤU HÌNH MẠNG VÀ ĐÁM MÂY (NETWORK & CLOUD CONFIG)
 * ============================================================================== */

/**
 * @brief Phiên bản firmware hiện tại.
 * @note  Luôn cập nhật khi thay đổi logic lớn để web/gateway_status theo dõi đúng.
 */
#define GW_VERSION                 "3.8.3.17-production-wifi-ble"
#define DEVICE_ID                  "ESP32_LORA_GW"
#define APP_TIMEZONE_POSIX         "ICT-7"   /* POSIX TZ: ICT-7 = UTC+7 */

/**
 * @brief BLE WiFi Provisioning.
 *
 * Lần đầu boot hoặc chưa có credential trong NVS:
 *   - Gateway quảng bá BLE với tên WSN-GW-xxxxxx.
 *   - Dùng app ESP BLE Provisioning để quét, chọn WiFi, nhập password.
 *   - Credential được lưu vào NVS của WiFi driver.
 */
#define WIFI_PROV_POP              "duck27005"
#define WIFI_PROV_SERVICE_PREFIX   "WSN-GW"
#define WIFI_PROV_WAIT_MS          (0UL)      /* 0 = production: BLE provisioning chờ vô hạn, không timeout */
#define WIFI_MAX_RETRY             5

/* Production: không dùng hardcoded fallback. Nếu WiFi sai/mất NVS -> giữ BLE để nhập lại. */
#define APP_ENABLE_HARDCODED_WIFI_FALLBACK  0

static int  s_wifi_retry_count = 0;
static bool s_wifi_using_fallback = false;
static bool s_ble_prov_active = false;
static bool s_wifi_connect_allowed = false;
static bool s_wifi_connected = false;
static bool s_prov_mgr_ready = false;
static bool s_mqtt_enabled = false;
static bool s_mqtt_connected = false;
static char s_mqtt_broker[96] = "";
static char s_ip_addr[20] = "0.0.0.0";
static EventGroupHandle_t s_wifi_event_group = NULL;

#define WIFI_CONNECTED_BIT         BIT0
#define WIFI_FAIL_BIT              BIT1

/** @defgroup Supabase Cấu hình Supabase / Edge Function */
#define SUPABASE_URL      "https://hbuluhjjfivezrrxesaz.supabase.co"
#define EDGE_FUNCTION_URL "https://hbuluhjjfivezrrxesaz.supabase.co/functions/v1/ingest-weather"

/*
 * Token này phải giống Supabase Secret: INGEST_DEVICE_TOKEN.
 * Không dùng service_role key trong firmware.
 */
#define INGEST_DEVICE_TOKEN "CHANGE_THIS_LONG_RANDOM_DEVICE_TOKEN"

/* Chỉ dùng anon key cho SELECT OTA config. Không dùng để INSERT weather_logs. */
#define SUPABASE_ANON_KEY \
    "eyJhbGciOiJIUzI1NiIsInR5cCI6IkpXVCJ9." \
    "eyJpc3MiOiJzdXBhYmFzZSIsInJlZiI6ImhidWx1" \
    "aGpqZml2ZXpycnhlc2F6Iiwicm9sZSI6ImFub24i" \
    "LCJpYXQiOjE3Nzg1MDE4MDksImV4cCI6MjA5NDA3" \
    "NzgwOX0.KhjB0T-8Yy34P3p37XipEutwVfraabsG274NL_88J4Q"

#define HTTP_POST_TIMEOUT_MS       10000
#define HTTP_GET_TIMEOUT_MS        10000
#define HTTP_OTA_TIMEOUT_MS        60000
#define GATEWAY_STATUS_PERIOD_MS   60000

/*
 * OTA fast-check:
 * - Không đợi 45 giây như bản cũ.
 * - ESP32 kiểm tra device_configs mỗi 5 giây sau khi WiFi/NTP sẵn sàng.
 * - Quá trình OTA dùng esp_https_ota_begin/perform/finish để có thể yield,
 *   tránh Task Watchdog khi ghi flash lâu.
 */
#define OTA_BOOT_DELAY_MS          3000
#define OTA_CHECK_PERIOD_MS        5000
#define OTA_FAIL_BACKOFF_MS        30000
#define OTA_URL_MAX_LEN            512
#define OTA_HTTP_RX_BUFFER_SIZE    8192
#define OTA_HTTP_TX_BUFFER_SIZE    2048
#define SHA256_HEX_LEN             64
static char s_running_sha256_hex[SHA256_HEX_LEN + 1] = {0};
static volatile bool s_ota_in_progress = false;
static volatile int s_http_in_flight = 0;
static portMUX_TYPE s_http_ota_mux = portMUX_INITIALIZER_UNLOCKED;

/* @brief Nhúng Root CA trực tiếp để bảo mật TLS khi gọi HTTPS */
extern const char supabase_root_ca_pem_start[] asm("_binary_supabase_root_ca_pem_start");
extern const char supabase_root_ca_pem_end[]   asm("_binary_supabase_root_ca_pem_end");

/* ==============================================================================
 * 3. CẤU TRÚC DỮ LIỆU & BẢO MẬT (DATA STRUCTS & SECURITY)
 * ============================================================================== */

/** @brief Khóa bí mật dùng chung giữa STM32 và ESP32 cho ASCON-128a */
static const uint8_t ASCON_SECRET_KEY[16] = {
    0x2B, 0x7E, 0x15, 0x16, 0x28, 0xAE, 0xD2, 0xA6,
    0xAB, 0xF7, 0x15, 0x88, 0x09, 0xCF, 0x4F, 0x3C
};

/**
 * @brief Khóa ASCON key2 dùng riêng cho ESP32 -> Edge Function.
 * @note  Supabase Secret phải là ASCON_KEY2_HEX=668ab13302c94de19f7021a85cd47710
 */
static const uint8_t ASCON_CLOUD_KEY2[16] = {
    0x66, 0x8A, 0xB1, 0x33, 0x02, 0xC9, 0x4D, 0xE1,
    0x9F, 0x70, 0x21, 0xA8, 0x5C, 0xD4, 0x77, 0x10
};

/** @defgroup Sensor_Flags Cờ báo lỗi phần cứng cảm biến */
#define ERR_SHT30   (1U << 0)
#define ERR_BMP388  (1U << 1)
#define ERR_VBAT    (1U << 2)

/**
 * @brief Cấu trúc dữ liệu thô (nén) nhận từ STM32
 */
typedef struct __attribute__((packed)) {
    int16_t  env_temp_raw;
    uint16_t env_hum_raw;
    uint16_t air_press_raw;
    int16_t  board_temp_raw;
    uint8_t  batt_volt_raw;
    uint8_t  health_flag;
} SensorPayloadRaw_t;

/**
 * @brief Cấu trúc dữ liệu sau khi giải mã và phục hồi giá trị thực (float)
 */
typedef struct {
    uint32_t frame_counter;
    float    env_temp_c;
    float    env_humidity_pct;
    float    air_pressure_hpa;
    float    board_temp_c;      
    float    battery_volt;
    float    predicted_temp_2h;
    bool     predicted_ok;
    uint8_t  plaintext[SENSOR_PLAINTEXT_LEN];
    uint8_t  health_flag;       
    bool     sht30_ok;
    bool     bmp388_ok;
    bool     payload_ok;
    bool     ina219_ok;
} SensorDecodedData_t;

/* ==============================================================================
 * 4. HÀNG ĐỢI (QUEUES) VÀ AI MODEL (MLOps)
 * ============================================================================== */

/**
 * @brief Cấu trúc điểm dữ liệu đưa vào mô hình AI
 */
typedef struct {
    float pressure;
    float humidity;
    float temperature;
} AI_DataPoint_t;

static QueueHandle_t s_supabase_queue = NULL;     /**< Hàng đợi nạp data chờ gửi lên Cloud */

static float g_mlr_predicted_temp_2h = 0.0f;      /**< Lưu trữ kết quả dự báo nhiệt độ 2 giờ tới */

#if LORA_ENABLE_RAM_REPLAY_CHECK
static uint32_t s_last_frame_counter = 0;
static bool s_have_last_frame_counter = false;
#endif

/* ==============================================================================
 * 5. CÁC HÀM TIỆN ÍCH (UTILITIES)
 * ============================================================================== */

/**
 * @brief Cấu hình Client HTTP sử dụng chứng chỉ gốc (Root CA) đã nhúng.
 * @param cfg Con trỏ trỏ tới cấu trúc cấu hình HTTP.
 */
static void tls_cfg_fill(esp_http_client_config_t *cfg) {
    cfg->cert_pem = supabase_root_ca_pem_start;
    cfg->crt_bundle_attach = NULL; // Tắt bundle hệ thống, dùng chứng chỉ Custom
}

/**
 * @brief Lấy thời gian hệ thống tính bằng mili-giây.
 * @return Thời gian hiện tại (ms).
 */
static int64_t now_ms(void) { 
    return esp_timer_get_time() / 1000LL; 
}

static bool app_time_is_valid(void) {
    time_t now = 0;
    struct tm t = {0};

    time(&now);
    localtime_r(&now, &t);

    return t.tm_year >= (2023 - 1900);
}

static bool http_try_begin(const char *log_tag) {
    bool allow = false;

    portENTER_CRITICAL(&s_http_ota_mux);
    if (!s_ota_in_progress) {
        s_http_in_flight++;
        allow = true;
    }
    portEXIT_CRITICAL(&s_http_ota_mux);

    if (!allow) {
        ESP_LOGW(TAG, "[%s] Skip POST vì OTA đang chạy.", log_tag);
    }

    return allow;
}

static void http_end(void) {
    portENTER_CRITICAL(&s_http_ota_mux);
    if (s_http_in_flight > 0) {
        s_http_in_flight--;
    }
    portEXIT_CRITICAL(&s_http_ota_mux);
}

static int http_in_flight_get(void) {
    int n = 0;

    portENTER_CRITICAL(&s_http_ota_mux);
    n = s_http_in_flight;
    portEXIT_CRITICAL(&s_http_ota_mux);

    return n;
}

static void ota_set_in_progress(bool in_progress) {
    portENTER_CRITICAL(&s_http_ota_mux);
    s_ota_in_progress = in_progress;
    portEXIT_CRITICAL(&s_http_ota_mux);
}

/**
 * @brief Chuyển đổi giá trị ADC thô (0-255) thành điện áp thực (Volts).
 * @param raw Giá trị ADC thô đo từ pin.
 * @return Điện áp pin tính bằng Volts (Dải 3.0V -> 4.2V).
 */
static inline float battery_raw_to_volt(uint8_t raw) {
    return 3.0f + ((float)raw / 255.0f) * (4.2f - 3.0f);
}

static void build_nonce_from_counter(uint32_t c, uint8_t n[16]);

static void app_set_timezone_utc7(void) {
    setenv("TZ", APP_TIMEZONE_POSIX, 1);
    tzset();
}

static void app_log_time_now(const char *prefix) {
    time_t now = 0;
    struct tm utc = {0};
    struct tm local = {0};

    time(&now);
    gmtime_r(&now, &utc);
    localtime_r(&now, &local);

    ESP_LOGI(TAG,
             "%s UTC=%04d-%02d-%02d %02d:%02d:%02d | LOCAL=%04d-%02d-%02d %02d:%02d:%02d | hour=%d doy=%d TZ=%s",
             prefix,
             utc.tm_year + 1900, utc.tm_mon + 1, utc.tm_mday, utc.tm_hour, utc.tm_min, utc.tm_sec,
             local.tm_year + 1900, local.tm_mon + 1, local.tm_mday, local.tm_hour, local.tm_min, local.tm_sec,
             local.tm_hour, local.tm_yday + 1, APP_TIMEZONE_POSIX);
}

static int app_get_wifi_rssi(void) {
    wifi_ap_record_t ap = {0};
    if (s_wifi_connected && esp_wifi_sta_get_ap_info(&ap) == ESP_OK) {
        return ap.rssi;
    }
    return 0;
}

static void bytes_to_hex(const uint8_t *in, size_t len, char *out, size_t out_len) {
    static const char hex[] = "0123456789abcdef";
    if (out_len < (len * 2 + 1)) {
        if (out_len > 0) out[0] = '\0';
        return;
    }
    for (size_t i = 0; i < len; ++i) {
        out[i * 2]     = hex[(in[i] >> 4) & 0x0F];
        out[i * 2 + 1] = hex[in[i] & 0x0F];
    }
    out[len * 2] = '\0';
}

static float app_predict_temp_2h(float temperature, float humidity, float pressure) {
    time_t now = 0;
    struct tm timeinfo = {0};

    time(&now);
    localtime_r(&now, &timeinfo);

    int local_hour = timeinfo.tm_hour;
    int day_of_year = timeinfo.tm_yday + 1;

    float pred = mlr_engine_predict_2h(
        temperature,
        humidity,
        pressure,
        local_hour,
        day_of_year
    );

    ESP_LOGI(TAG,
             "[MLR_TIME] local=%04d-%02d-%02d %02d:%02d:%02d | hour=%d doy=%d | pred=%.2f°C",
             timeinfo.tm_year + 1900,
             timeinfo.tm_mon + 1,
             timeinfo.tm_mday,
             timeinfo.tm_hour,
             timeinfo.tm_min,
             timeinfo.tm_sec,
             local_hour,
             day_of_year,
             pred);

    return pred;
}

/* ==============================================================================
 * 6. MLR FORECAST
 * ==============================================================================
 * v3.8.3.15:
 * - Không dùng AI task riêng nữa.
 * - MLR được tính đồng bộ ngay khi nhận LoRa frame trong process_frame().
 * - Giữ nguyên app_predict_temp_2h().
 */

/* ==============================================================================
 * 7. NHIỆM VỤ ĐÁM MÂY VÀ GIAO TIẾP MẠNG (CLOUD & NETWORKING)
 * ============================================================================== */

/**
 * @brief POST JSON lên Supabase Edge Function ingest-weather.
 * @note  Không dùng anon INSERT. Edge Function dùng service_role để ghi DB.
 */
static esp_err_t edge_post_json(const char *json_body, const char *log_tag) {
    if (!s_wifi_connected) {
        ESP_LOGW(TAG, "[%s] Bỏ qua POST vì WiFi chưa connected.", log_tag);
        return ESP_ERR_WIFI_NOT_CONNECT;
    }

    if (!http_try_begin(log_tag)) {
        return ESP_ERR_INVALID_STATE;
    }

    esp_http_client_config_t http_cfg = {
        .url               = EDGE_FUNCTION_URL,
        .method            = HTTP_METHOD_POST,
        .timeout_ms        = HTTP_POST_TIMEOUT_MS,
        .buffer_size       = 4096,
        .buffer_size_tx    = 2048,
        .keep_alive_enable = true,
    };
    tls_cfg_fill(&http_cfg);

    esp_http_client_handle_t client = esp_http_client_init(&http_cfg);
    if (!client) {
        ESP_LOGE(TAG, "[%s] Khởi tạo HTTP client thất bại.", log_tag);
        http_end();
        return ESP_FAIL;
    }

    esp_http_client_set_header(client, "Content-Type", "application/json");
    esp_http_client_set_header(client, "x-device-token", INGEST_DEVICE_TOKEN);
    esp_http_client_set_post_field(client, json_body, strlen(json_body));

    esp_err_t err = esp_http_client_perform(client);
    int status = esp_http_client_get_status_code(client);

    if (err == ESP_OK && status >= 200 && status < 300) {
        ESP_LOGI(TAG, "[%s] ✅ Edge HTTP %d", log_tag, status);
    } else if (err == ESP_OK) {
        ESP_LOGW(TAG, "[%s] ⚠ Edge HTTP %d. Kiểm tra Edge logs / token / schema.", log_tag, status);
    } else {
        ESP_LOGE(TAG, "[%s] ❌ Edge POST lỗi: %s", log_tag, esp_err_to_name(err));
    }

    esp_http_client_cleanup(client);
    http_end();
    return err;
}
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
void app_main(void) {
    ESP_LOGI(TAG, "================================================");
    ESP_LOGI(TAG, "  TRẠM QUAN TRẮC MLR NOWCASTING (2H FORECAST)  ");
    ESP_LOGI(TAG, "================================================");
    ESP_LOGI(TAG, "[VERSION] GW_VERSION=%s", GW_VERSION);
    ESP_LOGI(TAG, "[TARGET] CONFIG_IDF_TARGET=%s", CONFIG_IDF_TARGET);
    (void)app_update_running_sha256_cache();

    /* 0. NVS dùng cho WiFi provisioning + OTA. */
    app_nvs_init();

    /* 1. Timezone phải set trước khi LoRa/MLR task chạy. */
    app_set_timezone_utc7();
    app_log_time_now("[TIME_BOOT]");

    /* 2. Init MLR trước khi có frame LoRa đầu tiên. */
    mlr_engine_init();

    /* 3. Init GPIO điều khiển LoRa E32 */
    gpio_set_direction(E32_M0_PIN, GPIO_MODE_OUTPUT);
    gpio_set_direction(E32_M1_PIN, GPIO_MODE_OUTPUT);
    gpio_set_direction(E32_AUX_PIN, GPIO_MODE_INPUT);
    gpio_set_pull_mode(E32_AUX_PIN, GPIO_PULLUP_ONLY);

    gpio_set_level(E32_M0_PIN, 0);
    gpio_set_level(E32_M1_PIN, 0);
    vTaskDelay(pdMS_TO_TICKS(100));

    ESP_LOGI(TAG, "[PINOUT] E32_TX(GPIO%d)->RXD_E32, E32_RX(GPIO%d)<-TXD_E32, M0=%d, M1=%d, AUX=%d",
             E32_UART_TX_PIN, E32_UART_RX_PIN, E32_M0_PIN, E32_M1_PIN, E32_AUX_PIN);

    /* 4. Cài đặt UART2 cho LoRa. Ban đầu dùng 9600 để config được module factory. */
    ESP_ERROR_CHECK(uart_driver_install(E32_UART_NUM, 4096, 1024, 0, NULL, 0));
    uart_config_t uc = {
        .baud_rate  = E32_CONFIG_BAUD,
        .data_bits  = UART_DATA_8_BITS,
        .parity     = UART_PARITY_DISABLE,
        .stop_bits  = UART_STOP_BITS_1,
        .flow_ctrl  = UART_HW_FLOWCTRL_DISABLE,
        .source_clk = UART_SCLK_DEFAULT,
    };
    ESP_ERROR_CHECK(uart_param_config(E32_UART_NUM, &uc));
    ESP_ERROR_CHECK(uart_set_pin(E32_UART_NUM, E32_UART_TX_PIN, E32_UART_RX_PIN, UART_PIN_NO_CHANGE, UART_PIN_NO_CHANGE));
    uart_flush_input(E32_UART_NUM);

    /* 5. Cấu hình E32: thử 9600 -> 115200, kiểm tra ACK, sau đó về Normal mode. */
    esp_err_t lora_cfg_result = lora_e32_init_config();
    if (lora_cfg_result != ESP_OK) {
        ESP_LOGW(TAG, "[BOOT] LoRa config chưa xác nhận được. Xem log [LORA_CFG] để kiểm tra phần cứng.");
    }

    /* 6. Tạo queue trước khi bật task nhận LoRa để không rớt dữ liệu. */
    s_supabase_queue = xQueueCreate(20, sizeof(SensorDecodedData_t));
    if (!s_supabase_queue) {
        ESP_LOGE(TAG, "[BOOT] Không tạo được queue Edge. Restart...");
        vTaskDelay(pdMS_TO_TICKS(1000));
        esp_restart();
    }

    /* 7. Bật task LoRa sớm, không chờ WiFi/NTP để tránh bỏ lỡ gói vô tuyến. */
    xTaskCreatePinnedToCore(lora_receiver_task, "LORA_RX_TASK", 8192, NULL, 10, NULL, 0);

    /* 8. WiFi production: NVS credential -> BLE provisioning vô hạn, không hardcoded fallback. */
    wifi_init_ble_provisioning_or_connect();

    while (!s_wifi_connected) {
        EventBits_t bits = xEventGroupWaitBits(
            s_wifi_event_group,
            WIFI_CONNECTED_BIT | WIFI_FAIL_BIT,
            pdFALSE,
            pdFALSE,
            portMAX_DELAY
        );

        if (bits & WIFI_CONNECTED_BIT) {
            break;
        }

        if (bits & WIFI_FAIL_BIT) {
            ESP_LOGE(TAG, "[WIFI] Credential trong NVS kết nối thất bại quá nhiều lần -> chuyển sang BLE provisioning để nhập lại.");
            xEventGroupClearBits(s_wifi_event_group, WIFI_FAIL_BIT);
            ESP_ERROR_CHECK(wifi_start_ble_provisioning_now("WiFi NVS fail. Vui lòng nhập lại WiFi bằng app ESP BLE Provisioning.", true));
        }
    }

    /* 9. Đồng bộ NTP. Nếu fail thì LoRa vẫn chạy, nhưng TLS/MLR theo giờ có thể chưa chuẩn. */
    if (s_wifi_connected) {
        esp_sntp_setoperatingmode(SNTP_OPMODE_POLL);
        esp_sntp_setservername(0, "pool.ntp.org");
        esp_sntp_setservername(1, "time.cloudflare.com");
        esp_sntp_init();

        int retry = 0;
        const int retry_count = 20;
        time_t now = 0;
        struct tm timeinfo = {0};

        while (timeinfo.tm_year < (2023 - 1900) && ++retry < retry_count) {
            ESP_LOGI(TAG, "[NTP] Chờ đồng bộ thời gian từ Internet (%d/%d)...", retry, retry_count);
            vTaskDelay(pdMS_TO_TICKS(2000));
            time(&now);
            localtime_r(&now, &timeinfo);
        }

        if (timeinfo.tm_year >= (2023 - 1900)) {
            app_set_timezone_utc7();
            ESP_LOGI(TAG, "[NTP] ✅ Đồng hồ đã sync chuẩn.");
            app_log_time_now("[TIME_CHECK]");
        } else {
            ESP_LOGE(TAG, "[NTP] ❌ Đồng bộ thời gian thất bại. TLS có thể lỗi nếu đồng hồ sai.");
        }
    }

    /* 10. Bật task cloud/status sau khi network đã init. */
    xTaskCreatePinnedToCore(edge_task, "EDGE_TASK", 8192, NULL, 4, NULL, 0);
    xTaskCreatePinnedToCore(gateway_status_task, "GW_STATUS_TASK", 8192, NULL, 3, NULL, 1);
    xTaskCreatePinnedToCore(ota_task, "OTA_TASK", 8192, NULL, 4, NULL, 1);

    ESP_LOGI(TAG, "[BOOT] Gateway v%s đã chạy. LoRa RX -> Edge Function POST.", GW_VERSION);

    while (1) {
        vTaskDelay(pdMS_TO_TICKS(60000));
    }
}

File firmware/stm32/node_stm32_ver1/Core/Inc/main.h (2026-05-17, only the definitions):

#define LORA_AUX_Pin GPIO_PIN_1
#define LORA_AUX_GPIO_Port GPIOA
#define LORA_TX_Pin GPIO_PIN_2
#define LORA_TX_GPIO_Port GPIOA
#define LORA_RX_Pin GPIO_PIN_3
#define LORA_RX_GPIO_Port GPIOA
#define LORA_M0_Pin GPIO_PIN_4
#define LORA_M0_GPIO_Port GPIOA
#define LORA_M1_Pin GPIO_PIN_5
#define LORA_M1_GPIO_Port GPIOA
#define TPS_PS_SYNC_Pin GPIO_PIN_6
#define TPS_PS_SYNC_GPIO_Port GPIOA
#define SOURCE_SCL_Pin GPIO_PIN_10
#define SOURCE_SCL_GPIO_Port GPIOB
#define SOURCE_SDA_Pin GPIO_PIN_11
#define SOURCE_SDA_GPIO_Port GPIOB
#define Print_TX_Pin GPIO_PIN_9
#define Print_TX_GPIO_Port GPIOA
#define Print_RX_Pin GPIO_PIN_10
#define Print_RX_GPIO_Port GPIOA
#define ENV_SCL_Pin GPIO_PIN_6
#define ENV_SCL_GPIO_Port GPIOB
#define ENV_SDA_Pin GPIO_PIN_7
#define ENV_SDA_GPIO_Port GPIOB

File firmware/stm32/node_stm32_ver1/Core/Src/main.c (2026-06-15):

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
/* Includes ------------------------------------------------------------------*/
#include "main.h"

/* USER CODE BEGIN Includes */

#include "sensor_hal.h"
#include "api.h"
#include "crypto_aead.h"
#include "sensors.h"
#include <string.h>
/* USER CODE END Includes */

/* USER CODE BEGIN PD */

#define SENSOR_POWER_SETTLE_MS      20U
#define SENSOR_MEASURE_WAIT_MS      150U

/*
 * Test mode:
 * - IWDG timeout is about 25s with LSI around 40kHz, prescaler 256, reload 3906.
 * - RTC heartbeat must be lower than IWDG timeout.
 * - TX every 30s = 3 heartbeats x 10s.
 */
#define APP_RTC_HEARTBEAT_SEC       5U
#define APP_TX_PERIOD_SEC           10U
#define APP_TX_HEARTBEATS           (APP_TX_PERIOD_SEC / APP_RTC_HEARTBEAT_SEC)

#define BKP_MAGIC_VALUE             0xA55AU
#define BKP_REG_MAGIC               RTC_BKP_DR1
#define BKP_REG_FRAME_COUNTER_LO    RTC_BKP_DR2
#define BKP_REG_FRAME_COUNTER_HI    RTC_BKP_DR3
#define BKP_REG_HEARTBEAT_COUNT     RTC_BKP_DR4
/* USER CODE END PD */

I2C_HandleTypeDef hi2c1;
I2C_HandleTypeDef hi2c2;

IWDG_HandleTypeDef hiwdg;

RTC_HandleTypeDef hrtc;

UART_HandleTypeDef huart1;
UART_HandleTypeDef huart2;

/* USER CODE BEGIN PV */
static const uint8_t ASCON_SECRET_KEY[16] = {
    0x2B, 0x7E, 0x15, 0x16, 0x28, 0xAE, 0xD2, 0xA6,
    0xAB, 0xF7, 0x15, 0x88, 0x09, 0xCF, 0x4F, 0x3C
};
typedef char check_sensor_payload_size[(sizeof(SensorData_t) == 10U) ? 1 : -1];
typedef char check_lora_frame_size[(sizeof(LoRaTxFrame_t) == 18U) ? 1 : -1];


//static uint32_t g_tx_elapsed_sec = 0U;
static uint32_t g_frame_counter = 0U;
/* USER CODE END PV */

void SystemClock_Config(void);
static void MX_GPIO_Init(void);
static void MX_I2C1_Init(void);
static void MX_I2C2_Init(void);
static void MX_IWDG_Init(void);
static void MX_USART2_UART_Init(void);
//static void MX_USART1_UART_Init(void);
static void MX_RTC_Init(void);
/* USER CODE BEGIN 0 */
static void Error_Handler_Print_And_Stop(const char *msg);
static void debug_dump_hex(const char *prefix, const uint8_t *data, uint16_t len)
{
    uint16_t i;

    if ((prefix == NULL) || (data == NULL)) {
        return;
    }

    sensor_debug_print("%s (%uB):", prefix, (unsigned)len);
    for (i = 0U; i < len; i++) {
        sensor_debug_print(" %02X", data[i]);
    }
    sensor_debug_print("\r\n");
}
/* Hàm phục hồi Bus I2C (Giải cứu cảm biến bị kẹt) */
void I2C_Recover_Bus(GPIO_TypeDef* SCL_Port, uint16_t SCL_Pin, GPIO_TypeDef* SDA_Port, uint16_t SDA_Pin)
{
    GPIO_InitTypeDef GPIO_InitStruct = {0};

    // 1. Cấu hình SCL và SDA thành Output Open-Drain tạm thời
    GPIO_InitStruct.Pin = SCL_Pin | SDA_Pin;
    GPIO_InitStruct.Mode = GPIO_MODE_OUTPUT_OD;
    GPIO_InitStruct.Pull = GPIO_PULLUP;
    GPIO_InitStruct.Speed = GPIO_SPEED_FREQ_HIGH;
    HAL_GPIO_Init(SCL_Port, &GPIO_InitStruct); // Chú ý: Cần Init đúng Port (vd GPIOB)

    HAL_GPIO_WritePin(SCL_Port, SCL_Pin, GPIO_PIN_SET);
    HAL_GPIO_WritePin(SDA_Port, SDA_Pin, GPIO_PIN_SET);
    HAL_Delay(1);

    // 2. Tạo tối đa 9 xung clock trên SCL để ép Slave nhả SDA
    for (int i = 0; i < 9; i++) {
        // Kiểm tra xem chân SDA đã được nhả lên HIGH chưa
        if (HAL_GPIO_ReadPin(SDA_Port, SDA_Pin) == GPIO_PIN_SET) {
            break; // Bus đã rảnh, thoát vòng lặp
        }

        // Kéo SCL xuống LOW rồi lên HIGH (Tạo 1 xung clock)
        HAL_GPIO_WritePin(SCL_Port, SCL_Pin, GPIO_PIN_RESET);
        HAL_Delay(1);
        HAL_GPIO_WritePin(SCL_Port, SCL_Pin, GPIO_PIN_SET);
        HAL_Delay(1);
    }

    // 3. Tạo tín hiệu STOP ảo để reset trạng thái của tất cả Slave
    HAL_GPIO_WritePin(SCL_Port, SCL_Pin, GPIO_PIN_RESET);
    HAL_Delay(1);
    HAL_GPIO_WritePin(SDA_Port, SDA_Pin, GPIO_PIN_RESET);
    HAL_Delay(1);
    HAL_GPIO_WritePin(SCL_Port, SCL_Pin, GPIO_PIN_SET);
    HAL_Delay(1);
    HAL_GPIO_WritePin(SDA_Port, SDA_Pin, GPIO_PIN_SET);
    HAL_Delay(1);
}
static uint8_t lora_cfg_is_target(const uint8_t cfg[6])
{
    return (cfg[0] == 0xC0 &&
            cfg[1] == 0x00 &&
            cfg[2] == 0x17 &&
            cfg[3] == 0x3A &&
            cfg[4] == 0x17 &&
            cfg[5] == 0x44);
}

static void App_Delay_With_Watchdog(uint32_t ms)
{
    uint32_t start = HAL_GetTick();

    while ((HAL_GetTick() - start) < ms) {
        HAL_IWDG_Refresh(&hiwdg);
        HAL_Delay(20);
    }
}

static uint8_t Edge_Crypto_Pack(const SensorData_t *raw_data,
                                uint32_t counter,
                                LoRaTxFrame_t *tx_frame)
{
    uint8_t plaintext[sizeof(SensorData_t)];
    uint8_t ascon_output[sizeof(SensorData_t) + 16U];
    uint8_t nonce[16] = {0};
    unsigned long long clen = 0ULL;
    int ret;

    if ((raw_data == NULL) || (tx_frame == NULL)) {
        return SENSOR_ERR;
    }

    memset(tx_frame, 0, sizeof(*tx_frame));
    memcpy(plaintext, raw_data, sizeof(plaintext));

    nonce[0] = (uint8_t)(counter >> 24);
    nonce[1] = (uint8_t)(counter >> 16);
    nonce[2] = (uint8_t)(counter >> 8);
    nonce[3] = (uint8_t)(counter);

    nonce[4] = 0x57U;
    nonce[5] = 0x53U;
    nonce[6] = 0x4EU;
    nonce[7] = 0x31U;

    ret = crypto_aead_encrypt(
        ascon_output, &clen,
        plaintext, sizeof(plaintext),
        NULL, 0,
        NULL,
        nonce,
        ASCON_SECRET_KEY
    );

    if ((ret != 0) || (clen < ((unsigned long long)sizeof(plaintext) + 4ULL))) {
        sensor_debug_print("[ASCON] Encrypt FAILED, skip TX\r\n");
        return SENSOR_ERR;
    }

    tx_frame->frame_counter = counter;
    memcpy(tx_frame->ciphertext, &ascon_output[0], sizeof(tx_frame->ciphertext));
    memcpy(tx_frame->mac_tag, &ascon_output[sizeof(tx_frame->ciphertext)], sizeof(tx_frame->mac_tag));

    return SENSOR_OK;
}

/* Backup register helpers --------------------------------------------------*/

static void App_Backup_Enable(void)
{
    __HAL_RCC_PWR_CLK_ENABLE();
    __HAL_RCC_BKP_CLK_ENABLE();
    HAL_PWR_EnableBkUpAccess();
}

static uint32_t App_BKP_Read32(uint32_t reg_lo, uint32_t reg_hi)
{
    uint32_t lo = HAL_RTCEx_BKUPRead(&hrtc, reg_lo) & 0xFFFFU;
    uint32_t hi = HAL_RTCEx_BKUPRead(&hrtc, reg_hi) & 0xFFFFU;

    return lo | (hi << 16);
}

static void App_BKP_Write32(uint32_t reg_lo, uint32_t reg_hi, uint32_t value)
{
    HAL_RTCEx_BKUPWrite(&hrtc, reg_lo, value & 0xFFFFU);
    HAL_RTCEx_BKUPWrite(&hrtc, reg_hi, (value >> 16) & 0xFFFFU);
}

static void App_Backup_Init_If_Needed(void)
{
    App_Backup_Enable();

    if (HAL_RTCEx_BKUPRead(&hrtc, BKP_REG_MAGIC) != BKP_MAGIC_VALUE) {
        HAL_RTCEx_BKUPWrite(&hrtc, BKP_REG_MAGIC, BKP_MAGIC_VALUE);
        App_BKP_Write32(BKP_REG_FRAME_COUNTER_LO, BKP_REG_FRAME_COUNTER_HI, 0U);
        HAL_RTCEx_BKUPWrite(&hrtc, BKP_REG_HEARTBEAT_COUNT, 0U);

        sensor_debug_print("[BKP] Init backup registers\r\n");
    }
}

static uint32_t App_FrameCounter_Read(void)
{
    return App_BKP_Read32(BKP_REG_FRAME_COUNTER_LO, BKP_REG_FRAME_COUNTER_HI);
}
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

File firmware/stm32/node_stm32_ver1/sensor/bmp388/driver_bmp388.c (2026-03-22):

/**
 * Copyright (c) 2015 - present LibDriver All rights reserved
 * 
 * The MIT License (MIT)
 *
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
 * @file      driver_bmp388.c
 * @brief     driver bmp388 source file
 * @version   2.0.0
 * @author    Shifeng Li
 * @date      2021-04-12
 *
 * <h3>history</h3>
 * <table>
 * <tr><th>Date        <th>Version  <th>Author      <th>Description
 * <tr><td>2021/04/12  <td>2.0      <td>Shifeng Li  <td>format the code
 * <tr><td>2020/12/20  <td>1.0      <td>Shifeng Li  <td>first upload
 * </table>
 */

#include "driver_bmp388.h"

/**
 * @brief chip information definition
 */
#define CHIP_NAME                 "Bosch BMP388"        /**< chip name */
#define MANUFACTURER_NAME         "Bosch"               /**< manufacturer name */
#define SUPPLY_VOLTAGE_MIN        1.65f                 /**< chip min supply voltage */
#define SUPPLY_VOLTAGE_MAX        3.6f                  /**< chip max supply voltage */
#define MAX_CURRENT               0.8f                  /**< chip max current */
#define TEMPERATURE_MIN           -40.0f                /**< chip min operating temperature */
#define TEMPERATURE_MAX           85.0f                 /**< chip max operating temperature */
#define DRIVER_VERSION            2000                  /**< driver version */
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

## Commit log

2026-03-22 firmware stm32
2026-04-27 board stm32 v1
    [node_sensor.kicad_pcb, node_sensor.kicad_sch]
2026-04-28 deepsleep with 2 bytes frame counter
2026-04-28 stm32 deepsleep+esp32 decode
2026-05-07 completed node_sensor v1.1
    [node_sensor.kicad_pcb, node_sensor.kicad_sch]
2026-05-15 Bỏ theo dõi các file đã được thêm vào .gitignore
2026-05-17 updated OTA,https
    [partitions.csv]
2026-05-17 Fix merge conflicts and ignore ESP32 build artifacts
2026-05-20 fix ntp - ota- tls
    [main.c]
2026-05-20 updated anti-lockup i2c bus feature
2026-05-22 completed v1 node sensor
    [node_sensor-B_Cu.gbr, node_sensor-B_Mask.gbr, node_sensor-B_Paste.gbr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]
2026-05-31 pcb v1 gateway - change mappping gateway
    [node_gateway-B_Cu.gbr, node_gateway-B_Mask.gbr, node_gateway-B_Paste.gbr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]
2026-06-15 updated firmware-web-stm32(test)

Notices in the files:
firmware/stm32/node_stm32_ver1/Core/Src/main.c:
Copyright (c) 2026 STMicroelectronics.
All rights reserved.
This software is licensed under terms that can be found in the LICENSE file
